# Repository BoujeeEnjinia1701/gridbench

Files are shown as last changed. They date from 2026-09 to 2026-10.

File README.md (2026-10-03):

# GridBench

     

**Area:** Advanced Manufacturing · **TRL:** 3 of 9 (proof of concept on paper) · **Value-engineering target:** USD 250 (estimated cost of the constructable design USD 272.20; see Concept) · **Difficulty:** 2 of 5

A modular fixture and workbench standard: a 25 mm hole grid plate with printable and machined clamps, stops and jigs, so community workshops can hold, assemble and test parts repeatably.

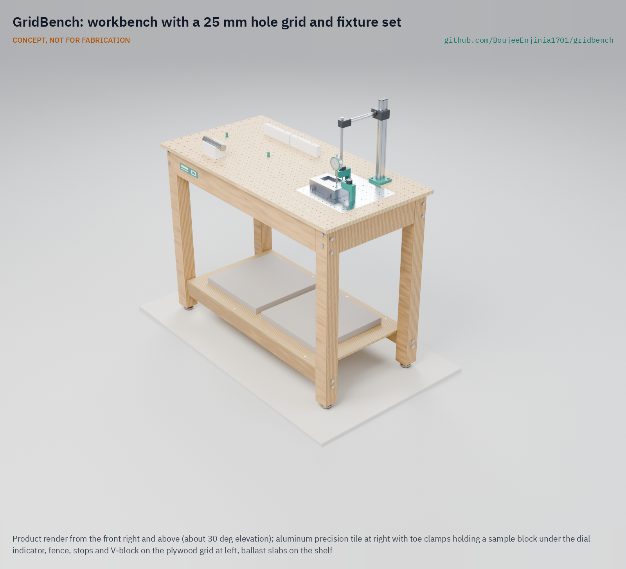
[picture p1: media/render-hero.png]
GridBench: workbench with a 25 mm hole grid and fixture set, product render


[Exploded render](media/render-exploded.png) · [Detail render](media/render-detail.png) · [Interactive 3D model](media/viewer.html) · [Concept blueprint (PDF)](media/concept-blueprint.pdf) · [General arrangement GBN-DWG-001 (PDF)](cad/drawings/GBN-DWG-001.pdf) · [Calculations](docs/04-calcs/01-sizing.md) · [Prototype build plan](docs/05-build-plan.md) · [Design decisions](docs/06-design-decisions.md) · [Review note](docs/REVIEW.md)

## Concept rationale

A shared grid lets jigs designed for one project be reused in any workshop, which is the manufacturing counterpart of the lab's documentation kit, ReadyKit. GridBench adopts the 25 mm, M6 pattern of metric optical breadboards ([RP Photonics](https://www.rp-photonics.com/optical_breadboards.html)) rather than inventing a new one, so commercial accessories fit from day one, and splits the top into a cheap plywood field for area and a small aluminum tile for precision, so precision is paid for only where it is used.

Keeping it open and garage-buildable is the point: a fixture standard only helps if many benches share it. A timber frame, one sheet of plywood, one aluminum plate and printed clamps can be built with a drill press and taps, and each jig can be published as a build123d file that fits any GridBench.

## Burning platform

Most making happens in small firms. Small and medium enterprises are about 90 % of businesses and more than half of employment worldwide ([World Bank](https://www.worldbank.org/ext/en/topic/competitiveness/small-and-medium-enterprises-smes-finance)), and in the United States more than 98 % of the roughly 239,000 manufacturing firms counted in 2022 had fewer than 500 employees ([National Association of Manufacturers, Facts About Manufacturing](https://nam.org/mfgdata/facts-about-manufacturing-expanded/)). These firms rarely own modular fixture systems: a 1,200 x 800 mm fixture table from one leading system starts at about $2,561 before clamps ([Siegmund System 16 listing](https://weldingtablesandfixtures.com/products/4-161025-p-siegmund-1200x800mm-basic-system-16-welding-table)).

Demand for local, repeatable making is rising with repair. The world generated a record 62 million tonnes of e-waste in 2022 and only 22 % was formally recycled ([ITU and UNITAR, Global E-waste Monitor 2024](https://www.itu.int/hub/2024/04/the-world-generated-62-million-tonnes-of-electronic-waste-in-just-one-year-and-recycled-way-too-little-un-agencies-warn/)), and repair and remanufacture depend on holding parts accurately without factory tooling.

## Where it could be used

### By industry

| Industry | Use |
| --- | --- |
| Makerspaces and fab labs | Shared bench where members set up a published jig in minutes; the Fab Lab network alone has over 1,750 labs in 100 countries ([Fab Foundation](https://fabfoundation.org/about/)) |
| Electronics and appliance repair | Holding boards, housings and motors for disassembly, rework and testing with the indicator post |
| Small-batch manufacturing | Drilling, gluing and assembly jigs for runs of 10 to 500 parts |
| Technical education | Teaching datums, location and clamping on a bench students can build |
| Open hardware and research labs | Build and check fixtures shipped with designs; optics and sensor setups on the M6 grid |
| Furniture and joinery | Stops and fences for repeat cuts and drilling on the plywood field |

### By country or region

| Country or region | Why it matters there |
| --- | --- |
| European Union | The repair directive must apply in member states by 31 July 2026, requiring producers to offer repair and spare parts ([European Commission](https://commission.europa.eu/law/law-topic/consumer-protection-law/directive-repair-goods_en)); independent repairers need low-cost, repeatable workholding. |
| United States | More than 98 % of manufacturing firms had fewer than 500 employees in 2022, and about three quarters had fewer than 20 ([National Association of Manufacturers](https://nam.org/mfgdata/facts-about-manufacturing-expanded/)); makerspaces and job shops can share jigs as files. |
| India | MSMEs account for 30.1 % of GDP and 35.4 % of manufacturing ([Press Information Bureau, 2025](https://www.pib.gov.in/PressReleasePage.aspx?PRID=2142170&reg=48&lang=2)); consistent quality helps small units supply larger buyers. |
| Ghana | Suame Magazine in Kumasi, an artisan engineering cluster, had over 80,000 people working in it by 2018 ([Adu-Gyamfi and Adjei, AfricaLics working paper](https://openair.africa/wp-content/uploads/2018/09/WP-16.pdf)); shared jigs could make artisan-made parts interchangeable. |
| Kenya | Informal sector employment grew 4.5 % in 2023, faster than formal wage employment at 4.1 % ([Kenya National Bureau of Statistics, Economic Survey 2024, popular version](https://www.knbs.or.ke/wp-content/uploads/2024/05/2024-Economic-Survey-Popular-Version.pdf)); jua kali workshops make parts with hand tools and could build the bench locally. |

## What sparked the idea

The idea traces back to Paris in 1785, when Thomas Jefferson, then the US minister to France, was shown the work of the gunsmith Honoré Blanc. Jefferson wrote to John Jay that he was handed the parts of 50 musket locks sorted into compartments, put several locks together himself from parts picked at random, and found that they fitted perfectly ([Jefferson to Jay, 30 August 1785, Founders Online](https://founders.archives.gov/documents/Jefferson/01-08-02-0354)). Jefferson added that Blanc achieved this "by tools of his own contrivance," which also shortened the work, and that the advantages when arms need repair were evident (same letter). Repeatability came from purpose-made tooling rather than from a large factory, which is still the situation of a small workshop today. What such workshops lack is a common base on which those fixtures can be shared, and GridBench is an attempt to supply one.

## Problem

Repeatable building needs repeatable fixturing, and commercial modular fixture systems are costly while improvised jigs are one-off. Problem statement: [docs/01-problem.md](docs/01-problem.md).

## Concept

A 1,200 x 600 mm workbench with a 25 mm, M6 hole grid: a plywood field with tee nuts and threaded inserts for general holding, a flush 300 x 300 mm aluminum precision tile with dowel bores for repeatable location, printed clamps, stops and V-blocks, and an instrument post with a user-supplied dial indicator to check parts in place. Two concrete slabs on the shelf keep it from tipping and rubber-padded feet keep it from sliding. The TRL 3 calculations ([GBN-CAL-001](docs/04-calcs/01-sizing.md)) find 7 of 12 requirements met on paper or by design. Value-engineering target: USD 250; estimated cost of the constructable design: USD 272.20 (USD 22.20 over the target). Clamp hold-down is met at the tee-nut positions and on the tile but not at the 122 screw-in insert positions over the frame; Amish decided on 2026-10-02 to rate those light duty at 0.92 N·m and mark them on the worktop with a contrasting paint ring, and the shelf is now screwed down to the low rails against racking. The recommendations Amish accepted on 2026-09-25 are recorded in [GBN-DDR-002](docs/decisions/0002-recommendations-accepted.md), and the changes that make the design buildable in [GBN-DDR-003](docs/decisions/0003-design-for-construction.md).

Full design precis: [docs/02-concept.md](docs/02-concept.md) · Requirements: [docs/03-requirements.md](docs/03-requirements.md) · Decisions: [DDR-001](docs/decisions/0001-trl2-review-decisions.md), [DDR-002](docs/decisions/0002-recommendations-accepted.md), [DDR-003](docs/decisions/0003-design-for-construction.md), [register](docs/06-design-decisions.md) · Model: [cad/src/model.py](cad/src/model.py)

## Key components

- Bolted timber bench frame (M8 bolts and cross dowels) with 45 x 120 mm aprons, rubber-padded levelling feet and a lower shelf
- 18 mm plywood grid worktop, 25 mm pitch, M6 flanged tee nuts (screw-in inserts over the frame) on a 50 mm sub-grid
- Aluminum precision tile, 300 x 300 mm, 144 M6 holes and 9 dowel bores 8 mm H7
- Hardened 8 mm locating pins, one round and one diamond per precision fixture
- Printable clamp, stop, fence and V-block library (every part fits a 200 x 200 mm print bed)
- Instrument post for a 0.01 mm dial indicator (user-supplied)
- Two concrete ballast slabs on the shelf; optional wall anchor brackets

The priced bill of materials (17 lines) is in [bom/bom.csv](bom/bom.csv).

## Building the prototype

The [prototype build plan](docs/05-build-plan.md) (GBN-BLD-001) shows how to make each of the 20 components and put the bench together in 15 steps, with a making sketch for every made part and a picture for every joint and step, all drawn from the model. The frame is sawn and drilled softwood joined with M8 bolts and cross dowels, the worktop is drilled plywood, the tile is drilled, reamed and tapped aluminium plate, and the fixtures are printed in PETG on a 200 x 200 mm bed. Making the design buildable changed some details of the concept, recorded in [GBN-DDR-003](docs/decisions/0003-design-for-construction.md); decisions still open are in the [design decisions register](docs/06-design-decisions.md). It is a plan: nothing has been built yet.

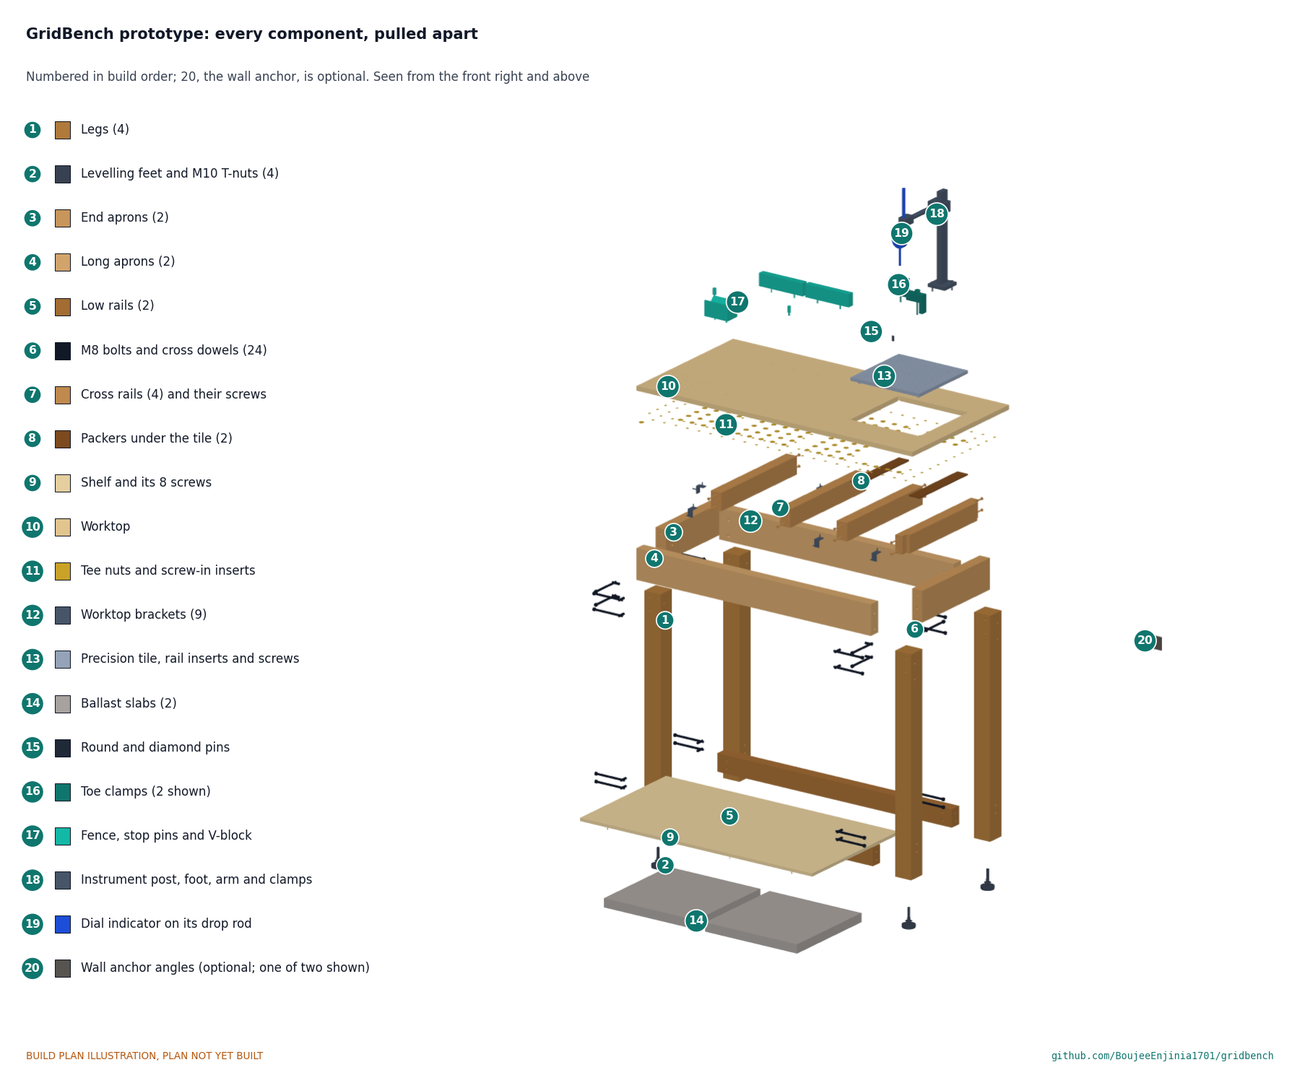
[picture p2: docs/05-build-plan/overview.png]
GridBench prototype: every component, pulled apart and numbered in build order


## Safety

> Drilling, tapping and clamping create chip, projectile and pinch hazards: wear eye protection and secure work before cutting. The empty bench tips at about 117 N at the top edge (estimate); place both ballast slabs on the shelf or anchor it to a wall before use. Printed clamps can crack under overload; respect the rated screw torque of 1.6 N·m. Not for welding or hot work.

## Repository layout

| Folder | Contents |
| --- | --- |
| `docs/` | Problem, concept, requirements, calculations and design decisions |
| `cad/src/` | build123d Python source, the source of truth for all geometry |
| `cad/step/`, `cad/stl/` | Exported models for FreeCAD, other CAD tools and printing |
| `cad/drawings/` | 2D sketches and dimensioned drawings |
| `bom/` | Bill of materials |
| `electronics/` | KiCad schematics and PCB layouts |
| `firmware/` | Microcontroller code |
| `media/` | Renders, perspectives and photos |
| `build-log/` | Dated prototyping notes |

## Documentation

Controlled documents follow the portfolio [documentation standard](.kit/STANDARDS.md). Each carries a document ID (GBN-PRC-001 for the precis), a version and a revision history. Branded PDFs are built with `python .kit/render.py` and attached to GitHub Releases when a document is tagged, for example `GBN-PRC-001/v1.0`.

## Credits

Designed by Amish Chadha. See [CONTRIBUTORS.md](CONTRIBUTORS.md) for roles. To cite this design, use [CITATION.cff](CITATION.cff) (GitHub shows it as "Cite this repository").

AI assistance (Claude) was used to accelerate concept renders, prototype documentation and first-pass sizing calculations. Design direction and all decisions are Amish Chadha's, recorded in this repository's decision records (`docs/decisions/`).

## Licenses

- **Hardware** (CAD, drawings, BOM, electronics): [CERN-OHL-S v2](LICENSE)
- **Software** (firmware, scripts, notebooks): [MIT](LICENSE-SOFTWARE)

A project of the [Design Molecule](https://designmolecule.com) lab.

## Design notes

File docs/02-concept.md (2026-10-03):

---
doc_id: GBN-PRC-001
title: GridBench design precis
project: GridBench
doc_type: Design precis
version: "0.7"
status: Draft
date: '2026-10-02'
author: Amish Chadha
license: CERN-OHL-S-2.0
revisions:
- version: "0.1"
  date: '2026-09-25'
  author: Amish Chadha
  change: Initial scaffold
- version: "0.2"
  date: '2026-09-25'
  author: Amish Chadha
  change: Populate to TRL 2 (architecture, components, first-order numbers, safety, open questions)
- version: "0.3"
  date: '2026-09-25'
  author: Amish Chadha
  change: TRL 3 update; design choices adopted as recommended (GBN-DDR-001); numbers from GBN-CAL-001; deeper clamp, diamond pin, split fence, ballast slabs; priced BOM
- version: "0.4"
  date: '2026-09-25'
  author: Amish Chadha
  change: Recommendations accepted by Amish (DDR-002)
- version: "0.5"
  date: '2026-10-01'
  author: Amish Chadha
  change: Design made constructable (GBN-DDR-003); mass, stability and cost updated; cost reported against the value-engineering target
- version: "0.7"
  date: '2026-10-02'
  author: Amish Chadha
  change: 'Decisions of 2026-10-02 carried in: light-duty rating at the screw-in positions, screwed-down shelf, first workshops for co-design'
- version: "0.7"
  date: '2026-10-02'
  author: Amish Chadha
  change: 'Fixture library notes with the light-duty rating; shelf screws and marking costed; safety note brought up to date'
---

# GridBench design precis

## Summary

GridBench is a 1,200 x 600 mm workbench whose top is a 25 mm hole grid with M6 threads, the same pattern as metric optical breadboards. A cheap plywood field covers most of the top for general holding, and a 300 x 300 mm aluminum precision tile, set flush on the same grid, carries work that must repeat to a few hundredths of a millimeter. Printed clamps, stops, fences and V-blocks bolt to either zone, and a post with a user-supplied dial indicator checks parts in place. Two concrete slabs on the shelf keep the bench from tipping, and rubber-padded feet keep it from sliding. Value-engineering target: USD 250. Estimated cost of the constructable design: USD 272.20 for the core parts (USD 22.20 over the target). The design was made buildable on 2026-10-01 (GBN-DDR-003): the frame members are bolted to the legs with cross dowels, the worktop is held by brackets and the tile by four screws, and every fixture sits on threaded grid positions; the prototype build plan is GBN-BLD-001. The parametric model is `cad/src/model.py`, the general arrangement is drawing GBN-DWG-001 and the calculations are GBN-CAL-001.

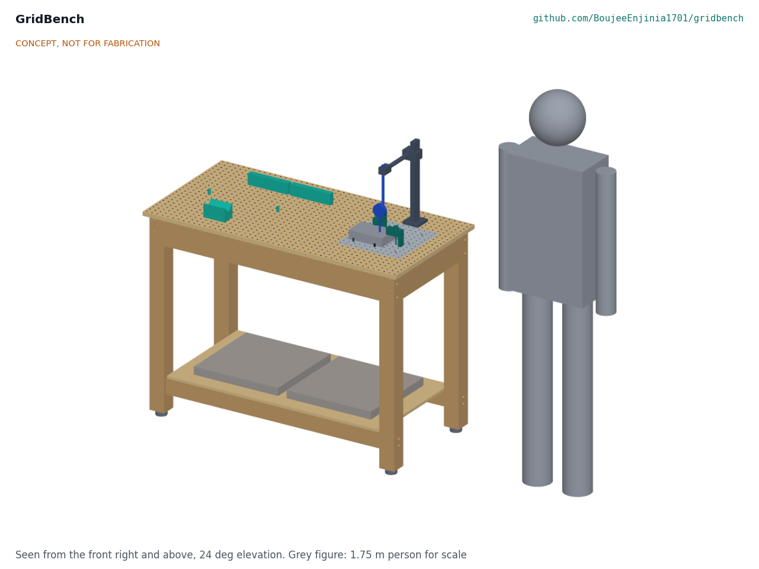
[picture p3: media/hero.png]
GridBench concept


Figure 1. GridBench with a 1.75 m person for scale. Concept, not for fabrication.

## How it works

1. **One grid everywhere.** Hole centers sit at 12.5 + 25k mm from the front-left corner of the worktop, in both directions. The tile's edges fall midway between grid lines, so its holes continue the plywood grid, a fixture can straddle both zones and any fixture file places itself by grid coordinates (column, row).
2. **Locate on dowels, clamp on threads.** As on machinist fixture plates, location and clamping are separate. On the tile, nine reamed 8 mm H7 bores at 100 mm pitch sit in the centers of grid squares, between the M6 holes. A precision fixture or part nest carries one round and one diamond (relieved) 8 mm h6 pin that drop into two bores, then M6 screws clamp it down. Two round pins would bind on any pitch error (GBN-CAL-001, section F). On the plywood field, 6.6 mm plain holes take stop pins, and M6 threads on a 50 mm sub-grid take clamps: flanged tee nuts pressed in from the underside wherever the underside is clear, and screw-in inserts where an apron, rail or leg lies below.
3. **Work and check in the same setup.** The instrument post bolts to any grid hole and carries a dial indicator on an arm, so a part can be checked before it is unclamped (Figure 3).
4. **Fixtures travel as files.** Each fixture is a parametric build123d part with a short metadata block that states its grid footprint and datum. A workshop that builds a GridBench can print or machine a published jig and expect it to fit. Jigs documented with the lab's ReadyKit toolchain can carry their own drawings and revision history.

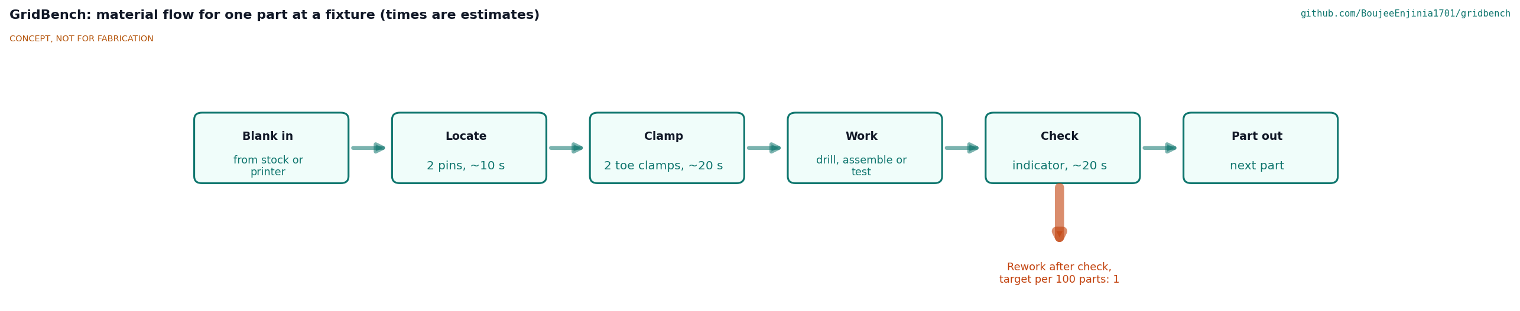
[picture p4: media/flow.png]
Material flow at a fixture


Figure 3. Material flow for one part at a fixture. Times and the rework rate are estimates or targets; the fixture change time is from GBN-CAL-001.

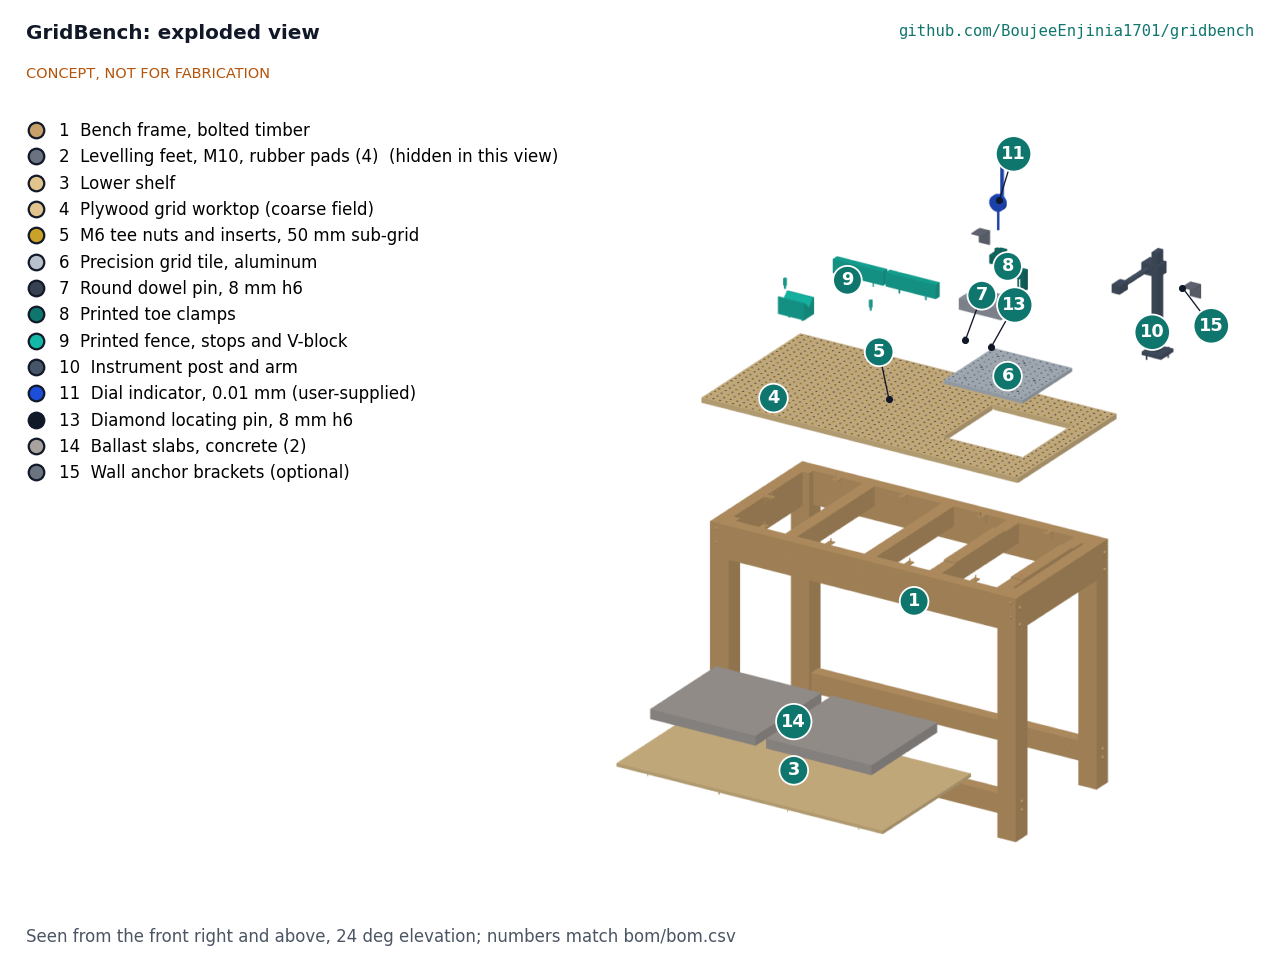
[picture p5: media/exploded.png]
Exploded view


Figure 2. Exploded view. Callout numbers match the lines in `bom/bom.csv`.

## Main components

Table 1. Main components (numbers match the BOM and Figure 2).

| No. | Component | Design |
| --- | --- | --- |
| 1 | Bench frame | Bolted softwood: four 70 x 70 mm legs at 1,090 x 490 mm centers, 45 x 120 mm aprons and two low rails butted between the legs on M8 bolts and cross dowels, four 45 x 70 mm cross rails (clear bays 255 mm or less), two 5.3 mm hardwood packers under the tile |
| 2 | Levelling feet | Four M10 feet in T-nuts with 3 mm rubber pads, ±15 mm adjustment |
| 3 | Lower shelf | 12 mm plywood, 1,010 x 535 mm, resting on the low rails; carries the ballast |
| 4 | Plywood grid worktop | 18 mm birch plywood, 1,200 x 600 mm, 1,008 holes on the 25 mm grid, 300 x 300 mm through pocket for the tile |
| 5 | M6 threaded inserts | 252 on the 50 mm sub-grid: 130 flanged tee nuts (19 mm flange, 9.5 mm barrel) pressed in from the underside, and 122 screw-in inserts (10 mm OD by 13 mm) where a frame member lies below |
| 6 | Precision grid tile | Cast aluminum tooling plate (offcut), 300 x 300 x 12.7 mm, 144 M6 tapped holes, 9 reamed 8 mm H7 bores, 4 counterbored fixing holes to the two cross rails |
| 7 | Round dowel pins | 8 mm h6 hardened pins, 20 mm long; one per precision fixture |
| 8 | Printed toe clamps | PETG, 70 x 24 x 30 mm body with a 6.6 mm slot and a heel, printed on its side; rated screw torque 1.6 N·m |
| 9 | Printed fence, stops and V-block | Fence in two 190 mm segments, each on two grid holes; stop pins for 6.6 mm holes; 90° V-block |
| 10 | Instrument post and arm | 20 x 40 mm aluminum extrusion on a printed grid foot, 18 mm arm |
| 11 | Dial indicator | 0.01 mm resolution, 10 mm travel, 8 mm stem; user-supplied |
| 12 | M6 fastener kit | Cap screws, washers and printed knobs (no callout) |
| 13 | Diamond locating pins | 8 mm h6 relieved pins; one per precision fixture, paired with a round pin |
| 14 | Ballast slabs | Two 400 x 400 x 35 mm concrete paving slabs, 12.9 kg each, on the shelf |
| 15 | Wall anchor brackets | Optional pair of steel angles from the rear apron to a wall |
| 16 | Tile machining tools | M6 taps, drills, 8 mm H7 reamer and a tapping guide (no callout) |

## Key numbers

All values are from GBN-CAL-001, where every assumption is stated. They are paper estimates, not test results.

Table 2. Key numbers.

| Quantity | Value | Note |
| --- | --- | --- |
| Grid positions | 1,152 (48 x 24): 144 on the tile, 252 inserts and 756 plain holes | 25 mm pitch, 12.5 mm edge offset |
| Bench mass | 43.8 kg empty; 69.6 kg with two ballast slabs | Densities in GBN-CAL-001, Table 1 |
| Tipping force at the top edge | 117 N empty; 186 N with the ballast (target 150 N) | Feet 245 mm from the center line, push at 900 mm |
| Deflection, 500 N at bay center | 0.19 mm in the plywood; 0.37 mm including rails and 45 x 120 mm aprons (target 0.5 mm) | Plate theory, E about 7 GPa, pinned joints |
| Plywood field moisture movement | ±0.115 mm over 1,000 mm at 40 to 60 % RH; ±0.40 mm over 20 to 80 % RH | Sourced moisture contents; plywood coefficient 0.007 % per % still unsourced |
| Tile thermal growth | 0.069 mm over 300 mm per 10 K | Aluminum, 23 x 10⁻⁶ /K |
| Dowel relocation | 0.036 mm worst case, 0.015 mm statistical (target 0.03 mm) | Round plus diamond pin, 200 mm apart |
| Clamp force at the part | 515 to 858 N at 1.6 N·m; body stress 9.9 MPa or less | M6, nut factor 0.15 to 0.25 |
| Tee nut pull-through | 2.69 to 4.30 kN against up to 1.78 kN of screw tension (130 positions) | Assumed shear strength; R7 met on paper |
| Screw-in insert pull-out | 1.02 to 1.63 kN against up to 1.78 kN (122 positions over the frame) | R7 not met there; rated light duty at 0.92 N·m and marked on the worktop (decided by Amish, 2026-10-02) |
| Sliding force, rubber pads | About 215 N empty, 341 N ballasted | μ = 0.5 assumed |
| Fixture change | 56 s (target 60 s) | Two screws out, two in |
| Tile machining | About 4.2 h by drill press with a tapping guide | 144 holes, 9 reamed bores, 4 counterbores |

## Key design choices

Each choice below is decided by Amish, 2026-09-25: go with recommendation (GBN-DDR-001, GBN-DDR-002).

1. **Grid: 25 mm, M6.** Matches metric optical breadboards, so commercial posts, clamps and bases fit ([RP Photonics, "Optical breadboards"](https://www.rp-photonics.com/optical_breadboards.html)). A heavy 50 mm variant is left for later.
2. **Two zones instead of one precise top.** A full aluminum top of 1,200 x 600 mm would cost several times the budget. Plywood gives area; the tile gives precision where it is needed.
3. **Inserts on a 50 mm sub-grid,** with the 25 mm holes kept for pins. Inserts at every plywood hole would add about $75 and a day of fitting.
4. **Bolted timber frame** for the prototype, with welded steel as a documented variant.
5. **PETG printed fixtures with steel where it matters.** Dowels, screws and the tile are metal; bodies are printed, with a machined option for heavily used jigs.
6. **Tile at the right of the worktop,** leaving the left 800 mm free for large parts.
7. **Ballast on the shelf plus an optional wall anchor,** for stability, and rubber pads on the feet against sliding.
8. **Fixture files carry a metadata block** stating grid footprint and datum; the fixture library stays under CERN-OHL-S-2.0.
9. **Tee nuts from below where the underside is clear,** so clamp load bears on the plywood instead of shearing it; screw-in inserts only over frame members.
10. **45 x 120 mm aprons,** giving the worktop a margin on R6 (0.37 mm against 0.5 mm).

Four details changed at TRL 3 because of GBN-CAL-001 v0.1, within these choices: the toe clamp body is 30 mm deep instead of 16 mm and its rated torque is 1.6 N·m instead of 2 N·m (the TRL 2 clamp would have carried about 33 MPa and crept); each precision fixture uses one round and one diamond pin; the fence is two 190 mm segments so that it fits a 200 mm print bed; and the ballast is two concrete slabs, 25.8 kg in all.

## Fixture library notes

These notes apply to every fixture published for GridBench.

- **Light-duty positions.** The 122 threaded positions that sit over a frame member use screw-in inserts, not tee nuts, and are rated light duty: tighten a toe clamp there to 0.92 N·m at most, which gives 296 to 493 N at the part (GBN-CAL-001 [G5e]). They are ringed on the worktop in a contrasting colour. Full clamping force (1.6 N·m, 515 to 858 N at the part) is for the tee-nut positions and the tile only.
- **Metadata.** Each fixture file states its grid footprint, its datum and the positions it screws into, so a user can see whether it lands on a light-duty position.

## Cost

Value-engineering target: USD 250 (`budget_usd`, a hypothetical control target, not a limit; Amish, 2026-10-01). Estimated cost of the constructable design: USD 272.20 for the core parts (USD 22.20 over the target), from the priced BOM (`bom/bom.csv`, 17 lines), with the dial indicator ($15.00) user-supplied and the wall anchor brackets ($5.00) optional; everything together is $292.20. The largest items are the frame ($57.00, of which $23.40 is bolts, cross dowels and screws), the plywood worktop ($45.00), the threaded inserts ($28.20) and the tile offcut ($28.00, unverified). The joints, fixings and clamps that make the design buildable (GBN-DDR-003) added $22.50 to the $245.90 of GBN-CAL-001 v0.2, and the shelf screws and light-duty marking decided on 2026-10-02 added $3.80. The main cost drivers and the savings worth trying are in the design decisions register (GBN-DEC-001).

## Safety

> **Safety:** Drilling, tapping and routing the worktop and tile create chips and projectiles: wear eye protection and clamp work before cutting. Clamps and toe clamps create pinch points; keep fingers clear when tightening. The empty bench tips at about 117 N at the top edge (GBN-CAL-001), below the 150 N design push, so place both ballast slabs on the shelf or anchor the bench to a wall before use, and lift each 13 kg slab with a straight back. Chamfer or round all plywood, tile and printed edges. Printed clamps can crack and release a part under load; do not exceed the rated screw torque of 1.6 N·m, and do not use printed clamps for machining with a milling machine. Screw-in inserts over the frame members may pull out before a clamp reaches its rated force; they are rated light duty at 0.92 N·m and ringed in a contrasting colour, so use the tee-nut positions or the tile for full clamping force. The bench is not for welding, grinding sparks or hot work: plywood and PETG are combustible.

## Open questions

- [x] R7 at the 122 screw-in positions over the frame: rated light duty at 0.92 N·m (296 to 493 N at the part), marked on the worktop in a contrasting colour and stated in the fixture library notes (GBN-DDR-002 O4; decided by Amish, 2026-10-02).
- [x] Racking stiffness: the shelf is screwed down to the low rails; a push test at TRL 4 decides whether end low rails are added (GBN-DDR-002 O3; decided by Amish, 2026-10-02).
- [x] First workshops for co-design: makerspaces or technical colleges that have a CNC router and teach fixturing; the first candidate to approach is a member lab of the Fab Lab network, and nothing is agreed (GBN-DDR-001 O1; decided by Amish, 2026-10-02).
- [ ] Can the tile be drilled to ±0.05 mm without CNC, using a printed or steel drill jig on a drill press? Not verifiable on paper.
- [ ] A sourced figure for plywood in-plane moisture movement; the moisture contents are now sourced, the coefficient is not.
- [ ] Flatness of cast tooling plate bought as offcut, and of the plywood sheet once screwed down (R5).

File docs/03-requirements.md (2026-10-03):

---
doc_id: GBN-REQ-001
title: GridBench requirements
project: GridBench
doc_type: Requirements
version: "0.7"
status: Draft
date: '2026-10-02'
author: Amish Chadha
license: CERN-OHL-S-2.0
revisions:
- version: "0.1"
  date: '2026-09-25'
  author: Amish Chadha
  change: Initial scaffold
- version: "0.2"
  date: '2026-09-25'
  author: Amish Chadha
  change: Populate to TRL 2 (12 measurable requirements, status against the concept)
- version: "0.3"
  date: '2026-09-25'
  author: Amish Chadha
  change: TRL 3 status from GBN-CAL-001; R10 redefined to exclude the user-supplied indicator and R12 assessed with ballast (GBN-DDR-001)
- version: "0.4"
  date: '2026-09-25'
  author: Amish Chadha
  change: Recommendations accepted by Amish (DDR-002)
- version: "0.5"
  date: '2026-10-01'
  author: Amish Chadha
  change: Design made constructable (GBN-DDR-003); R10 reported against the value-engineering target; R12 figures updated
- version: "0.7"
  date: '2026-10-02'
  author: Amish Chadha
  change: 'R7 note: light-duty rating and marking at the 122 screw-in positions decided by Amish on 2026-10-02; R7 unchanged'
- version: "0.7"
  date: '2026-10-02'
  author: Amish Chadha
  change: 'R10 figures after the shelf screws and light-duty marking (GBN-CAL-001 v0.4); no status change'
---

# GridBench requirements

Twelve requirements define a garage-built grid bench and fixture set. The TRL 3 calculations (GBN-CAL-001 v0.4) find one not met in part: clamp hold-down (R7) at the 122 insert positions that sit over a frame member, where a screw-in insert may pull out. Two are at risk (R3, R4), one cannot be verified on paper (R5), four are met on paper and three are met by design. R10 is reported against the value-engineering target (Amish, 2026-10-01): value-engineering target USD 250; estimated cost of the constructable design USD 272.20 (USD 22.20 over the target), after the joints, fixings and clamps that make the design buildable (GBN-DDR-003) and the shelf screws and light-duty marking decided on 2026-10-02. At v0.4, under GBN-DDR-002, the R10 target became $250, the `budget_usd` Amish set on 2026-09-25. At v0.3, under GBN-DDR-001, R10 was redefined to exclude the user-supplied dial indicator and R12 is assessed with the shelf ballast in place.

## Requirements

Table 1. GridBench requirements and TRL 3 status (GBN-CAL-001, Table 2).

| ID | Requirement | Target | Verification | TRL 3 status |
| --- | --- | --- | --- | --- |
| R1 | Grid standard | 25.00 mm pitch in X and Y, M6 threads, hole centers 12.5 mm from the worktop edges; fits metric optical breadboard accessories | Inspection of drawing; fit test with a commercial M6 accessory | Met by design: 1,152 positions, tile on the same grid |
| R2 | Worktop size and height | At least 1,200 x 600 mm; top at 900 mm, adjustable ±15 mm with levelling feet | Measurement | Met by design |
| R3 | Coarse field hole position | ±0.3 mm hole to hole over 1,000 mm at 40 to 60 % RH (template-drilled build: ±0.5 mm) | Measurement with steel rule and pin gauges | **At risk:** CNC ±0.22 mm; template ±0.34 mm statistical, ±0.62 mm worst case; moisture coefficient unsourced |
| R4 | Precision tile location | Hole position ±0.05 mm; a part relocated on two 8 mm dowels (one round, one diamond) returns within 0.03 mm | Dial indicator test, 10 relocations | **At risk:** 0.036 mm worst case, 0.015 mm statistical; hole position not verifiable at TRL 3 |
| R5 | Flatness | Tile 0.05 mm over 300 mm; worktop 0.5 mm over 1,000 mm | Straightedge and feeler gauges | Not verifiable at TRL 3 (depends on the plate and sheet as supplied) |
| R6 | Stiffness and load | 150 kg distributed load; deflection 0.5 mm or less under 500 N at the middle of a bay | Load test | Met on paper: 0.37 mm with 45 x 120 mm aprons; 150 kg at a sixteenth of the timber strength |
| R7 | Clamp hold-down | Each printed toe clamp holds 500 N at the part with no visible creep after 8 h at 25 °C | Spring scale pull test | **Not met at the 122 screw-in positions over the frame** (pull-out factor 0.57 to 0.92); met on paper at the 130 tee-nut positions (factor 1.51 to 2.42) and on the tile (515 to 858 N at 1.6 N·m, 9.9 MPa) |
| R8 | Fixture change | Swap one fixture for another in 60 s or less with one 5 mm hex key | Timed trial | Met on paper: 56 s (thin margin) |
| R9 | Buildability | Built with hand and garage tools plus an FDM printer (200 x 200 mm bed); CNC optional | Build review | Met on paper: largest print 190 mm; tile about 4.2 h by drill press |
| R10 | Parts cost | Value-engineering target USD 250 (`budget_usd`, a hypothetical control target) for bench, grid, tile and fixture set; the dial indicator is user-supplied and excluded (GBN-DDR-001 A1) | Priced BOM | Over the value-engineering target by $22.20: $272.20 for the constructable design (GBN-DDR-003, decisions of 2026-10-02) |
| R11 | Openness | All geometry as build123d source; fixture library parametric; CERN-OHL-S-2.0 | Repository review | Met by design |
| R12 | Stability and edges | No tipping under 150 N horizontal at the top edge, with the shelf ballast in place; all exposed edges chamfered or rounded 0.5 mm or more | Push test; inspection | Met on paper with 25.8 kg of ballast (186 N); the empty bench tips at 117 N |

## Design load case

- Distributed load: 150 kg over the worktop (a fixture set, tools and parts).
- Point load: 500 N from a person leaning on a clamped part, at the middle of a bay between cross rails.
- Horizontal push: 150 N at the front edge of the worktop, as when pushing a tight part onto dowels or filing.

## Assumptions

- Birch plywood with a modulus of about 7 GPa, mean of the two in-plane directions (still an assumption; GBN-CAL-001, Table 1).
- C16 softwood frame at about 500 kg/m³, mean modulus 8 GPa.
- Workshop humidity between 40 and 60 % RH for R3, a moisture content swing of ±1.65 % (USDA *Wood Handbook*, Table 4-2).

## Requirements not met

- **R7 clamp hold-down at the 122 screw-in positions over the frame:** the screw tension that guarantees 500 N at the part can exceed the estimated pull-out strength of a screw-in insert. Tee nuts, decided under GBN-DDR-002, cannot be fitted there because a frame member blocks the underside. Decided by Amish on 2026-10-02 (GBN-DDR-002, O4): these positions are rated light duty at 0.92 N·m (296 to 493 N at the part), marked on the worktop in a contrasting colour and stated in the fixture library notes. R7 itself is unchanged and stays not met at these positions.
- **R3 and R4 at risk:** see GBN-CAL-001, sections E and F. The precision tile carries all tight-tolerance work.

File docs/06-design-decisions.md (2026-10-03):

---
doc_id: GBN-DEC-001
title: GridBench design decisions register
project: GridBench
doc_type: Design decisions register
version: "0.3"
status: Draft
date: '2026-10-02'
author: Amish Chadha
license: CERN-OHL-S-2.0
revisions:
- version: "0.1"
  date: '2026-10-01'
  author: Amish Chadha
  change: Register opened with the open decisions, items to confirm, value engineering and decisions made to date
- version: "0.2"
  date: '2026-10-02'
  author: Amish Chadha
  change: 'Amish approved the recommendations for all seven open decisions (2026-10-02); GBN-DDR-003 accepted; moved to decisions made; plain-hole saving withdrawn from value engineering'
- version: "0.3"
  date: '2026-10-02'
  author: Amish Chadha
  change: 'Value engineering updated for the shelf screws and light-duty marking added to carry out decisions 2 and 3'
---

# GridBench design decisions register

Every design decision still to be made, and every decision made, in one place. Each decision is argued in full in its decision record under `docs/decisions/`; this register is the index Amish works from. The build plan (`docs/05-build-plan.md`, GBN-BLD-001) describes the design as it stands and does not list open decisions.

## Open decisions

None. All open decisions were decided on 2026-10-02.

The fourth appearance item of 2026-09-26, the toe clamp screws on tile holes, is settled by GBN-DDR-003: the model now puts them there too.

## To confirm when parts are bought

*Table 2. Items to confirm.*

| # | What to confirm | Why it matters | Source |
| --- | --- | --- | --- |
| 1 | The tile offcut's real thickness, flatness and price | The packers are planed to suit its thickness; R5 depends on its flatness; the USD 28 price is unverified | GBN-CAL-001; BOM line 6 |
| 2 | The plywood's real thickness | Packer thickness and the 15 to 18 mm screw reach below the surface both assume 18 | GBN-DDR-003, P6 and P9 |
| 3 | The tee nut's flange (19), barrel (9.5) and hole size (8.0), and the screw-in insert's hole size (8.5) | The worktop is drilled to these sizes before the parts can be tried | BOM line 5 |
| 4 | The M8 cross dowel's diameter (10) and the bolt length (120) | They set the cross dowel holes and how far the bolt reaches into the member | GBN-DDR-003, P1 |
| 5 | The levelling foot thread and the T-nut's barrel size | They set the 12 mm bore in the leg end | GBN-DDR-003, P8 |
| 6 | The 20 x 40 extrusion's core hole size | The post is held by M5 screws tapped into its core holes | GBN-DDR-003, P10 |
| 7 | A sourced figure for plywood in-plane moisture movement | R3 uses an unsourced 0.007 % per % moisture content | GBN-CAL-001 [E2] |
| 8 | Whether the tile can be drilled to ±0.05 without CNC, with a drilling jig on a drill press | R4 hole position cannot be verified on paper | GBN-PRC-001, Open questions |

## Value engineering

Value-engineering target: USD 250 (a hypothetical control target, not a limit). Estimated cost of the constructable design: USD 272.20 (USD 22.20 over the target) for the core parts, from `bom/bom.csv` [K3], [K4]; with the user-supplied dial indicator and the optional wall anchor, USD 292.20. The shelf screws and the paint marker for the light-duty rings, added on 2026-10-02 to carry out decisions 2 and 3, cost USD 3.80 [K2c]. Main cost drivers and savings worth trying:

- **Frame, USD 57.00.** About USD 33.60 of timber and USD 23.40 of bolts, cross dowels and screws [K2]. Worth trying: one bolt instead of two at each low rail end (about USD 3.20); bolts and cross dowels bought as a bulk furniture-fitting pack; or a glued and screwed frame (about USD 15 less, but it no longer comes apart).
- **Worktop, USD 45.00.** A half sheet of birch plywood plus router wear. Worth trying: a full sheet shared with the shelf, or a cheaper sheet faced only on the top.
- **Threaded inserts, USD 28.20.** Worth trying: a bulk price for tee nuts and inserts. (The earlier idea of leaving the 122 screw-in positions as plain holes is withdrawn: their light-duty rating, decided on 2026-10-02, depends on the inserts being there.)
- **Precision tile, USD 28.00.** An unverified offcut price. Worth trying: offcut dealers' minimum-cut prices; a 250 x 250 tile if the fixture library allows.
- **Instrument post and arm, USD 15.00, and fastener kit, USD 14.00.** Worth trying: steel bar and screws from bulk stock.

## Decisions made

*Table 3. Decisions made.*

| Date | Decision | Decided by | Record |
| --- | --- | --- | --- |
| 2026-09-25 | TRL 2 review items A1 to A10: cost options (dial indicator user-supplied, tile as an offcut), 25 mm M6 grid, two zones, 50 mm insert sub-grid, bolted timber frame, printed PETG fixtures, ballast plus optional wall anchor, fixture metadata block, CERN-OHL-S-2.0 fixture library, tile at the right | Amish: "i accept all your recommendations, go with them across all repos." | GBN-DDR-001, GBN-DDR-002 |
| 2026-09-25 | `budget_usd` raised from USD 220 to USD 250 (O2) | Amish, same instruction | GBN-DDR-002 |
| 2026-09-25 | Flanged tee nuts from the underside, screw-in inserts only over the frame (D1); 45 x 120 mm aprons (D2); rubber-padded feet (D3) | Amish, same instruction | GBN-DDR-002 |
| 2026-09-30 | Build plan format approved; outstanding decisions kept in this register, not the build plan; the design to be made physically buildable as the pictures are drawn | Amish: "this is the correct build plan ... this is a good quality document format. Extend this across all the other repos"; "If you are realising that the design cannot be built as per concept - fix the design assumptions to match and be physically feasible as you draw the illustrations." | GBN-BLD-001, GBN-DDR-003 |
| 2026-10-01 | `budget_usd` is a hypothetical value-engineering target, not a limit; cost is reported as over or under it | Amish: "the budgets are a hypothethical control target to ensure we are thinking along a value engineering lens. its ok to ensure wording reflects that the hypothesis budget was x - the real cost being accrued is y" | This register, Value engineering |
| 2026-10-02 | Design for construction accepted as recorded: the bolt and cross dowel frame joints, notched rail, shorter shelf, worktop brackets, tile pocket and fixing, T-nuts, fixtures on threaded positions, arm clamps and wall anchor | Amish: "i approve your recommendations for all 555 open decisions." | GBN-DDR-003 |
| 2026-10-02 | Clamp rating: the 122 screw-in positions over the frame are rated light duty at 0.92 N·m (296 to 493 N at the part), marked on the worktop in a contrasting colour, and the rating is stated in the fixture library notes | Amish: "i approve your recommendations for all 555 open decisions." | GBN-DDR-002, O4; GBN-CAL-001 [G5e] |
| 2026-10-02 | Racking: the shelf is screwed down to the low rails now; the frame is push-tested at TRL 4, and end low rails are added only if it still sways | Amish: "i approve your recommendations for all 555 open decisions." | GBN-DDR-002, O3 |
| 2026-10-02 | First workshops for co-design: makerspaces or technical colleges that have a CNC router and teach fixturing; first candidate to approach, a member lab of the Fab Lab network | Amish: "i approve your recommendations for all 555 open decisions." | GBN-DDR-001, O1 |
| 2026-10-02 | Wall anchor angles: left out of the renders and kept in the model, drawing and BOM | Amish: "i approve your recommendations for all 555 open decisions." | `docs/REVIEW.md`, 2026-09-26, item 2 |
| 2026-10-02 | Hole pattern: the split is kept, with the full pattern in the renders and a representative patch in the exported CAD | Amish: "i approve your recommendations for all 555 open decisions." | `docs/REVIEW.md`, 2026-09-26, item 3 |
| 2026-10-02 | Appearance-only details (index ticks, name plate, bolt heads, knobs, sample block and bar): render detail only | Amish: "i approve your recommendations for all 555 open decisions." | `docs/REVIEW.md`, 2026-09-26, item 4 |

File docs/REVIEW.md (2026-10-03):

# Review note: GridBench

## Session 2026-09-25: /populate to a strong TRL 2

### What was done

- `docs/01-problem.md` (GBN-PRB-001 v0.2): problem, users, operating environment, constraints, cited prior work (optical breadboards, fixture tables, machinist fixture plates, MFT tables, Gridfinity and Multiboard), out of scope, a new co-design checklist and open questions.
- `docs/03-requirements.md` (GBN-REQ-001 v0.2): 12 measurable requirements (R1 to R12) with targets, verification method and concept status, a design load case and assumptions.
- `docs/02-concept.md` (GBN-PRC-001 v0.2): how it works, 12 numbered components, first-order numbers with assumptions, six key design choices, cost and options, safety, open questions; hero, exploded and flow figures.
- `cad/src/concept_media.py`: massing model of the bench (timber frame, feet, shelf, plywood worktop with the full 25 mm hole pattern, inserts, aluminum tile with M6 holes and dowel bores, dowel pins, toe clamps, fence, stops, V-block, instrument post and dial indicator, and an example workpiece); 1.75 m scale figure.
- `media/`: `hero.png`, `concept-blueprint.png`, `.pdf` and `.svg`, `exploded.png` with BOM callouts 1 to 11, `flow.png` (material flow for one part at a fixture), `model.glb` and `viewer.html`. No cutaway: the worktop is solid plywood with the tile flush in a pocket, so a section adds little.
- `bom/bom.csv`: 12 lines with indicative prices, numbered to match the exploded view (line 12, fasteners, has no callout); `bom/bom-notes.md` updated.
- `README.md`: hero image and links line, and the Concept rationale, Burning platform, Where it could be used (6 industries, 5 regions), What sparked the idea, Problem, Concept, Key components and Safety sections expanded with cited sources.
- `docs/pdf/`: branded PDFs of the three controlled documents.

Notes on the model: the roughly 1,300 holes are drawn as thin dark disks on the surface rather than cut, and are left out of the blueprint's hidden-line views, because cutting and projecting them ran out of memory. The hero, exploded view and 3D model show them.

### Key results (estimates, to be checked at TRL 3)

| Quantity | Estimate | Requirement |
| --- | --- | --- |
| Grid | 25 mm, M6, 1,152 positions (144 on tile, 252 inserts, 756 plain holes) | R1 met by design |
| Worktop | 1,200 x 600 mm at 900 mm, ±15 mm feet | R2 met |
| Bench mass | About 40 kg | |
| Deflection, 500 N mid-bay | About 0.3 to 0.4 mm | R6 met by estimate |
| Dowel relocation | About 0.03 mm (8 mm h6 in H7) | R4 unverified |
| Plywood moisture movement | Up to about 0.4 mm over 1,200 mm (unsourced estimate) | **R3 at risk** |
| Clamp force at 2 N·m | About 0.8 kN | R7 unverified (PETG creep) |
| Tipping force at top edge | About 105 N empty, about 160 N with 20 kg on the shelf | **R12 not met without ballast** |
| Parts cost | About $239 | **R10 not met, about 9 % over $220** |

Requirements not met or at risk:

- **R10 cost not met:** about $239 against $220.
- **R12 stability not met** for the empty bench (about 105 N against 150 N); met with about 20 kg of ballast or a wall anchor.
- **R3 at risk:** plywood moves with humidity; the moisture coefficient used is an estimate without a source and must be confirmed.
- **R4, R5 (worktop), R7 unverified:** they depend on machining access, plywood flatness and PETG creep.

### Proposed, awaiting Amish

Update: items 1 to 8 are Decided by Amish, 2026-09-25: go with recommendation (GBN-DDR-001 v0.2, GBN-DDR-002); item 9 has no recommendation and stays Proposed, awaiting Amish.

1. **Budget.** Options: (a) dial indicator user-supplied, about $224; (b) also buy the tile as offcut stock, about $214 (price unverified); (c) raise `budget_usd` to $250. Recommendation: (a) plus (b), (c) as fallback. `project.yaml` is unchanged.
2. **Grid standard:** 25 mm, M6 (optical breadboard compatible) versus 50 mm, M8 or 16 mm bores. Recommendation: 25 mm, M6, with a heavy variant considered later.
3. **Two zones** (plywood field plus aluminum tile) versus an all-plywood or all-aluminum top. Recommendation: two zones.
4. **Inserts on a 50 mm sub-grid** versus every hole. Recommendation: 50 mm.
5. **Frame:** bolted timber versus welded steel. Recommendation: timber for the prototype.
6. **Fixture bodies:** printed PETG with metal dowels and screws versus machined. Recommendation: printed, with a machined option.
7. **Stability fix:** ballast on the shelf, wall anchor or wider splayed feet. Recommendation: ballast shelf plus an optional anchor bracket.
8. **Fixture file convention** (a metadata block giving footprint and datum) and the **fixture library license** (CERN-OHL-S-2.0 or permissive). Recommendation: metadata block; keep CERN-OHL-S-2.0 unless adoption by commercial jig makers is a goal.
9. **First workshops and regions** for co-design.

### Safety concerns

- Chips and projectiles when drilling, tapping and routing the worktop and tile; eye protection and clamped work.
- Pinch points at clamps.
- Tipping of the empty bench under a firm push (estimate about 105 N).
- Printed clamps cracking under overload and releasing a part; torque limit of 2 N·m proposed.
- Combustible top and fixtures: not for welding, grinding sparks or hot work.

### Problems and notes

- WebSearch budget ran out before a source for plywood in-plane moisture movement was found; the figure in the precis is flagged as unsourced.
- Sibling projects: none of the shared components (FieldNode, CellGuard, MotionCore, ThermaCart, TwinKit) applies. ReadyKit is referenced as the documentation counterpart only; there is no technical dependency.
- The legacy `cad/src/model.py` placeholder is untouched (TRL 3 work).

### Recommended next step

Review the media and this note, then decide items 1 and 2. If approved, run `/advance-trl3` to check deflection, tipping, clamp and insert loads and moisture movement by calculation, and to produce the parametric model, a tile drawing sheet and a fully priced BOM.

## Session 2026-09-25: TRL 3

On 2026-09-25 Amish asked for this batch of repos to be taken through the usual process with the instruction "you know the drill, nothing gets past TRL 3". He has not reviewed this repo's TRL 2 items one by one, so every item with a recommendation is adopted as recommended for TRL 3 under that instruction, open for his review. This session ran `/advance-trl3` on that basis and stopped at TRL 3.

### What was done

- `docs/decisions/0001-trl2-review-decisions.md` (GBN-DDR-001 v0.1, status proposed): items A1 to A10 adopted as recommended for TRL 3 under Amish's 2026-09-25 instruction, open for his review; items O1 and O2 left "Proposed, awaiting Amish".
- `docs/04-calcs/01-sizing.md` (GBN-CAL-001 v0.1) and `docs/04-calcs/sizing.py`: grid geometry, mass, tipping and sliding, worktop and frame stiffness, moisture and thermal movement, dowel location, clamp stress and insert pull-out, fixture change time, buildability, timber and cost, with a status for every requirement. The script imports the model's parameters and reads the BOM and `project.yaml`; every number in the note is printed by it (also written to `docs/04-calcs/sizing-output.txt`).
- `cad/src/model.py`: parametric build123d model (frame, feet, shelf, worktop with tile pocket, inserts, tile with all 144 M6 holes, 9 dowel bores and 4 counterbored fixing holes, round and diamond pins, toe clamps, fence, stops, V-block, post, indicator, ballast slabs, anchor brackets). Exports `cad/step/` and `cad/stl/` for `gridbench-assembly`, `precision-tile` and `worktop`. To keep the repo small, the worktop carries a representative 8 x 8 patch of its 1,008 holes; the full pattern is defined by `grid_points()` and drawn as surface marks in the media. `cad/` is about 5 MB.
- `cad/src/sheets.py` and `cad/drawings/GBN-DWG-001.svg`, `.pdf`, `.png`: general arrangement at Rev P1, 1:20, with a 1:5 tile detail, marked "CONCEPT, NOT FOR FABRICATION" and "PRELIMINARY, NOT FOR FABRICATION". GBN-DWG-001 was free because the concept blueprint is GBN-DWG-010.
- `bom/bom.csv` (16 lines, all priced with a supplier type) and `bom/bom-notes.md`.
- `cad/src/concept_media.py` now builds from the model; all of `media/` was re-rendered and every image checked. Project-side wrappers (the kit is unchanged) keep the hole marks out of the blueprint projection, as at TRL 2, and out of the web model, and export the glTF at a coarser tessellation after clearing the render meshes: `model.glb` fell from 10.8 MB to 1.3 MB. No cutaway is made (`cut=False`, as at TRL 2), so the kit's cutaway limitation does not arise.
- GBN-PRB-001, GBN-PRC-001 and GBN-REQ-001 revised to v0.3; `README.md` and `project.yaml` (`trl: 3`, `trl_target: 3`, evidence list) updated; PDFs rebuilt in `docs/pdf/`.

Detail changes found necessary by the calculations, within the adopted choices: the toe clamp body is 30 mm deep instead of 16 mm and the rated torque 1.6 N·m instead of 2 N·m (the TRL 2 clamp would have carried about 33 MPa in PETG); each precision fixture uses one round and one diamond pin (two round pins can bind on pitch error); the fence is two 190 mm segments (the 400 mm fence did not fit a 200 mm bed); the ballast is two 12.9 kg concrete slabs; the shelf is 535 mm deep so it actually rests on the low rails (the TRL 2 model's shelf ended at their inner faces); and two 5.3 mm packers seat the tile flush on its cross rails.

### Requirement status (GBN-CAL-001, Table 2)

2 not met, 2 at risk, 1 not verifiable at TRL 3, 4 met on paper, 3 met by design.

| ID | Status | Key number |
| --- | --- | --- |
| R10 Parts cost | **Not met** at $220 | Core parts $239.20 (+8.7 %); met under the $250 fallback (-4.3 %); $259.20 with indicator and anchor |
| R7 Clamp hold-down | **Not met** on the plywood field | Insert pull-out 1.02 to 1.63 kN against up to 1.78 kN of screw tension (factor 0.57 to 0.92); on the tile, 515 to 858 N at the part, 9.9 MPa in the clamp |
| R3 Coarse field accuracy | At risk | CNC ±0.22 mm (target 0.3); template ±0.34 mm statistical, ±0.62 mm worst case (target 0.5); moisture coefficient unsourced |
| R4 Tile location | At risk | Relocation 0.036 mm worst case, 0.015 mm statistical (target 0.03); hole position not verifiable |
| R5 Flatness | Not verifiable at TRL 3 | Depends on the plate and sheet as supplied |
| R6, R8, R9, R12 | Met on paper | 0.49 mm under 500 N (target 0.5); 56 s fixture change (target 60); largest print 190 mm; 176 N with ballast (107 N empty) |
| R1, R2, R11 | Met by design | 1,152 grid positions, tile on grid; 1,200 x 600 mm at 900 ±15 mm; open source |

Key numbers: bench 40.2 kg (65.9 kg ballasted); tile 3.0 kg, 0.061 mm under 500 N; plywood field ±0.115 mm over 1,000 mm at 40 to 60 % RH; tile machining about 4.2 h by drill press.

### Decisions recorded (GBN-DDR-001)

Decided by Amish, 2026-09-25: go with recommendation (first adopted for TRL 3, open for his review): A1 cost options (a) and (b), indicator user-supplied and tile as offcut, with R10 redefined to exclude the indicator; A2 25 mm, M6 grid; A3 two zones; A4 inserts on the 50 mm sub-grid; A5 bolted timber frame; A6 printed PETG fixtures with a machined option; A7 ballast shelf plus optional wall anchor; A8 fixture metadata block; A9 fixture library stays CERN-OHL-S-2.0; A10 tile at the right of the worktop. `budget_usd` is unchanged at $220. No pitch or problem rewording was recommended, so none was applied.

### Still awaiting Amish

Update: items 2 and 3 (option a) and the apron and rubber-pad suggestions in item 4 are Decided by Amish, 2026-09-25: go with recommendation (GBN-DDR-002). Item 1 and the racking suggestion in item 4 stay Proposed, awaiting Amish.

1. **O1, first workshops and regions for co-design.** No recommendation was made; none is chosen.
2. **O2, `budget_usd` of $250** (TRL 2 cost option c). Recommended at TRL 2 as the fallback; GBN-CAL-001 shows it is now needed for R10. Not applied.
3. **New, R7 on the plywood field.** Options: (a) flanged tee nuts pressed in from the underside, so clamp load bears on the plywood instead of shearing it (not yet priced; positions over rails would keep a screw-in insert); (b) a lower rated torque on the plywood field (1.2 N·m), accepting about 390 N at the part at the high nut factor; (c) keep screw-in inserts and relax R7 to 500 N on the tile only. Recommendation: (a). Not applied.
4. **Suggestions only, not in the repo:** 45 x 120 mm aprons would take R6 from 0.49 mm to 0.37 mm for a few dollars more timber (not priced); rubber pads on the feet would raise the sliding force of the empty bench from about 79 N; end low rails or a screwed-down shelf would add racking stiffness, which no requirement covers yet.

### Safety concerns

- Tipping: the empty bench tips at about 107 N at the front edge, below the 150 N design push. The slabs or the wall anchor must be in place before use; each slab is about 13 kg to lift.
- Clamp and insert failure: an overtightened clamp can pull an insert out of the plywood or crack a printed clamp and release a part. The 1.6 N·m limit needs to be marked on the clamps.
- Chips, projectiles and pinch points when drilling, tapping and routing, and at clamps; eye protection and clamped work.
- Combustible top and fixtures: not for welding, grinding sparks or hot work.

### Gaps and notes

- Citations: WebFetch on 2026-09-25 verified the equilibrium moisture contents (USDA *Wood Handbook*, FPL-GTR-190, Table 4-2: 4.5, 7.7, 11.0 and 16.0 % at 20, 40, 60 and 80 % RH, 21 °C) and they are now cited. No source for plywood in-plane moisture movement was found in *Wood Handbook* chapters 11, 12 and 13 or in Wikipedia; the 0.007 % per % figure stays flagged as unsourced. WebSearch was unavailable. The tile offcut price and the cast plate flatness (R5) are also unverified.
- Assumptions that only tests can settle: insert pull-out strength, PETG creep at 10 MPa, plywood modulus, and the moisture coefficient.
- Drawing: the 1:20 views are small on an ANSI B sheet; the tile detail at 1:5 carries the grid dimensions.
- Existing material beyond TRL 3: `build-log/README.md` (scaffold) is present, untouched and not extended. No test, build or firmware material exists.

### Recommended next step

TRL 4 is on hold by Amish's instruction; this repo stops at TRL 3. Amish's review is needed on O2 (the $250 budget) and on the R7 insert options above; O1 stays open. For the record only, TRL 4 would need: a built bench and tile; a lab test report (TST, `environment: lab`) of tipping force with and without ballast, deflection under 500 N, insert and clamp pull tests with 8 h creep, tile hole position and flatness, dowel relocation over 10 cycles, and hole position over 1,000 mm at two humidities; and build log entries. None of this has been started.

## Session 2026-09-25: recommendations accepted

On 2026-09-25 Amish wrote, in chat: "i accept all your recommendations, go with them across all repos." Every item with a recommendation is now **Decided by Amish, 2026-09-25: go with recommendation**, and is recorded in `docs/decisions/0002-recommendations-accepted.md` (GBN-DDR-002 v0.1). Items without a recommendation stay open.

### Decisions applied and what changed

| Item | Decision | Before | After |
| --- | --- | --- | --- |
| A1 to A10 (DDR-001) | Cost options, grid, zones, insert spacing, frame, fixture bodies, stability, file convention, license, tile position | Adopted for TRL 3, open for review | Decided; status wording in DDR-001 v0.2, PRB-001 and PRC-001 updated |
| O2 budget | Raise `budget_usd` | $220 | $250; R10 target $250 |
| R7 option (a) | Flanged M6 tee nuts pressed in from the underside; screw-in inserts where a frame member lies below | 252 screw-in inserts, pull-out factor 0.57 to 0.92 | 130 tee nuts (factor 1.51 to 2.42) and 122 screw-in inserts; BOM line 5 $25.20 to $27.80 |
| Deeper aprons (TRL 3 suggestion) | 45 x 120 mm aprons | 45 x 95 mm, 0.49 mm under 500 N | 0.37 mm; frame $41.40 to $43.50; bench 40.2 kg to 41.9 kg |
| Rubber pads (TRL 3 suggestion) | Rubber pads on the levelling feet | Empty bench slides at about 79 N (hard feet) | About 206 N empty, 332 N ballasted; feet $2.00 to $2.50 each |

Knock-on figures: tipping 107 N to 112 N empty and 176 N to 181 N with ballast; core parts $239.20 to $245.90 ($4.10 under $250).

Files changed: `project.yaml` (budget, evidence), `README.md`, `docs/01-problem.md` (GBN-PRB-001 v0.4), `docs/02-concept.md` (GBN-PRC-001 v0.4), `docs/03-requirements.md` (GBN-REQ-001 v0.4), `docs/04-calcs/01-sizing.md` (GBN-CAL-001 v0.2) and `sizing.py`, `docs/decisions/0001-trl2-review-decisions.md` (GBN-DDR-001 v0.2), `bom/bom.csv` and `bom-notes.md`, `cad/src/model.py` (STEP and STL re-exported), `cad/src/sheets.py` (GBN-DWG-001 Rev P1 to P2), `cad/src/concept_media.py` (all of `media/` re-rendered and checked), and all PDFs in `docs/pdf/`. The README "What sparked the idea" section was rewritten around Honoré Blanc's hand-filed interchangeable musket locks as reported by Jefferson in 1785, and the footer line about gap-filling areas was removed.

### Requirement status (GBN-CAL-001 v0.2)

1 not met in part, 2 at risk, 1 not verifiable at TRL 3, 5 met on paper, 3 met by design.

| ID | Status | Key number |
| --- | --- | --- |
| R7 Clamp hold-down | **Not met** at the 122 screw-in positions over the frame | Pull-out factor 0.57 to 0.92 there; tee nuts 1.51 to 2.42 at 130 positions; tile met on paper |
| R3 Coarse field accuracy | At risk | Template ±0.34 mm statistical, ±0.62 mm worst case; moisture coefficient unsourced |
| R4 Tile location | At risk | 0.036 mm worst case against 0.03 mm |
| R5 Flatness | Not verifiable at TRL 3 | Depends on stock as supplied |
| R6, R8, R9, R10, R12 | Met on paper | 0.37 mm; 56 s; 190 mm print; $245.90 against $250; 181 N ballasted |
| R1, R2, R11 | Met by design | |

### Still awaiting Amish

1. **O1, first workshops and regions for co-design.** No recommendation; none chosen.
2. **O3, racking stiffness:** end low rails or a screwed-down shelf. The TRL 3 note named both without recommending one.
3. **O4 (new), the 122 screw-in positions over the frame:** (a) rate them light duty at 0.92 N·m, giving 296 to 493 N at the part (GBN-CAL-001, G5e); (b) move the insert sub-grid off the frame lines; (c) relax R7 there. Recommendation: (a).

### Cross-repo actions

None. No decision in this repo needs a change in another repo.

### TRL 4

TRL 4 remains on hold by Amish's instruction. `trl` and `trl_target` stay at 3. Pull tests of the tee nuts and inserts, push tests for tipping and sliding with the rubber pads, and all purchasing are recorded as decided-in-principle work for TRL 4 and not started.

### Notes

- The decision wording relies on Amish's chat message as relayed to this session on 2026-09-25.
- New assumptions flagged in GBN-CAL-001 v0.2: plywood bearing strength under a tee-nut flange (10 MPa), tee-nut pull-through on the same shear strength as inserts, and indicative prices for tee nuts ($0.12), 45 x 120 mm timber ($2.80/m) and rubber-padded feet ($2.50).

## Session 2026-09-26: sources strengthened

Amish asked on 2026-09-26 to fix the weaker sources. Changes, all in `README.md`:

| Claim | Old source | New source |
| --- | --- | --- |
| US manufacturers with fewer than 500 employees (Burning platform and United States row) | ITIF, citing NAM | National Association of Manufacturers, [Facts About Manufacturing](https://nam.org/mfgdata/facts-about-manufacturing-expanded/). Figures updated to the NAM page: about 239,000 firms in 2022, more than 98 % with fewer than 500 employees. |
| Kenya row | Kenyan Wallstreet, reporting KNBS (85 % of new jobs informal) | Kenya National Bureau of Statistics, [Economic Survey 2024, popular version](https://www.knbs.or.ke/wp-content/uploads/2024/05/2024-Economic-Survey-Popular-Version.pdf). The 85 % figure could not be verified in a KNBS document that could be fetched, so the row now states only the growth rates in that document (informal employment 4.5 %, formal wage employment 4.1 %, 2023). |
| What sparked the idea: how Blanc made the parts | Wikipedia, "Honoré Blanc" | Jefferson to Jay, 30 August 1785 (Founders Online), already the section's primary source. The hand-filing, jig and gauge detail was removed because it rested only on Wikipedia; the section now quotes Jefferson's own words ("by tools of his own contrivance"). The inspiration event is unchanged. |

No country rows were replaced. `docs/01-problem.md` did not cite these sources, so no controlled document changed. The RP Photonics link (grid convention) and the Siegmund dealer listing (a price, for which the listing is the primary source) were not flagged and were kept.

## Session 2026-09-26: product appearance model and photoreal renders

Amish chose this repo on 2026-09-26 for the first batch of product renders. This session added `cad/src/product_model.py` (appearance model, 42 parts), set the README hero image to `media/render-hero.png` with a link to `media/render-exploded.png`, and wrote this note. The render files are produced later by the portfolio render pipeline. No other file changed: `model.py`, the BOM, the drawings and the controlled documents are untouched.

### What product_model.py adds

- `product_parts()`, `TITLE` and `RENDER_VIEWS` (hero from the front right at about 30 deg, exploded from the front right at about 28 deg, and a detail view of the worktop and fixture set without the frame at about 42 deg).
- Worktop: all 1,008 grid holes cut (cut per 150 mm cell so the mesh stays light), eased 1 mm edges, lamination lines on the plywood edges, laser-etched index ticks every 100 mm along the front and left margins, brass screw-in inserts flush in the top and zinc tee nuts underneath.
- Precision tile: chamfered top edge, every M6 hole, the 9 dowel bores, and cap screws seated in the 4 counterbores.
- Frame: members with eased arrises, domed M8 carriage bolt heads at every leg joint, a teal name plate on the front apron; levelling feet with rubber pads, filleted steel pads and lock nuts; shelf and ballast slabs with softened edges.
- Fixture set: toe clamps with a toe relief, grip ribs, M6 screws, washers and lobed knobs; round and diamond pins; a machined sample block; fence segments with cap screws and a sight line; stop pins with collars; a V-block holding a sample round bar; a slotted instrument post with end cap, arm clamps, and a dial indicator with bezel, graduated face, needle, crystal and contact point on the sample block.
- Context: a compact section of workshop floor.

### Differences from model.py

1. **Toe-clamp screw positions.** Proposed, awaiting Amish. model.py places the two clamp screws at (320, 40) and (430, -40) mm, which fall between tile holes (holes sit at 12.5 + 25k mm). The appearance model puts each screw on the nearest tile hole, (312.5, 37.5) and (437.5, -37.5), and slides the clamp bodies in their slots to stay near the model.py positions. Recommendation: update model.py to the same hole-centered positions at the next model revision.
2. **Wall anchor brackets (BOM 15, optional) left out.** Proposed, awaiting Amish. With no wall in the scene the brackets read as loose tabs behind the bench. Recommendation: keep them out of product renders and keep them in model.py, the drawing and the BOM as they are.
3. **Full hole pattern in the worktop.** Proposed, awaiting Amish. model.py cuts a representative 8 x 8 patch to keep STEP and STL files small; the appearance model cuts all 1,008 holes so the grid reads in renders. Grid positions come from model.py (`classify()`, `insert_kinds()`), so nothing moves. Recommendation: keep this split (patch in the exported CAD, full pattern in renders).
4. **Appearance-only additions** (lamination lines, index ticks, name plate, bolt heads, knobs, the sample block and bar) change no dimension or interface. The index ticks and name plate are not in the BOM. Recommendation: treat them as render detail only unless Amish wants them adopted.

### Status

This is an appearance model only: no tolerances, fabrication detail or build instructions. `trl` and `trl_target` stay at 3, and TRL 4 remains on hold.

## Session 2026-09-27: kit 1.5.0 and image quality

- Kit 1.5.0 synced: STANDARDS v1.5 (sections 12 to 15: product renders, storefront images and image quality, public release, authorship and signing), `.kit/cards.py`, `.kit/image_qc.py`, `.kit/release_gate.py`, issue templates, and the `/render-product` and `/release` commands. `CLAUDE.md` now matches `.kit/CLAUDE.md`.
- Every `media/render-*.png` recaptioned from its original render with the new layout: the title, concept label and repository sit in a band above the render and the view note in a band below it, each line wrapped to the image width, so no text overlaps other text or the render or runs off the image. `media/card.png` and `media/social-preview.png` regenerated with the same rules.
- `python .kit/image_qc.py` and `python .kit/release_gate.py` pass. trl stays 3.

## Session 2026-10-01: design for construction and prototype build plan (kit 1.7.0)

Amish approved the build plan format on 2026-09-30 ("this is the correct build plan ... this is a good quality document format. Extend this across all the other repos"), asked for outstanding decisions to go in a separate design decisions register, and asked for any design that cannot be built as drawn to be made physically feasible. On 2026-10-01 he set `budget_usd` as a value-engineering target, not a limit. This session installed kit 1.7.0, ran `/build-plan` and stopped at TRL 3.

### What was done

- Kit 1.7.0 installed (`.kit/`, `.claude/commands/`); `CLAUDE.md` now matches `.kit/CLAUDE.md`.
- `cad/src/model.py`: every component is now its own solid (`build_components()`), with a constructability check (`python cad/src/model.py --check`, 92 checks, all pass). STEP and STL re-exported to `cad/step/` and `cad/stl/`.
- `docs/decisions/0003-design-for-construction.md` (GBN-DDR-003 v0.1, Draft): every change below, made under Amish's 2026-09-30 instruction to make the design physically buildable; open for his review.
- `cad/src/build_plan_media.py`: overview, worktop hole layout, 16 making sketches (`cad/drawings/GBN-DWG-101` to `116`), 11 joint close-ups and 15 assembly step pictures in `docs/05-build-plan/`.
- `docs/05-build-plan.md` (GBN-BLD-001 v0.1) and `docs/06-design-decisions.md` (GBN-DEC-001 v0.1, with a Value engineering section).
- GBN-DWG-001 to Rev P4; concept media re-rendered from the updated model.
- GBN-CAL-001 v0.3 and `sizing.py`, GBN-PRC-001 v0.5, GBN-REQ-001 v0.5, `bom/bom.csv` (17 lines) and `bom/bom-notes.md`, `project.yaml` (`design_state: constructable`, new evidence), `README.md` (links line and "Building the prototype"); PDFs rebuilt.

### Design changes made for construction (GBN-DDR-003)

1. Long aprons shortened to 1,020 mm and butted between the legs (they ran through them); every apron and low rail end held by two M8 x 120 bolts into M8 cross dowels, the end-apron bolts staggered against the long-apron bolts inside the leg.
2. Cross rail under the tile's right edge notched 15 x 25 mm at both ends (it ran 15 mm into the right-hand legs); every cross rail held by two 6 x 100 mm screws through the apron at each end.
3. Shelf 1,010 mm long instead of 1,020 mm, so it fits between the legs.
4. Tile pocket 301 x 301 mm with 8 mm corner relief holes (it was the tile's exact size with square corners).
5. Tile held by four M6 x 20 cap screws into screw-in inserts in the two tile rails (the counterbored holes had nothing to screw into).
6. Worktop held by nine steel angle brackets on the apron inside faces (it had no fixing), each clear of every tee nut and cross rail.
7. Leg ends bored 12 mm with an M10 T-nut for each levelling foot (the stems ended in solid wood).
8. Fence, V-block, post foot and toe clamp screws moved onto threaded positions; stop pins given a spigot; one screw length rule (15 to 18 mm below the plywood surface, 12 mm at most on the tile).
9. Instrument arm passes beside the post through a printed arm clamp, and the drop rod beside the arm's end through a printed end clamp (the arm passed through the post); post foot 74 x 74 mm on two M6 screws, post held by two M5 screws; post moved to the plywood directly behind the tile.
10. V-block's V narrowed to 50 mm with 5 mm flats, so the block is 60 mm tall as specified (the V cut its top edges off).
11. Optional wall anchor angles fixed under the rear apron and down the wall (the flat leg pointed at no wall).

### Key results

- Mass 43.8 kg empty (was 41.9 kg), 69.5 kg with ballast; tipping 117 N empty, 186 N with ballast (target 150 N); stiffness unchanged at 0.37 mm.
- Value-engineering target: USD 250. Estimated cost of the constructable design: USD 268.40 (USD 18.40 over the target). The cost drivers and savings worth trying are in GBN-DEC-001.
- Requirements: R7 not met at the 122 screw-in positions (unchanged); R10 over the value-engineering target by USD 18.40; R3 and R4 at risk; R5 not verifiable at TRL 3; R6, R8, R9 and R12 met on paper; R1, R2 and R11 met by design.

### Decisions proposed and awaiting Amish

All are in the design decisions register (`docs/06-design-decisions.md`): review of GBN-DDR-003; O4, the light-duty rating of the 122 screw-in positions (recommended); O3, racking stiffness; O1, first workshops; and three appearance items from 2026-09-26 (wall anchor out of renders, full holes only in renders, render-only details). No budget decision is proposed: the budget is a value-engineering target.

### Stale outputs

The photoreal renders `media/render-hero.png`, `media/render-exploded.png` and `media/render-detail.png` (made on Amish's Mac, not in this cloud copy), `media/card.png` and `media/social-preview.png`, and the appearance model `cad/src/product_model.py` still show the concept: fixture positions, post and arm without clamps, and no brackets, T-nuts or frame bolts. The appearance model reads the apron length from `model.py`, so it already butts the aprons between the legs. They are not regenerated here and need updating on the Mac.

### Safety concerns

Unchanged in kind: tipping of the empty bench (117 N), chips and projectiles when drilling, tapping and routing, pinch points at clamps, printed clamps cracking above 1.6 N·m, screw-in positions over the frame pulling out before full clamp force, and no hot work. The build plan adds six safety stops (S1 to S6), including a two-person lift for the worktop.

### Recommended next step

Amish to review GBN-DDR-003 and the register. TRL 4 remains on hold; a TRL 4 build would follow GBN-BLD-001 and record the first checks of its section 5.

### Picture check

Every picture made in this session was looked at: the overview, the worktop hole layout, the 16 making sketches, the 11 joint close-ups, the 15 step pictures, the general arrangement and the concept media (hero, exploded view, flow, blueprint). Pictures that were unclear were redrawn: joints 1, 2 and 3 as sections cut level with a bolt or screw and seen from above, joints 5, 6, 7 and 9 with the cut facing the camera, the long members' sketches drawn standing on end so their views fit the sheet, the packer and fixture sketches with insets that zoom in on where the part sits, the step pictures with bolts pulled out on the correct side, and the overview with the shelf, slabs and wall anchor moved clear of the frame. `python .kit/drawing.py --check-text cad/drawings/*.svg media/concept-blueprint.svg` finds no overlapping text. One known weakness: in joint 3 the leader for the front right leg ends at the leg's corner beside the apron, because the kit picks the leader point.

## Session 2026-10-02: open decisions decided by Amish

Authority: Amish, 2026-10-02: "i approve your recommendations for all 555 open decisions." The recommendations approved are those written for the open decisions in the design decisions register. No model, BOM quantity or price, or picture was changed; where a decision needs one, it is listed below as a follow-up. `trl` and `trl_target` stay at 3. No commit or push.

### Decisions recorded

7, all moved to "Decisions made" in `docs/06-design-decisions.md`, dated 2026-10-02:

1. Design for construction (GBN-DDR-003) accepted as recorded.
2. Clamp rating: the 122 screw-in positions over the frame rated light duty at 0.92 N·m (296 to 493 N at the part), marked on the worktop in a contrasting colour and stated in the fixture library notes.
3. Racking: shelf screwed down to the low rails now; push test at TRL 4; end low rails only if the frame still sways.
4. First workshops for co-design: makerspaces or technical colleges with a CNC router that teach fixturing; first candidate a member lab of the Fab Lab network.
5. Wall anchor angles: left out of the renders, kept in the model, drawing and BOM.
6. Hole pattern: full pattern in the renders, representative patch in the exported CAD.
7. Appearance-only render details: render detail only.

### Documents changed

- `docs/06-design-decisions.md` (GBN-DEC-001 v0.2): also withdraws the plain-hole saving under Value engineering
- `docs/decisions/0003-design-for-construction.md` (GBN-DDR-003 v0.2): accepted; status stays Draft
- `docs/decisions/0002-recommendations-accepted.md` (GBN-DDR-002 v0.2): O1, O3 and O4 decided
- `docs/decisions/0001-trl2-review-decisions.md` (GBN-DDR-001 v0.3): O1 decided
- `docs/02-concept.md` (GBN-PRC-001 v0.6): open items closed with the decisions
- `docs/03-requirements.md` (GBN-REQ-001 v0.6): R7 note on the light-duty rating
- `docs/05-build-plan.md` (GBN-BLD-001 v0.2): safety stop S5 states the light-duty rating and marking

### Follow-up actions to carry approved decisions into the design

1. Decision 2 (drawings): Show the contrasting-colour marking of the 122 light-duty positions on the worktop making sketch and GA drawing GBN-DWG-001.
2. Decision 2 (pictures): Show the marking in the build plan worktop pictures.
3. Decision 2 (bom): Add the marking paint or marker to the fastener kit line of the BOM.
4. Decision 2 (docs): State the light-duty rating (0.92 N·m, 296 to 493 N at the part) in the fixture library notes.
5. Decision 3 (model): Add the screws that fix the shelf down to the low rails in `cad/src/model.py`, with the constructability checks re-run.
6. Decision 3 (pictures): Show the shelf screws in build plan steps 4 and 7 and the shelf making sketch.
7. Decision 3 (bom): Add the shelf screws to the fastener kit line of the BOM.

### Points found in the review

- A saving in Value engineering (leave the 122 screw-in positions as plain holes 'if decision 2 rates them light duty anyway') contradicts item 2: the light-duty rating depends on the screw-in inserts being there.

## Session 2026-10-02: approved follow-ups carried out

Authority: Amish, 2026-10-02: "497 follow-up actions that need CAD, drawing, picture, BOM or calculation work ... APPROVED CHANGES, COMPLETE THESE", and for the renders, "Photoreal renders are out of date in most repos ... COMPLETE THESE". `trl` and `trl_target` stay at 3; `budget_usd` is unchanged. No commit or push.

### Follow-ups

1. Decision 2 (drawings): done. GBN-DWG-001 Rev P5 rings the 122 light-duty positions in red on the top view, with a leader and a note; the worktop making sketch GBN-DWG-108 Rev P2 rings them on its top view and says how to paint them.
2. Decision 2 (pictures): done. The hole layout (`docs/05-build-plan/worktop-holes.png`) rings every screw-in position and adds a legend line; steps 8 and 9 show the red rings, and later steps carry them.
3. Decision 2 (bom): done. Line 12 adds one paint marker in a contrasting colour ($3.00, indicative retail); line 4 states the rings.
4. Decision 2 (docs): done. There was no separate fixture library notes file, so a "Fixture library notes" section is added to the precis (`docs/02-concept.md` v0.7), stating the light-duty rating (0.92 N·m, 296 to 493 N at the part) and the marking. The build plan worktop steps state it too.
5. Decision 3 (model): done. `cad/src/model.py` adds eight 4 x 30 mm countersunk wood screws (four into each low rail at 105, 375, 635 and 905 mm from the shelf's left end), with clearance and countersink holes in the shelf and pilot holes in the rails. Four new checks (screws in their shelf holes, reaching into the rails, clear of the ballast, clear of the frame bolts and legs); 96 of 96 checks pass. STEP and STL regenerated.
6. Decision 3 (pictures): done for step 7 (shelf and its screws), the shelf making sketch GBN-DWG-107 Rev P2 (eight holes and the screws in the inset), the low rail sketch GBN-DWG-104 Rev P2 and the overview. Step 4 comes before the shelf, so its picture shows no screws; its text now says the shelf is screwed into the rail tops in step 7.
7. Decision 3 (bom): done. Line 12 adds the eight shelf screws (8 at an indicative $0.10); line 3 states them.

Cross-repo actions: none.

### Results

- Requirement status changes: none. R7 stays not met at the 122 screw-in positions (rated light duty, as decided); R10 stays over the value-engineering target, now by $22.20.
- Value-engineering target: USD 250. Estimated cost of the constructable design: USD 272.20 (USD 22.20 over the target) [K4]; line 12 rises from $14.00 to $17.80 [K2c]; everything $292.20.
- Mass: bench 43.8 kg empty (fasteners 2.7 kg, up about 0.03 kg); 69.6 kg with the ballast [B1], [B2]; anchor tie force 34 N [C6].
- Appearance model (`cad/src/product_model.py`) brought into line with the constructable design: hex bolt heads and washers on the legs at the model's 24 bolt positions (were carriage bolts on the aprons), tile pocket with 0.5 mm clearance and corner relief holes, the nine worktop brackets, the eight shelf screw heads, the red light-duty rings, and the fence, V-block, stops, toe clamps, post foot screws, arm clamp, end clamp, drop rod and indicator at the model's positions. Remaining appearance differences are those Amish decided on 2026-10-02 (wall anchor left out, full hole pattern, render-only details); hidden details (rail notch, cross dowels) are not drawn. Render scenes exported to `/home/claude/renders/gridbench`; photoreal renders, `card.png` and `social-preview.png` are to be made on Amish's Mac.

### Documents changed

- `cad/src/model.py`, `cad/src/sheets.py`, `cad/src/build_plan_media.py`, `cad/src/product_model.py`, `cad/src/concept_media.py`; `cad/step/`, `cad/stl/`
- `cad/drawings/GBN-DWG-001` Rev P5; `GBN-DWG-104`, `GBN-DWG-107`, `GBN-DWG-108` Rev P2
- `docs/05-build-plan/`: worktop-holes, overview, steps 7 to 15
- `bom/bom.csv` (lines 3, 4, 12), `bom/bom-notes.md`
- `docs/04-calcs/sizing.py`, `sizing-output.txt`, `01-sizing.md` (GBN-CAL-001 v0.4)
- `docs/05-build-plan.md` (GBN-BLD-001 v0.3), `docs/02-concept.md` (GBN-PRC-001 v0.7), `docs/03-requirements.md` (GBN-REQ-001 v0.7), `docs/06-design-decisions.md` (GBN-DEC-001 v0.3), `README.md`
- Concept media regenerated (`media/`)

## 2026-10-02: photoreal renders redone on the constructable design

Rendered with Blender Cycles on Amish's Mac from the updated appearance model; captioned with `.kit/photo_caption.py`; `media/card.png` and `media/social-preview.png` regenerated with `.kit/cards.py`. Views: hero, exploded, detail. image_qc passes. Appearance deviations are those logged above as proposed, awaiting Amish.

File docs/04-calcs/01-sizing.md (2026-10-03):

---
doc_id: GBN-CAL-001
title: GridBench sizing calculations
project: GridBench
doc_type: Calculation
version: "0.4"
status: Draft
date: '2026-10-02'
author: Amish Chadha
license: CERN-OHL-S-2.0
revisions:
- version: "0.1"
  date: '2026-09-25'
  author: Amish Chadha
  change: First issue for TRL 3 (grid, mass, tipping, stiffness, moisture and temperature, dowel location, clamps and inserts, fixture change, buildability, cost)
- version: "0.2"
  date: '2026-09-25'
  author: Amish Chadha
  change: Recommendations accepted by Amish (DDR-002); $250 budget, 45 x 120 mm aprons, flanged tee nuts, rubber-padded feet; results re-run
- version: "0.4"
  date: '2026-10-01'
  author: Amish Chadha
  change: Design made constructable (GBN-DDR-003); mass, stability and cost re-run; cost reported against the value-engineering target
- version: "0.4"
  date: '2026-10-02'
  author: Amish Chadha
  change: 'Shelf screws (decision 3) and light-duty marking (decision 2) added: mass and cost re-run; light-duty rating recorded as decided'
---

# GridBench sizing calculations

On paper, GridBench meets seven of its twelve requirements (four by calculation, three by design), has two at risk, has one that cannot be verified at TRL 3, misses one in part, and is over its cost target. Version 0.4 adds the eight screws that fix the shelf down to the low rails and the paint marker for the light-duty rings, carrying out decisions Amish made on 2026-10-02: core parts now cost USD 272.20, USD 22.20 over the USD 250 value-engineering target [K4], and the ballasted bench is 69.6 kg [B2]; no requirement status changes. Version 0.3 follows the design-for-construction changes of GBN-DDR-003: the aprons and low rails butt between the legs on M8 bolts and cross dowels, the worktop is held by nine brackets, the tile by four screws into rail inserts, and the fixtures sit on threaded positions. The bench is 1.9 kg heavier (43.8 kg), tips at 117 N empty and 186 N ballasted, and its core parts cost USD 268.40: value-engineering target USD 250, USD 18.40 over the target [K4]. Stiffness and every other result are unchanged. Version 0.2 applied the recommendations Amish accepted on 2026-09-25 (GBN-DDR-002): `budget_usd` is now $250, the long and end aprons are 45 x 120 mm instead of 45 x 95 mm, flanged M6 tee nuts pressed in from the underside replace the screw-in inserts wherever the underside is clear, and the levelling feet carry rubber pads. R10 (cost) was then met at $245.90. R6 (stiffness) now has margin: 0.37 mm against 0.5 mm, down from 0.49 mm. R7 (clamp hold-down) is met on paper at the 130 tee-nut positions (pull-through factor 1.51 to 2.42) and on the tile, but not at the 122 insert positions that sit over a frame member, where a screw-in insert must stay and its pull-out factor is still 0.57 to 0.92. R3 (coarse field accuracy, template-drilled build) and R4 (relocation within 0.03 mm) are at risk. R5 (flatness) cannot be verified at TRL 3. The first issue of this note changed four details of the TRL 2 concept, which stand: the printed toe clamp is deeper (30 mm instead of 16 mm) with a rated torque of 1.6 N·m instead of 2 N·m, every precision fixture carries one round and one diamond locating pin, the fence is printed in two 190 mm segments that fit a 200 mm bed, and two concrete slabs on the shelf form the ballast. Every number in this note is printed by `docs/04-calcs/sizing.py`; the tag in brackets, for example [C4], is the line of that script's output that carries it.

> **Safety:** These are first-principles estimates for a paper proof of concept. They do not replace a push test for tipping, a pull test of clamps and inserts, or inspection of the tile. The empty bench tips at about 117 N at its front edge [C2]; it must be ballasted or anchored before use. See GBN-PRC-001, Safety.

## Scope and method

The note checks every requirement in GBN-REQ-001 v0.5 against the design in GBN-PRC-001 v0.5 and the parametric model `cad/src/model.py`. The script imports the model's `PARAMS`, its derived dimensions and its grid functions, so the hole counts, bays, rail spans and foot positions used here are the ones in the STEP files and in drawing GBN-DWG-001. It also reads `bom/bom.csv` and `budget_usd` in `project.yaml`. Run it from the repo root with `python docs/04-calcs/sizing.py`; it also writes its output to `docs/04-calcs/sizing-output.txt`.

The design case is a bench in an indoor workshop at 10 to 35 °C and 20 to 80 % relative humidity, with the loads in GBN-REQ-001: 150 kg spread over the top, 500 N at the middle of a bay and a 150 N horizontal push at the top edge.

## Assumptions

*Table 1. Main assumptions.*

| Area | Assumption | Basis |
| --- | --- | --- |
| Densities | Softwood 500 kg/m³, plywood 680 kg/m³, aluminum 2,700 kg/m³, concrete 2,300 kg/m³ | Typical values |
| Plywood stiffness | E = 7 GPa, mean of the two in-plane directions, treated as an isotropic plate (ν = 0.3); holes reduce stiffness by the ligament efficiency 0.736 [A5] | Assumption; to confirm from the supplier's data for 18 mm birch |
| Frame timber | C16 softwood, mean E = 8 GPa, characteristic bending strength 16 MPa; joints pinned (no frame action) | EN 338 strength class values; conservative joint model |
| Plate theory | Simply supported rectangular plate, central point load or uniform load, coefficients from Timoshenko's tables by aspect ratio | Standard handbook method; edges screwed to rails are stiffer than simply supported |
| Moisture | Equilibrium moisture content at 21 °C: 4.5, 7.7, 11.0 and 16.0 % at 20, 40, 60 and 80 % RH | USDA Forest Products Laboratory, *Wood Handbook* (FPL-GTR-190, 2010), Table 4-2 |
| Moisture movement | Plywood in-plane strain 0.007 % per 1 % moisture content | **Unsourced estimate**; the *Wood Handbook* gives no plywood figure (checked 2026-09-25) |
| Hole position | Shared CNC router ±0.10 mm; printed drilling template ±0.10 mm per 200 mm placement | Assumptions |
| Fits | 8 mm H7 bore (0 to +0.015 mm), h6 pin (0 to -0.009 mm) | ISO 286 limits for 6 to 10 mm |
| Screws | M6, torque to tension T = K F d with nut factor K = 0.15 to 0.25 (nominal 0.2) | Common engineering range |
| PETG | Sustained bending stress limit 12 MPa (about a quarter of the short-term strength of printed PETG); CTE 60 × 10⁻⁶ /K | Assumptions; creep data for printed PETG to be confirmed |
| Inserts | Pull-out by shear of the plywood on the insert's outer cylinder (10 mm by 13 mm) at 2.5 to 4 MPa; for a tee nut, the same shear strength on a cylinder of the 19 mm flange diameter through the 18 mm sheet | Assumption; no test data found |
| Tee-nut flange bearing | Plywood bearing strength perpendicular to the face 10 MPa under the flange | Assumption; to be confirmed by a pull test at TRL 4 |
| Friction | Levelling feet on a workshop floor, μ = 0.2 (hard plastic) to 0.5 (rubber); the adopted rubber pads use 0.5 | Typical range |
| Timber prices | 70 x 70 mm $4.50/m, 45 x 120 mm $2.80/m, 45 x 70 mm $1.80/m, 10 % waste | Indicative 2026 retail |
| Frame hardware (GBN-DDR-003) | M8 x 120 bolt with washer $0.45 and 0.065 kg; M8 cross dowel $0.35 and 0.020 kg; 6 x 100 structural screw $0.20 and 0.020 kg; worktop bracket 0.030 kg; $1.00 of glue and small screws | Indicative 2026 retail; catalogue masses |

## A. Grid (R1)

- **Positions.** The 1,200 x 600 mm top holds a 48 x 24 grid of 1,152 positions: 144 tapped holes in the tile, 252 insert positions on the 50 mm sub-grid and 756 plain 6.6 mm holes. The first and last holes sit 12.5 mm from each edge [A1].
- **Tile continuity.** The tile's edges fall midway between grid lines, so its first hole is 12.5 mm from its edge and all 144 holes continue the field grid [A2]. A fixture can straddle both zones.
- **Ligaments.** Each 8 mm dowel bore sits at the center of a grid square, 17.7 mm from the nearest M6 hole, leaving a 10.7 mm ligament [A3]. The four counterbored fixing holes leave 7.5 mm [A4]. Both are ample for a 12.7 mm plate.

## B. Mass (context for R12)

- **Bench.** Frame timber 22.4 kg, worktop 7.2 kg, tile 3.0 kg, shelf 4.4 kg, inserts, feet and fasteners 2.4 kg, frame bolts, cross dowels, brackets and shelf screws 2.7 kg, and fixtures 1.7 kg give 43.8 kg [B1], against 41.9 kg in v0.2. The frame timber is lighter than in v0.2 because the long aprons no longer run through the legs (GBN-DDR-003); the bolts and brackets more than make up for it.
- **Ballast.** Two 400 x 400 x 35 mm concrete slabs weigh 12.9 kg each, 25.8 kg together; the ballasted bench is 69.6 kg [B2]. Each slab is light enough for one person to lift.

## C. Tipping and sliding (R12)

- **Base.** The feet are at 1,090 x 490 mm centers, so a push at the front edge acts at 900 mm against a 245 mm lever [C1].
- **Empty bench.** It tips at 117 N, below the 150 N target; along the bench it would take 260 N [C2]. R12 is not met by the empty bench.
- **Ballast.** At least 12.4 kg of ballast is needed [C3]. With the two slabs the bench tips at 186 N, a factor of 1.24 on 150 N [C4]. R12 is met on paper with the ballast in place.
- **Sliding.** On hard feet the empty bench would slide at about 86 N, before it tips. With the adopted rubber pads it slides at about 215 N empty and 341 N ballasted [C5], so a firm push no longer moves it. Sliding is not a requirement.
- **Anchor.** For the optional wall anchor, the tie force for a 150 N pull on the empty bench is only 34 N [C6], so light angle brackets suffice.

## D. Stiffness and strength (R6)

- **Worktop.** The largest plywood bay is 255 x 470 mm clear between rails and aprons [D1]. Under 500 N at its center the plywood deflects 0.19 mm relative to its supports [D2]. The TRL 2 strip estimate (0.41 mm) ignored the plate action.
- **Frame.** The two cross rails of that bay add 0.07 mm [D3] and the 45 x 120 mm long aprons, spanning 1,090 mm between legs, add 0.11 mm [D4]. The total is 0.37 mm against the 0.5 mm target [D5], with the joints treated as pinned (conservative) and the worktop not counted as stiffening the aprons.
- **Apron depth.** The v0.1 aprons, 45 x 95 mm, gave 0.49 mm, with almost no margin [D6]; the deeper aprons were accepted under GBN-DDR-002. 45 x 145 mm aprons would give 0.32 mm [D7], not enough gain to justify the extra depth.
- **Distributed load.** 150 kg over the top is 2.04 kPa. The plywood deflects 0.030 mm; each long apron 0.26 mm at a bending stress of 1.0 MPa, a sixteenth of the C16 strength [D8]. The legs see 0.10 MPa [D9].
- **Tile.** Spanning 255 mm between its packers, the tile deflects 0.061 mm under 500 N at its center, at 4.9 MPa [D10]. Heavy point loads on the tile therefore affect R5 while they act; the tile recovers elastically.
- **Shelf.** The slabs bend the shelf 0.38 mm over its 490 mm span [D11].

## E. Moisture and temperature (R3, R4)

- **Humidity band.** Between 40 and 60 % RH wood settles at 7.7 to 11.0 % moisture content; a top built at the middle, 9.35 %, swings ±1.65 % [E1].
- **Plywood field.** With the unsourced coefficient of 0.007 % per % moisture content, the field moves ±0.115 mm over 1,000 mm within the R3 humidity band [E2], and ±0.40 mm over the full 20 to 80 % operating range [E3]. The TRL 2 figure of up to 0.4 mm over 1,200 mm for a 5 % swing is consistent with this.
- **Hole to hole over 1,000 mm.** A CNC-drilled top reaches ±0.22 mm against the ±0.3 mm target [E4]. A template-drilled top reaches ±0.34 mm statistically against ±0.5 mm, but ±0.62 mm if every template step errs the same way [E4]. R3 is at risk for the template build and rests on an unsourced coefficient.
- **Tile.** The tile grows 0.069 mm over 300 mm, and 0.046 mm across the 200 mm dowel span, per 10 K [E5]. A PETG fixture with pins 200 mm apart mismatches the tile by 0.074 mm per 10 K [E6]; the diamond pin (section F) absorbs this along the pin line.

## F. Dowel location (R4)

- **Fit.** An 8 mm h6 pin in an H7 bore has 0 to 0.024 mm diametral clearance [F1].
- **Two round pins bind.** Pin and bore pitch errors of ±0.05 mm each add up to 0.10 mm, far more than the minimum clearance of zero, so a fixture on two round pins may not go down at all [F2]. The design now uses one round pin and one diamond (relieved) pin per precision fixture, the standard machinist's arrangement (BOM line 13).
- **Relocation.** With pins 200 mm apart, a point 100 mm from the round pin returns within 0.036 mm in the worst case and about 0.015 mm statistically, against 0.03 mm [F3]. R4 is at risk; pushing each fixture against the same side of its pins in use would bring the worst case close to zero. Hole position to ±0.05 mm by drill press and jig is not verifiable at TRL 3.

## G. Clamps and inserts (R7)

- **Lever.** The toe clamp's screw is 30 mm from the toe contact and 28 mm from the heel, so the part receives 0.483 of the screw tension. The 30 mm deep body, less its 6.6 mm slot, has a section modulus of 2,610 mm³ [G1].
- **TRL 2 clamp.** At 16 mm deep and 2 N·m, the clamp body would carry about 33 MPa, nearly three times the sustained limit for printed PETG [G3], so it would creep. The body is now 30 mm deep and the rated torque 1.6 N·m.
- **Revised clamp.** At 1.6 N·m the part receives 515 to 858 N over the nut factor range (target 500 N), at a peak body stress of 9.9 MPa against 12 MPa [G2, G4]. Printed on its side, the bending stress runs along the layers.
- **Inserts.** A screw-in insert resists 1.02 to 1.63 kN before the plywood shears around it, while the screw tension reaches 1.78 kN at the low nut factor; the factor is 0.57 to 0.92 [G5]. A screw-in insert therefore cannot guarantee 500 N at the part. On the tile, 12.7 mm of thread engagement is ample [G6] and R7 is met on paper, subject to PETG creep data.
- **Tee nuts (GBN-DDR-002).** Flanged M6 tee nuts pressed in from the underside now take the load at every insert position whose 19 mm flange has a clear underside: 130 of the 252 positions. The other 122 lie within the flange radius of an apron, cross rail or leg and keep a screw-in insert [G5b]. To pull out, a tee nut must punch its flange through the full sheet: 2.69 to 4.30 kN, a factor of 1.51 to 2.42 on the highest screw tension [G5c]. The flange bears on the plywood at 7.6 MPa against an assumed 10 MPa (factor 1.31), and the 9.5 mm barrel gives ample thread engagement [G5d]. R7 is met on paper at the tee-nut positions and not met at the 122 screw-in positions over the frame; Amish decided on 2026-10-02 to rate those positions light duty and ring them on the worktop in a contrasting colour: at 0.92 N·m the screw tension stays within the lowest insert strength, and the part receives 296 to 493 N [G5e].

## H. Fixture change (R8)

- Two screws out, two in, at 9 s each (12 turns at 2 turns per second plus 3 s to engage), 10 s to lift and place and 10 s to seat on the pins give 56 s against 60 s [H1]. R8 is met on paper with a thin margin; printed knobs or quarter-turn fasteners would widen it.

## I. Buildability (R9)

- **Printing.** The largest printed footprint is now the 190 mm fence segment, within a 200 x 200 mm bed; the TRL 2 fence was 400 mm long and would not have fitted [I1].
- **Tile.** Drilling and tapping 144 holes, reaming 9 bores and counterboring 4 takes about 4.2 h on a drill press with a tapping guide [I2], longer than the TRL 2 estimate of 2.5 h for tapping alone.

## K. Timber and cost (R10)

- **Timber.** The frame uses 3.43 m of 70 x 70 mm, 2.88 m of 45 x 120 mm and 3.92 m of 45 x 70 mm, 10.2 m in all [K1]. With 10 % waste and $23.40 of hardware (24 M8 x 120 bolts with washers, 24 M8 cross dowels, 16 structural screws and $1.00 of glue and small screws) the frame costs $57.00 [K2] (BOM line 1; $43.50 in v0.2, when the frame had no joints).
- **Inserts.** 130 tee nuts at $0.12 and 126 screw-in inserts at $0.10 (122 in the worktop, 4 in the tile rails) cost $28.20 [K2b] (BOM line 5).
- **Totals.** The 17-line BOM gives core parts of $272.20, the user-supplied dial indicator $15.00 and the optional anchor brackets $5.00, $292.20 in all [K3]. Besides the frame and inserts, the design-for-construction changes added the nine worktop brackets ($3.60, line 17), the arm clamps and drop rod (line 10, $12.00 to $15.00) and the longer screw set (line 12, $12.00 to $14.00). The eight shelf screws and the paint marker for the light-duty rings, added on 2026-10-02, take line 12 to $17.80 [K2c].
- **Against the value-engineering target.** Value-engineering target: USD 250 (`budget_usd`, a hypothetical control target, not a limit). Estimated cost of the constructable design: USD 272.20 (USD 22.20 over the target, 8.9 %); everything including the indicator and anchor is 16.9 % over [K4]. Core plus indicator is $287.20, against $239.20 at TRL 2 [K5]. The main cost drivers and the savings worth trying are in the design decisions register (GBN-DEC-001, Value engineering).

## L. Results against every requirement

*Table 2. Requirement status from this note.*

| ID | Requirement | Value | Target | Status |
| --- | --- | --- | --- | --- |
| R7 | Clamp hold-down | Part 515 to 858 N at 1.6 N·m; clamp 9.9 MPa; tee nut factor 1.51 to 2.42 at 130 positions; screw-in insert factor 0.57 to 0.92 at 122 positions [G4, G5, G5b, G5c] | 500 N, no creep after 8 h at 25 °C | **Not met** at the 122 screw-in positions over the frame; met on paper at the tee nuts and on the tile |
| R3 | Coarse field hole position | CNC ±0.22 mm; template ±0.34 mm statistical, ±0.62 mm worst case over 1,000 mm [E4] | ±0.3 mm (CNC); ±0.5 mm (template) at 40 to 60 % RH | **At risk** (template build; unsourced coefficient) |
| R4 | Precision tile location | Relocation 0.036 mm worst case, 0.015 mm statistical [F3]; hole position not verifiable | ±0.05 mm; 0.03 mm | **At risk** |
| R5 | Flatness | Depends on the plate as supplied and on the plywood sheet | Tile 0.05 mm over 300 mm; worktop 0.5 mm over 1,000 mm | Not verifiable at TRL 3 |
| R10 | Parts cost | $272.20 core (indicator user-supplied) [K3, K4] | $250 value-engineering target (`budget_usd`) | Over the value-engineering target by $22.20 |
| R6 | Stiffness and load | 0.37 mm total, 0.19 mm local, under 500 N; 150 kg at 1.0 MPa in the aprons [D5, D8] | 0.5 mm; 150 kg | Met on paper |
| R8 | Fixture change | 56 s [H1] | 60 s | Met on paper (thin margin) |
| R9 | Buildability | Largest print 190 mm; tile about 4.2 h by drill press [I1, I2] | 200 x 200 mm bed; CNC optional | Met on paper |
| R12 | Stability and edges | 186 N with 25.8 kg of ballast; 117 N empty [C2, C4] | 150 N; edges 0.5 mm or more | Met on paper with ballast (not met empty) |
| R1 | Grid standard | 1,152 positions at 25 mm, 12.5 mm edge offset, tile on grid [A1, A2] | 25.00 mm, M6, 12.5 mm | Met by design |
| R2 | Worktop size and height | 1,200 x 600 mm at 900 mm, feet ±15 mm (model) | At least 1,200 x 600 mm; 900 mm ±15 mm | Met by design |
| R11 | Openness | build123d source, CERN-OHL-S-2.0 | As stated | Met by design |

Counts: 1 not met (R7, in part), 1 over the value-engineering target (R10), 2 at risk, 1 not verifiable at TRL 3, 4 met on paper, 3 met by design. R12 counts as met on paper because the ballast is part of the adopted design. In v0.2, R10 was met at $245.90; the joints, fixings and clamps that make the design buildable (GBN-DDR-003) added $22.50. In v0.1, R10 was not met ($239.20 against $220) and R7 was not met anywhere on the plywood field.

## Checks against the TRL 2 figures

*Table 3. TRL 2 claims (GBN-PRC-001 v0.2) against this note.*

| TRL 2 claim | This note | Action |
| --- | --- | --- |
| 1,152 positions: 144 tile, 252 inserts, 756 plain | Same [A1] | Stands |
| Bench about 40 kg | 43.8 kg with the deeper aprons and the frame bolts and brackets [B1] | Precis updated |
| Deflection about 0.3 to 0.4 mm under 500 N | 0.19 mm local; 0.49 mm with 45 x 95 aprons, 0.37 mm with 45 x 120 [D2, D5, D6] | Aprons deepened (DDR-002) |
| Tipping about 105 N empty, about 160 N with 20 kg | 117 N empty; 186 N with 25.8 kg [C2, C4] | Precis updated |
| Tile growth about 0.07 mm over 300 mm per 10 K | 0.069 mm [E5] | Stands |
| Moisture movement up to about 0.4 mm over 1,200 mm | ±0.115 mm over 1,000 mm at 40 to 60 % RH; ±0.40 mm over 20 to 80 % RH [E2, E3] | Precis updated; coefficient still unsourced |
| Dowel relocation about 0.03 mm on two dowels | Two round pins can bind; round plus diamond pin gives 0.036 mm worst case [F2, F3] | Diamond pin added |
| Clamp force about 0.8 kN at 2 N·m | 805 N, but 33 MPa in a 16 mm body [G3] | Deeper body, 1.6 N·m |
| Insert pull-out 2 to 4 kN (unverified) | 1.02 to 1.63 kN (assumed shear) [G5]; tee nuts 2.69 to 4.30 kN [G5c] | Tee nuts where the underside is clear (DDR-002) |
| 400 mm printed fence | Does not fit a 200 mm bed [I1] | Two 190 mm segments |
| Tapping about 2.5 h | 4.2 h including drilling, reaming and counterbores [I2] | Precis updated |
| Parts about $239 (with indicator) | $287.20 with indicator; $272.20 core [K3, K5] | Reported against the USD 250 value-engineering target |

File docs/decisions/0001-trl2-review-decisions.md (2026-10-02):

---
doc_id: GBN-DDR-001
title: GridBench TRL 2 review decisions
project: GridBench
doc_type: Design decision record
version: "0.3"
status: Draft
date: '2026-10-02'
author: Amish Chadha
license: CERN-OHL-S-2.0
revisions:
- version: "0.1"
  date: '2026-09-25'
  author: Amish Chadha
  change: Record the TRL 2 review items adopted as recommended for TRL 3 work, and the items that remain open
- version: "0.2"
  date: '2026-09-25'
  author: Amish Chadha
  change: Recommendations accepted by Amish (DDR-002)
- version: "0.3"
  date: '2026-10-02'
  author: Amish Chadha
  change: 'O1 decided by Amish on 2026-10-02'
---

# 0001: TRL 2 review decisions

- **Date:** 2026-09-25
- **Status:** accepted in part. On 2026-09-25 Amish wrote "i accept all your recommendations, go with them across all repos." Items A1 to A10 and O2 are decided by Amish, 2026-09-25: go with recommendation (see GBN-DDR-002). Item O1 had no recommendation and was decided by Amish on 2026-10-02 ("i approve your recommendations for all 555 open decisions.").

## Context

The TRL 2 review note (`docs/REVIEW.md`, session 2026-09-25, /populate) listed nine items as "Proposed, awaiting Amish", and the design precis GBN-PRC-001 v0.2 listed six key design choices, each with options and a recommendation. On 2026-09-25 Amish asked for this batch of repos to be taken through the usual process with the instruction "you know the drill, nothing gets past TRL 3". He has not reviewed this repo's items one by one. Every item that carries a recommendation is therefore adopted as recommended for TRL 3 under that instruction and stays open for his review. Items without a recommendation stay open, and no new budget figure is applied.

## Options considered

The options for each item are those listed in `docs/REVIEW.md` (session 2026-09-25, /populate) and in GBN-PRC-001 v0.2, Key design choices and Cost.

## Decision

*Table 1. Items adopted as recommended.*

| # | Item | Adopted recommendation | Status |
| --- | --- | --- | --- |
| A1 | Budget and cost options | Options (a) and (b): the dial indicator is user-supplied and outside the parts budget, and the tile is bought as offcut stock. R10 is redefined to cover the bench, grid, tile and fixture set without the indicator. Option (c), raising `budget_usd` to $250, was the fallback; it is decided under O2. | Decided by Amish, 2026-09-25: go with recommendation |
| A2 | Grid standard | 25 mm pitch, M6, compatible with metric optical breadboards; a heavy 50 mm variant to be considered later | Decided by Amish, 2026-09-25: go with recommendation |
| A3 | Worktop zones | Two zones: a plywood field plus a 300 x 300 mm aluminum precision tile on the same grid | Decided by Amish, 2026-09-25: go with recommendation |
| A4 | Insert spacing | M6 inserts on the 50 mm sub-grid; plain 6.6 mm holes between them for pins | Decided by Amish, 2026-09-25: go with recommendation |
| A5 | Frame | Bolted timber for the prototype; welded steel as a documented variant | Decided by Amish, 2026-09-25: go with recommendation |
| A6 | Fixture bodies | Printed PETG with metal dowels, screws and tile; a machined option for heavily used jigs | Decided by Amish, 2026-09-25: go with recommendation |
| A7 | Stability fix | Ballast on the shelf plus an optional wall anchor bracket | Decided by Amish, 2026-09-25: go with recommendation |
| A8 | Fixture file convention | A short fixture metadata block in each build123d file giving the grid footprint and datum | Decided by Amish, 2026-09-25: go with recommendation |
| A9 | Fixture library license | Keep CERN-OHL-S-2.0, as for all hardware in the portfolio | Decided by Amish, 2026-09-25: go with recommendation |
| A10 | Tile position | At the right of the worktop, leaving the left 800 mm free for large parts | Decided by Amish, 2026-09-25: go with recommendation |

*Table 2. Items listed as open in v0.1.*

| # | Item | Status |
| --- | --- | --- |
| O1 | First workshops and regions for co-design. No recommendation was made and no preference is stated, so none is chosen here. | Decided by Amish, 2026-10-02: makerspaces or technical colleges that have a CNC router and teach fixturing; first candidate to approach, a member lab of the Fab Lab network |
| O2 | Raise `budget_usd` from $220 to $250 (cost option c). Recommended at TRL 2 only as the fallback if offcut prices do not hold. GBN-CAL-001 v0.1 showed core parts at $239.20, so the fallback was needed for R10 to be met. `budget_usd` is now $250 in `project.yaml`. | Decided by Amish, 2026-09-25: go with recommendation |

## Consequences

- Update, v0.2: the consequences of Amish's 2026-09-25 acceptance, including the $250 budget and the design changes, are recorded in GBN-DDR-002. The bullets below describe v0.1.

- `project.yaml`: unchanged apart from the TRL fields. `budget_usd` stays at $220. No pitch or problem rewording was recommended, so none was applied.
- GBN-PRB-001, GBN-PRC-001 and GBN-REQ-001 are revised to v0.3. The key design choices in the precis are no longer "proposed". R10 now excludes the user-supplied dial indicator (A1). R12 is assessed with the ballast in place (A7).
- The TRL 3 calculations (GBN-CAL-001) led to four detail changes within these choices: a deeper printed toe clamp with a rated torque of 1.6 N·m, one round and one diamond locating pin per precision fixture, the fence printed in two 190 mm segments, and two concrete slabs as the ballast. With them the core parts cost $239.20.
- GBN-CAL-001 shows R10 not met at $220 (met at the $250 fallback, O2) and R7 not met on the plywood field because of insert pull-out. Options for R7 are proposed in `docs/REVIEW.md` and await Amish; this record does not decide them.
- TRL 4 is on hold by Amish's instruction. Nothing in this record authorizes building or testing.

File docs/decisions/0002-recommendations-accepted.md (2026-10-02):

---
doc_id: GBN-DDR-002
title: GridBench recommendations accepted
project: GridBench
doc_type: Design decision record
version: "0.2"
status: Draft
date: '2026-10-02'
author: Amish Chadha
license: CERN-OHL-S-2.0
revisions:
- version: "0.1"
  date: '2026-09-25'
  author: Amish Chadha
  change: Recommendations accepted by Amish (DDR-002)
- version: "0.2"
  date: '2026-10-02'
  author: Amish Chadha
  change: 'O1, O3 and O4 decided by Amish on 2026-10-02'
---

# 0002: Recommendations accepted

- **Date:** 2026-09-25
- **Status:** accepted. Every item below that carried a recommendation is decided by Amish, 2026-09-25: go with recommendation. Items without a recommendation remained "Proposed, awaiting Amish" until Amish decided them on 2026-10-02 ("i approve your recommendations for all 555 open decisions.").

## Context

On 2026-09-25 Amish wrote, in chat: "i accept all your recommendations, go with them across all repos." Before that, GBN-DDR-001 v0.1 had adopted items A1 to A10 for TRL 3 work, open for his review, and left O1 and O2 open; the TRL 3 review note (`docs/REVIEW.md`, session 2026-09-25, TRL 3) added a recommendation on R7 and three suggestions. This record lists what is now decided, what changed in the repo and what stays open. TRL 4 remains on hold by Amish's instruction, and nothing here authorizes building, testing or purchasing.

## Options considered

The options for each item are those in `docs/REVIEW.md` (sessions 2026-09-25, /populate and TRL 3), GBN-DDR-001 and GBN-CAL-001 v0.1. Where an item offered several options, the recommended option is the decision.

## Decision

*Table 1. Items decided by Amish, 2026-09-25: go with recommendation.*

| # | Item | Decision | What changed in the repo |
| --- | --- | --- | --- |
| A1 | Cost options (DDR-001) | Dial indicator user-supplied; tile bought as offcut; R10 excludes the indicator | Already applied at TRL 3; status wording updated |
| A2 | Grid standard | 25 mm pitch, M6 | Status wording only |
| A3 | Worktop zones | Plywood field plus aluminum precision tile | Status wording only |
| A4 | Insert spacing | 50 mm sub-grid | Status wording only |
| A5 | Frame | Bolted timber; welded steel as a documented variant | Status wording only |
| A6 | Fixture bodies | Printed PETG with metal pins, screws and tile; machined option | Status wording only |
| A7 | Stability fix | Ballast on the shelf plus optional wall anchor | Status wording only |
| A8 | Fixture file convention | Metadata block giving grid footprint and datum | Status wording only |
| A9 | Fixture library license | CERN-OHL-S-2.0 | Status wording only |
| A10 | Tile position | Right of the worktop | Status wording only |
| O2 | Budget | Raise `budget_usd` from $220 to $250 | `project.yaml` $220 to $250; R10 target $250; core parts $245.90, R10 now met on paper ($4.10 margin) |
| D1 | R7 on the plywood field (TRL 3 review, option a) | Flanged M6 tee nuts pressed in from the underside; screw-in inserts kept where a frame member lies below | Model: 130 tee nuts (19 mm flange, 8.0 mm hole) and 122 screw-in inserts; BOM line 5 $25.20 to $27.80; GBN-CAL-001 G5b to G5d; R7 met on paper at 130 positions |
| D2 | Frame stiffness (TRL 3 review suggestion) | 45 x 120 mm aprons instead of 45 x 95 mm | Model and GA; deflection under 500 N 0.49 mm to 0.37 mm; bench 40.2 kg to 41.9 kg; frame $41.40 to $43.50 |
| D3 | Sliding (TRL 3 review suggestion) | Rubber pads on the levelling feet | Model and GA; BOM line 2 $2.00 to $2.50 each; empty sliding force 82 N on hard feet, 206 N on rubber pads |

Knock-on figures from GBN-CAL-001 v0.2: tipping force 107 N to 112 N empty and 176 N to 181 N ballasted; core parts $239.20 to $245.90.

*Table 2. Items left open on 2026-09-25, decided by Amish on 2026-10-02.*

| # | Item | Status |
| --- | --- | --- |
| O1 | First workshops and regions for co-design. No recommendation was made. | Decided by Amish, 2026-10-02: makerspaces or technical colleges that have a CNC router and teach fixturing; first candidate to approach, a member lab of the Fab Lab network |
| O3 | Racking stiffness: end low rails or a screwed-down shelf. The TRL 3 review named both without recommending one, and no requirement covers racking yet. | Decided by Amish, 2026-10-02: screw the shelf down to the low rails now; push-test at TRL 4 and add end low rails only if the frame still sways |
| O4 | New: the 122 screw-in insert positions that sit over a frame member, where R7 is still not met (pull-out factor 0.57 to 0.92). Options: (a) rate them light duty at 0.92 N·m, giving 296 to 493 N at the part (GBN-CAL-001, G5e), and mark them on the worktop; (b) move the insert sub-grid off the frame lines; (c) relax R7 at those positions. Recommendation: (a). | Decided by Amish, 2026-10-02: (a), with the positions marked in a contrasting colour and the rating stated in the fixture library notes |
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

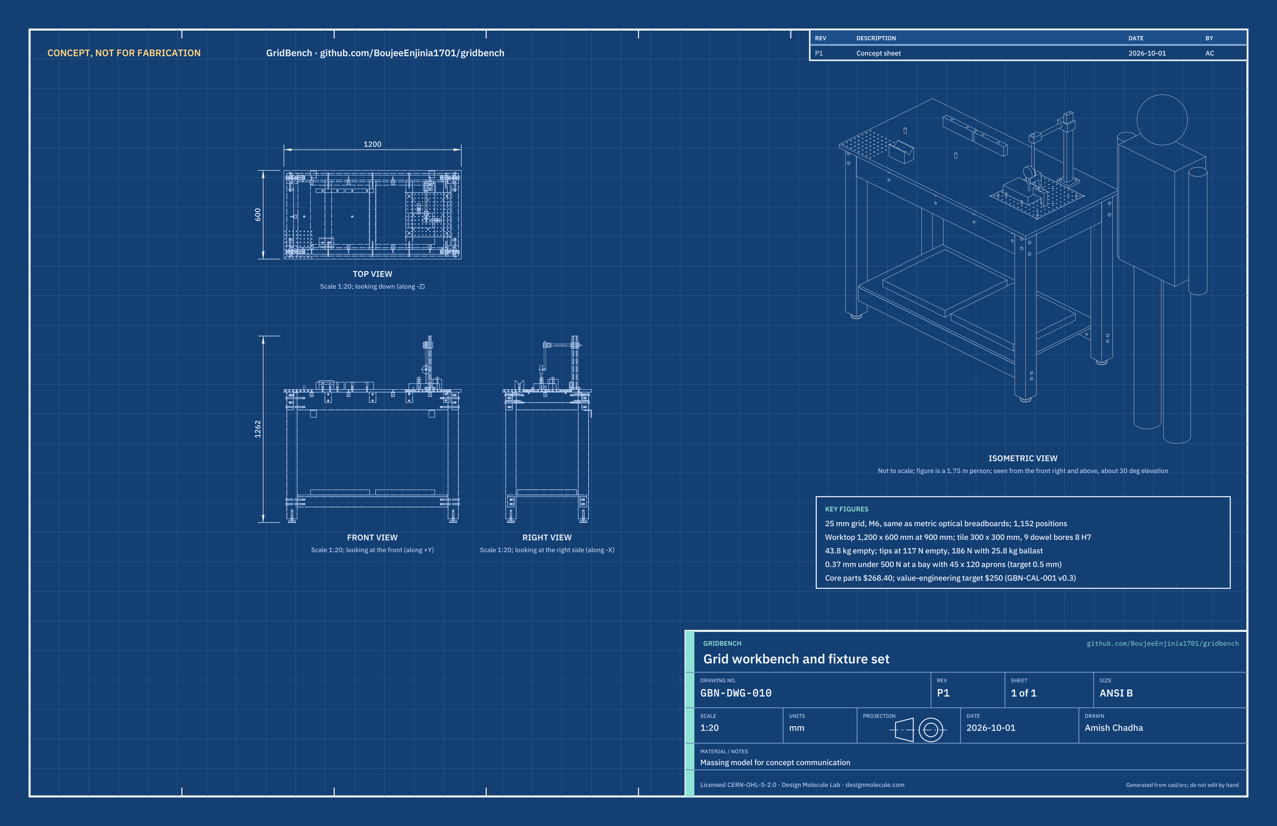
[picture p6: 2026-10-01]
media/concept-blueprint.png

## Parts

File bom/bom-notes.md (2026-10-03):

# BOM notes

- Line numbers match the callouts in `media/exploded.png`. Lines 12 (fastener kit), 16 (tile machining tools) and 17 (worktop brackets) have no callout.
- Every line is priced. All costs are indicative 2026 USD retail or bulk prices for budgeting, not quotes; suppliers are named by type and none is selected. The tile offcut price ($28.00) is unverified.
- The frame price (line 1) is built up in GBN-CAL-001, section K, from about 10.5 m of sawn softwood by section; the 45 x 120 mm rate ($2.80/m) is indicative.
- The `make_buy` column also marks two lines that sit outside the core parts total: line 11, the dial indicator, is `user-supplied` (GBN-DDR-001 A1), and line 15, the wall anchor brackets, is `optional` (GBN-DDR-001 A7).
- Totals (from `docs/04-calcs/sizing.py`, K3 and K4): value-engineering target USD 250 (`budget_usd`, a hypothetical control target, not a limit). Estimated cost of the constructable design: USD 272.20 for the core parts (USD 22.20 over the target); with the indicator and the anchor, $292.20.
- Changes on 2026-10-02 (decisions made by Amish that day, GBN-DEC-001): line 12 adds eight 4 x 30 mm countersunk wood screws that fix the shelf down to the low rails (decision 3, racking; 8 at an indicative $0.10) and one paint marker in a contrasting colour for the rings that mark the 122 light-duty screw-in positions (decision 2, clamp rating; indicative $3.00), $14.00 to $17.80 (GBN-CAL-001 K2c); lines 3 and 4 state the screws and the marking. Mass rises by about 0.03 kg [B1].
- Changes under GBN-DDR-003 (design for construction, 2026-10-01): line 1 now includes 24 M8 x 120 bolts, 24 cross dowels and 16 structural screws ($43.50 to $57.00, GBN-CAL-001 K2); line 3 shelf 1,010 mm long; line 5 adds 4 screw-in inserts for the tile rails ($27.80 to $28.20); line 6 specifies the M6 x 20 tile screws; line 10 adds the printed arm and end clamps and the drop rod ($12.00 to $15.00); line 12 sets the screw lengths ($12.00 to $14.00); line 15 fixes under the rear apron; line 17, nine worktop brackets, is new ($3.60).
- Changes under GBN-DDR-002: line 1 aprons 45 x 95 mm to 45 x 120 mm ($41.40 to $43.50); line 2 feet with rubber pads ($2.00 to $2.50 each); line 5 is now a set of 130 flanged tee nuts at $0.12 and 122 screw-in inserts at $0.10 ($25.20 to $27.80, GBN-CAL-001 K2b); line 4 drills 8.0 mm holes for the tee nuts.
- Lines 13 (diamond pins) and 14 (ballast slabs) were added at TRL 3, and line 16 prices the tile tools that the TRL 2 BOM folded into the tile line.
- The example workpiece shown in the renders is not part of the BOM.

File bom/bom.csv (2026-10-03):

item | qty | spec | supplier | unit_cost_usd | make_buy | notes
1 Bench frame | 1 | Bolted softwood: 4 legs 70 x 70 mm bored 12 mm at the foot; 2 long aprons and 2 end aprons 45 x 120 mm and 2 low rails 45 x 70 mm, all butted between the legs; 4 cross rails 45 x 70 mm (the right one notched round the legs); 2 hardwood packers 5.3 mm under the tile; 24 M8 x 120 hex bolts with washers into 24 M8 cross dowels; 16 structural screws 6 x 100 mm at the cross rail ends | Local timber yard and hardware shop | 57.00 | make | Indicative: about 10.2 m of sawn softwood priced by section in GBN-CAL-001 (K1, K2), plus 10 % waste and $23.40 of bolts, cross dowels and screws; joints made constructable under GBN-DDR-003 (was $43.50 with $9 of carriage bolts and screws)
2 Levelling feet | 4 | M10 levelling foot, 50 mm steel pad with 3 mm rubber base, with M10 T-nut in the leg; ±15 mm adjustment | Hardware or industrial supplier | 2.50 | buy | Indicative bulk price; rubber pads adopted under GBN-DDR-002
3 Lower shelf | 1 | 12 mm plywood, 1,010 x 535 mm, resting on the two low rails and screwed down to them with 8 countersunk screws (in line 12), 5 mm clear of the legs at each end | Local timber yard | 12.00 | make | Indicative price; carries the ballast (line 14); 10 mm shorter under GBN-DDR-003 so it drops in between the legs; screwed down to the low rails against racking (decision 3 | 2026-10-02)
4 Plywood grid worktop | 1 | 18 mm birch plywood, 1,200 x 600 mm; 1,008 holes on the 25 mm grid (756 at 6.6 mm, 122 at 8.5 mm for screw-in inserts, 130 at 8.0 mm for tee nuts); 300 x 300 mm through pocket for the tile; the 122 screw-in positions ringed in a contrasting colour as light duty; edges rounded 1 mm | Timber yard; holes by shared CNC router or printed drilling template | 45.00 | make | Indicative price (half sheet plus router bit wear)
5 M6 threaded inserts | 1 | Set of 256: 130 flanged M6 tee nuts (19 mm flange, 9.5 mm barrel, 8.0 mm hole) pressed in from the underside of the worktop; 122 screw-in M6 inserts for wood (10 mm OD, 13 mm long) where a frame member lies below; 4 more screw-in inserts in the two tile rails for the tile screws | Fastener supplier | 28.20 | buy | Indicative bulk prices: tee nuts $0.12, screw-in inserts $0.10 (GBN-CAL-001 K2b); tee nuts adopted under GBN-DDR-002; 4 rail inserts added under GBN-DDR-003
6 Precision grid tile plate | 1 | Cast aluminum tooling plate 300 x 300 x 12.7 mm, bought as offcut; machined to 144 M6 tapped holes, 9 dowel bores 8 mm H7 at 100 mm pitch, 4 counterbored 7 mm fixing holes (11 mm by 6.5 mm deep) for M6 x 20 cap screws into the rail inserts | Metal stockist or offcut dealer | 28.00 | make | Indicative offcut price, unverified (adopted cost option b); cut-to-size plate is about $38
7 Round dowel pins | 6 | 8 mm h6 hardened steel dowel pin, 20 mm long | Industrial supplier | 0.60 | buy | Indicative price; one per precision fixture plus spares
8 Printed toe clamps | 4 | PETG toe clamp 70 x 24 x 30 mm body with 6.6 mm slot and 40 mm heel, printed on its side; about 50 g each | Printed in house | 1.50 | make | Indicative filament cost; rated screw torque 1.6 N m (GBN-CAL-001)
9 Printed fence stops and V-block | 1 | Set: fence in two 190 mm segments, each on two grid holes; 6 stop pins for 6.6 mm holes; 90 degree V-block 100 x 60 x 60 mm; PETG about 500 g | Printed in house | 10.00 | make | Indicative filament cost; every part fits a 200 x 200 mm bed
10 Instrument post and arm | 1 | 20 x 40 mm aluminum extrusion 350 mm on a printed grid foot 74 x 74 x 12 mm (two M5 screws up into the extrusion, two M6 screws down into the grid); 18 mm steel arm 225 mm long; 12 mm steel drop rod 200 mm long; two printed clamps (arm clamp on the post, end clamp on the arm) with M6 thumb screws | Extrusion and hardware supplier | 15.00 | buy | Indicative price; clamps and arm layout made constructable under GBN-DDR-003 (was $12.00)
11 Dial indicator | 1 | 0.01 mm resolution, 0 to 10 mm travel, 8 mm stem, lug back | Tool supplier | 15.00 | user-supplied | Indicative price; user-supplied under adopted cost option a, so excluded from the core parts total
12 M6 fastener kit | 1 | M6 cap screws: 10 x 30 mm (fixtures on the worktop), 4 x 80 mm (toe clamps, with printed knobs), 4 x 20 mm (tile), 10 x 16 mm (fixtures on the tile); 2 M5 x 20 mm (post foot); washers; 8 countersunk wood screws 4 x 30 mm (shelf down to the low rails); one paint marker in a contrasting colour for the light-duty rings; 5 mm hex key | Fastener supplier | 17.80 | buy | Indicative price; no exploded-view callout; screw lengths set under GBN-DDR-003 so every screw reaches its thread (was $12.00); shelf screws (8 at $0.10) and paint marker ($3.00) added 2026-10-02 for decisions 2 and 3 (was $14.00), indicative retail prices
13 Diamond locating pins | 4 | 8 mm h6 relieved (diamond) locating pin, 20 mm long; pairs with a round pin so a fixture cannot bind on pitch error | Industrial supplier | 2.50 | buy | Indicative price; added at TRL 3 (GBN-CAL-001 section F)
14 Ballast slabs | 2 | Concrete paving slab 400 x 400 x 35 mm, about 13 kg each, laid on the shelf | Builders' merchant | 4.00 | buy | Indicative price; adopted stability fix (GBN-CAL-001 section C)
15 Wall anchor brackets | 1 | Pair of steel angles 50 x 50 x 4 mm, 40 mm wide: one leg screwed up under the rear apron, the other down the wall with screws and wall plugs | Hardware shop | 5.00 | optional | Indicative price; optional under the adopted stability fix; excluded from the core parts total; fixing made constructable under GBN-DDR-003
16 Tile machining tools | 1 | Two M6 spiral-point taps, 5.0 mm and 7.8 mm drills, 8 mm H7 reamer, tapping guide | Tool supplier | 18.00 | buy | Indicative price; consumed or reusable tooling for line 6
17 Worktop fixing brackets | 9 | Steel angle bracket 30 x 30 x 3 mm, 20 mm wide, with one 4 x 25 mm screw into the apron and one 4 x 16 mm screw up into the worktop each | Hardware shop | 0.40 | buy | Indicative price; added under GBN-DDR-003 (the concept had no worktop fixing); no exploded-view callout

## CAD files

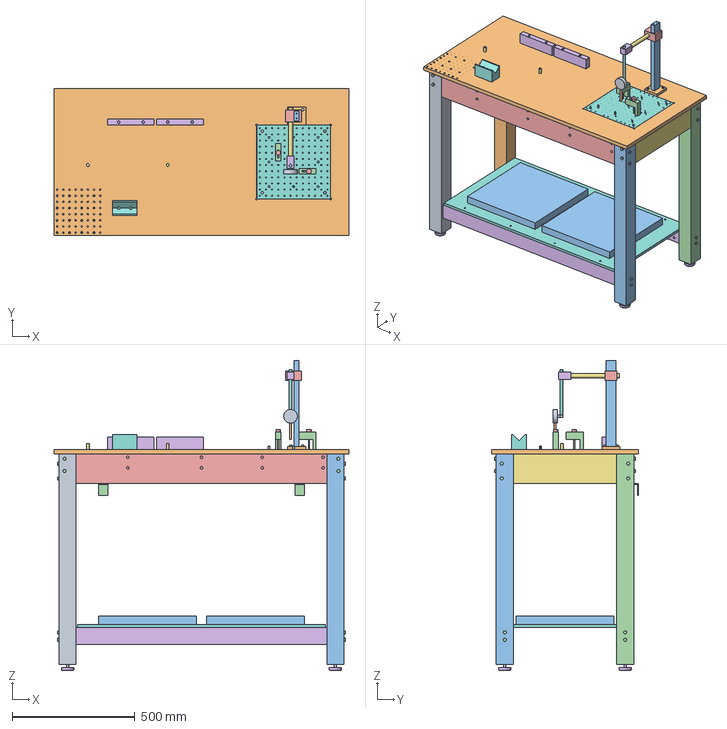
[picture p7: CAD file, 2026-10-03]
cad/step/gridbench-assembly.step
1200.0 x 600.0 x 1262.0 mm

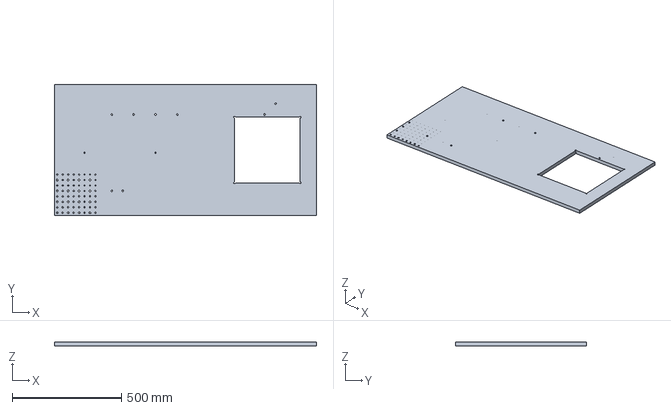
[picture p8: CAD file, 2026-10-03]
cad/step/worktop.step
1200.0 x 600.0 x 18.0 mm

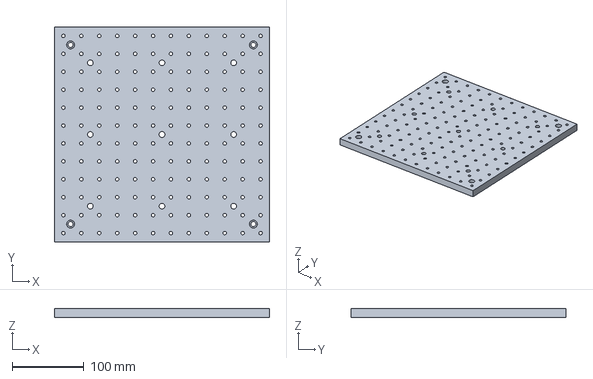
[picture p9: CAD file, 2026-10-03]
cad/step/precision-tile.step
300.0 x 300.0 x 12.7 mm

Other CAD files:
cad/stl/gridbench-assembly.stl
cad/stl/precision-tile.stl
cad/stl/worktop.stl

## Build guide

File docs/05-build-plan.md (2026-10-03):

---
doc_id: GBN-BLD-001
title: GridBench prototype build plan
project: GridBench
doc_type: Build plan
version: "0.3"
status: Draft
date: '2026-10-02'
author: Amish Chadha
license: CERN-OHL-S-2.0
revisions:
  - version: "0.1"
    date: '2026-10-01'
    author: Amish Chadha
    change: First build plan, with pictures by component and step; design made constructable (GBN-DDR-003)
  - version: "0.2"
    date: '2026-10-02'
    author: Amish Chadha
    change: 'Safety stop S5: screw-in positions rated light duty and marked (decided by Amish, 2026-10-02)'
  - version: "0.3"
    date: '2026-10-02'
    author: Amish Chadha
    change: 'Shelf screwed down to the low rails and light-duty positions ringed on the worktop, with the pictures redrawn'
---

# GridBench prototype build plan

**Plan, not yet built.** How to build the first proof-of-concept prototype, component by component. Building and testing to it is TRL 4 work. Decisions still to be made are kept in the design decisions register ([docs/06-design-decisions.md](06-design-decisions.md)), not here.

## 1. What you are building

Figure 1. Every component, pulled apart and numbered in build order

*Figure 1. Every component pulled apart and numbered in build order; 20, the wall anchor, is optional.*

The prototype is one GridBench: a bolted softwood frame on four levelling feet, carrying an 18 mm plywood worktop drilled on a 25 mm grid, with a 300 x 300 mm aluminium precision tile set flush in it at the right, two concrete slabs on a lower shelf, and a set of printed fixtures and an instrument post that screw onto the grid. Figure 1 shows the 20 components in the order you make or fit them. Sixteen kinds of part are made in a garage workshop, each with its own making sketch: the legs, end and long aprons, low and cross rails, packers and shelf (sawing and drilling timber), the worktop (drilling and routing plywood), the tile (drilling, reaming and tapping aluminium plate), and the toe clamps, fence, V-block, stop pins, post foot and two arm clamps (3D printing in PETG). Everything else is bought and fitted: feet, bolts and cross dowels, tee nuts and inserts, brackets, pins, the extrusion and rods for the post and arm, the dial indicator and the slabs. The parts cost about USD 272 from the bill of materials, with the dial indicator supplied by the user.

> **Safety:** Drilling, tapping, routing and sawing make chips and can throw work: wear safety glasses, clamp the work, and keep hands clear of turning tools. The finished bench tips at about 117 N at its front edge when empty, so the two ballast slabs (about 13 kg each) go on the shelf before the bench is used; lift each with a straight back. The worktop is about 7 kg and awkward: lift it with a second person. Printed clamps can crack and release a part if overtightened: never tighten a clamp screw past 1.6 N·m. The bench is plywood and PETG: no welding, grinding sparks or hot work on it.

## 2. What changed to make it buildable

The concept showed what the bench does; some of its parts could not be made, fixed or assembled as drawn. Each change below keeps what the bench does, and all of them are recorded in decision record GBN-DDR-003, open for Amish's review.

*Table 1. Changes from the concept.*

| Component | The concept had | The buildable design has | Why |
| --- | --- | --- | --- |
| Long aprons | Full-length aprons running through the legs, with no joint | Aprons 1,020 mm long, butted between the legs on two M8 bolts and cross dowels at each end (Figure 5) | Nothing overlaps, and the frame comes apart for moving |
| End aprons and low rails | No joint to the legs | The same bolt and cross dowel joint (Figures 5 and 8) | One joint for the whole frame |
| Cross rails | No fixing; the rail under the tile's right edge ran into the right-hand legs | Two screws through the apron into each end; that rail notched round the leg corners (Figure 10) | The rail keeps its place under the tile |
| Shelf | As long as the gap between the legs, so it could not go in | 10 mm shorter, 5 mm clear at each end (Figure 12) | It slides in and drops onto the rails |
| Worktop | No fixing to the frame; a square-cornered pocket the same size as the tile | Nine steel brackets underneath (Figure 16); pocket 0.5 mm larger all round with relief holes at the corners (Figure 13) | No screw blocks a grid hole; the tile drops in |
| Precision tile | Fixing holes with nothing to screw into | Four cap screws into threaded inserts in the two tile rails (Figure 18) | Uses the insert already in the bill of materials |
| Feet | Foot stems ending in solid wood | A T-nut in a 12 mm bore in each leg end (Figure 3) | The foot screws in and adjusts |
| Fixtures | Fence, V-block, post foot and clamp screws on unthreaded holes or between holes | Every fixture on threaded positions, with one screw length for the plywood (Figures 20 and 25) | Each one can be screwed down |
| Instrument arm | The arm passed through the post; no clamp at the drop rod | Two printed clamps; the arm passes beside the post and the drop rod beside the arm's end (Figure 28) | Nothing passes through anything else |
| Wall anchor (optional) | A flat leg pointing at no wall | One leg under the rear apron, the other down the wall (Figure 29) | It can be fixed to a wall |
| Shelf fixing | The shelf only rested on the low rails | Eight countersunk screws hold it down to the low rails (Figure 12, step 7) | The shelf braces the frame against racking |
| Light-duty positions | Not marked | The 122 screw-in positions ringed in a contrasting colour on the worktop (Figure 14) | A user can see where to clamp lightly |

## 3. Making the components

Make and check each component before the assembly step that needs it. Sizes are in millimetres. "Left" and "right" are as seen standing in front of the bench; "front" is where you stand. Workshop tolerance is 0.5 mm unless a step says otherwise; drawings do not carry tolerances before TRL 4.

### 3.1 Legs (make 4)

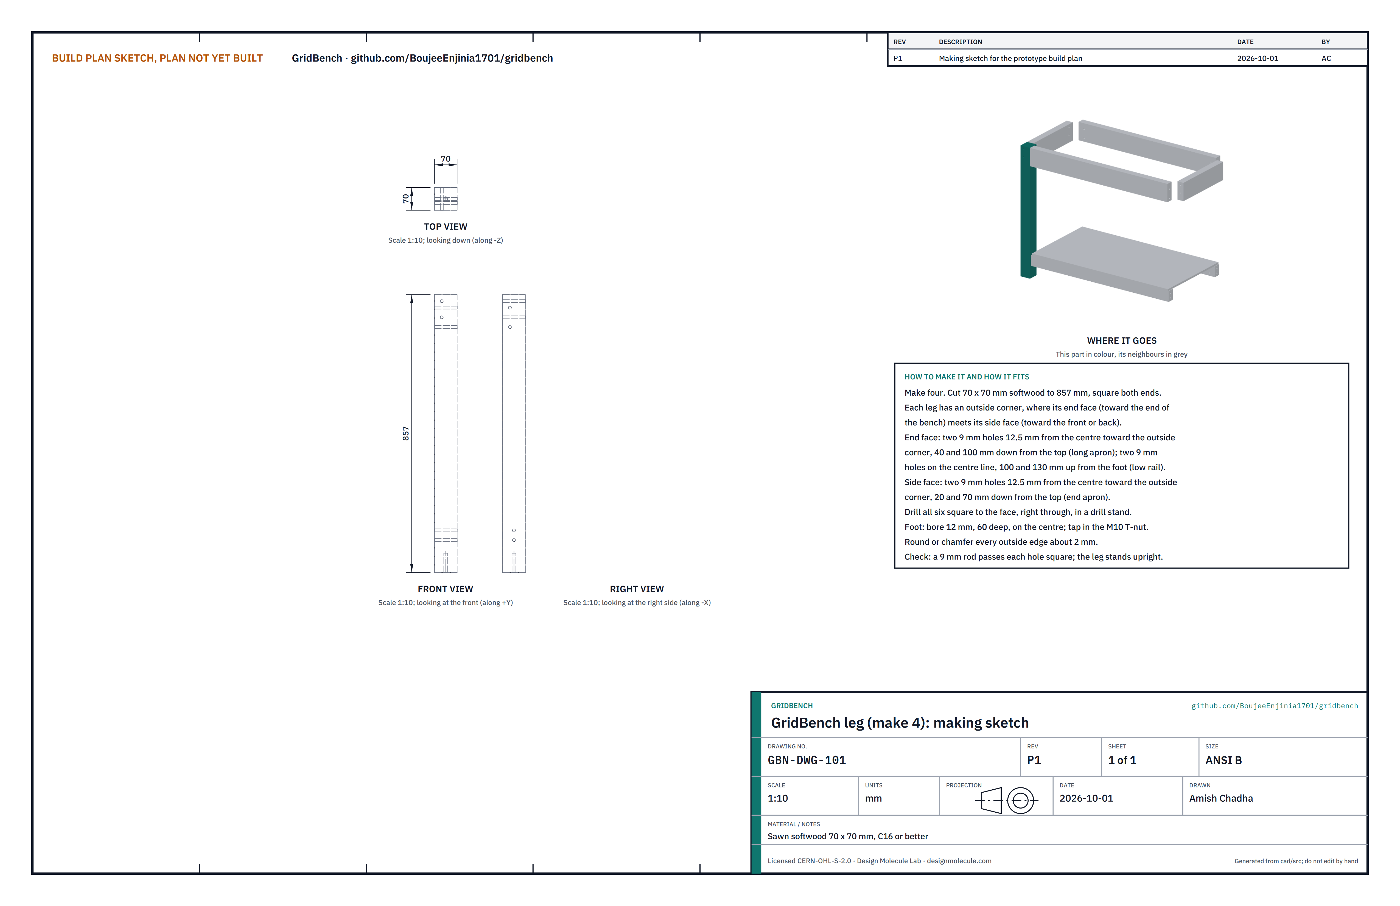
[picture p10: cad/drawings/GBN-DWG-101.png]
Figure 2. Making sketch of the leg


*Figure 2. Leg making sketch (GBN-DWG-101).*

**What it is and what it is made from.** The four corner posts that carry everything. Sawn softwood 70 x 70 mm, strength class C16 or better, straight and dry.

**How to make it.**

1. Cut four lengths of 857, square at both ends.
2. On each leg, pick the outside corner: the edge where its end face (the face toward the end of the bench) meets its side face (the face toward the front or back). Mark both faces.
3. End face: two 9 mm holes, 12.5 from the centre line toward the outside corner, 40 and 100 down from the top (for the long apron). Two 9 mm holes on the centre line, 100 and 130 up from the foot (for the low rail).
4. Side face: two 9 mm holes, 12.5 from the centre line toward the outside corner, 20 and 70 down from the top (for the end apron).
5. Drill all six right through, square to the face, in a drill stand or with a drilling guide.
6. Foot: bore 12 mm, 60 deep, on the centre of the bottom end. Tap an M10 T-nut into it until its flange is flat on the end.
7. Round or chamfer every outside edge about 2 mm.

**How it fits the parts next to it.**

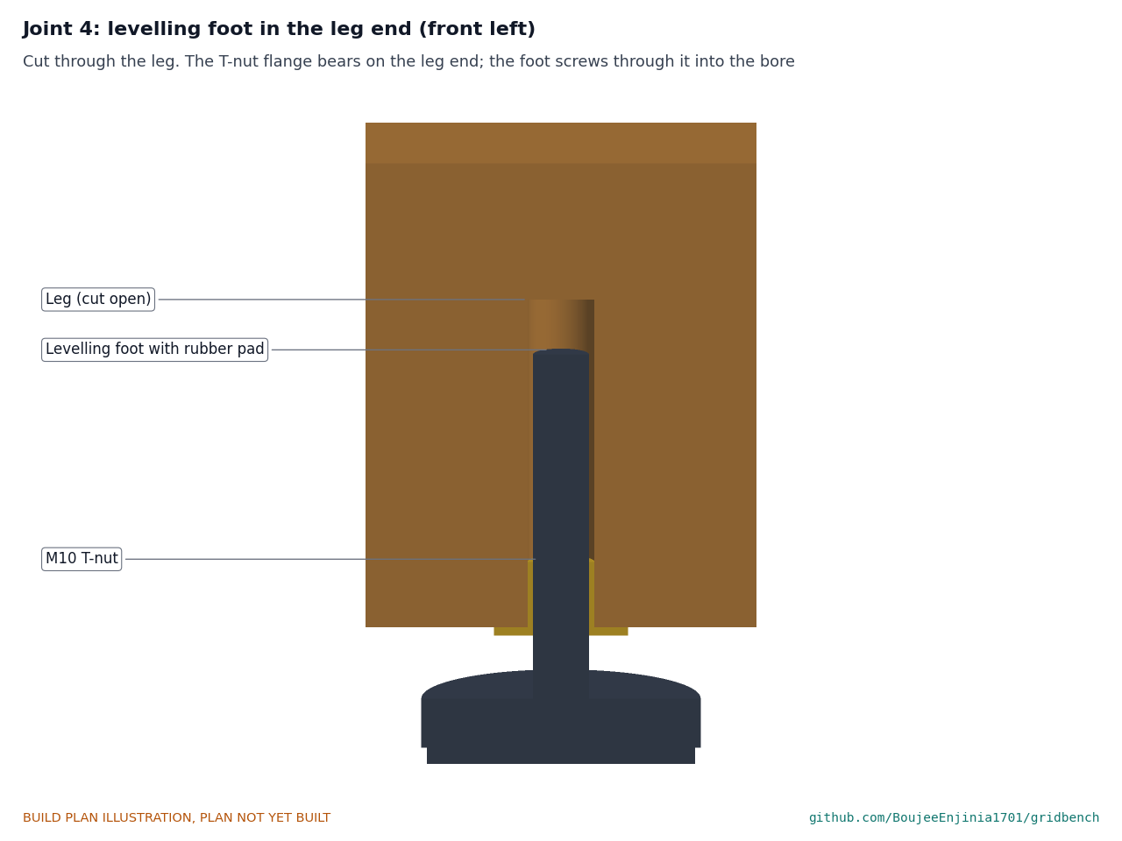
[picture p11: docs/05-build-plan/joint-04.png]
Figure 3. Joint 4: levelling foot in the leg end


*Figure 3. The T-nut flange bears on the leg end; the foot screws through the T-nut into the bore.*

The aprons and low rails butt against the leg's inside faces, flush with its top and outside faces, and are bolted through it (Figure 5). The levelling foot screws into the T-nut; set it with 13 mm of thread showing, which leaves 15 mm of adjustment up or down.

**Check before moving on.** A 9 mm rod passes through each hole square; the leg stands upright on its foot.

### 3.2 End aprons (make 2)

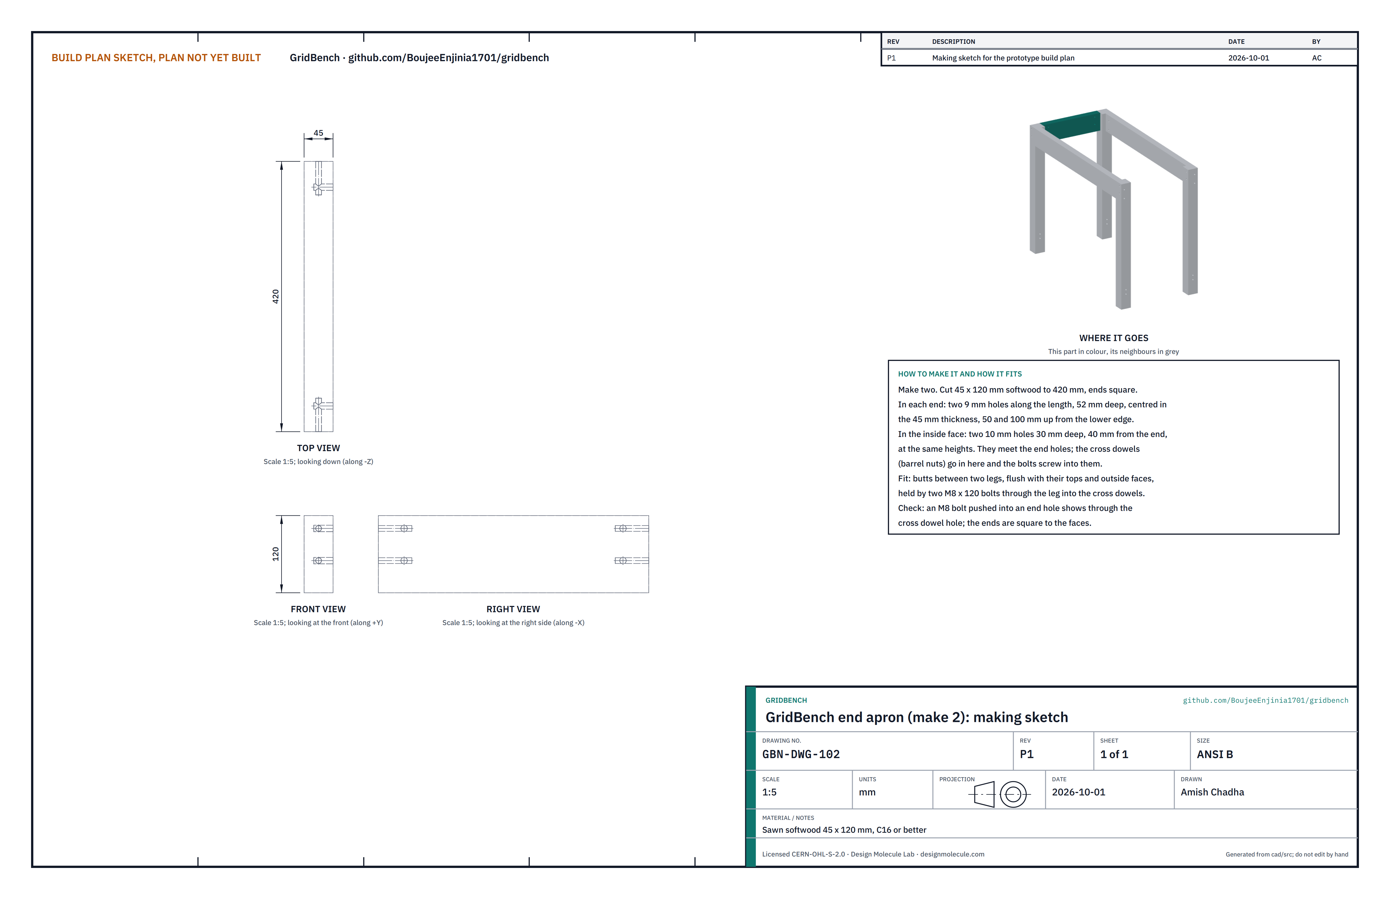
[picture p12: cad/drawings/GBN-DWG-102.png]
Figure 4. Making sketch of the end apron


*Figure 4. End apron making sketch (GBN-DWG-102).*

**What it is and what it is made from.** The deep rail across each end of the bench, under the worktop. Sawn softwood 45 x 120 mm, C16 or better.

**How to make it.**

1. Cut two lengths of 420, ends square.
2. In each end: two 9 mm holes along the length, 52 deep, centred in the 45 mm thickness, 50 and 100 up from the lower edge. A drilling guide or a drill stand on its side keeps them straight.
3. In the inside face: two 10 mm holes, 30 deep, 40 in from each end, at the same heights. Each meets an end hole; an M8 cross dowel goes in here, and the bolt from the leg screws into it.

**How it fits the parts next to it.**

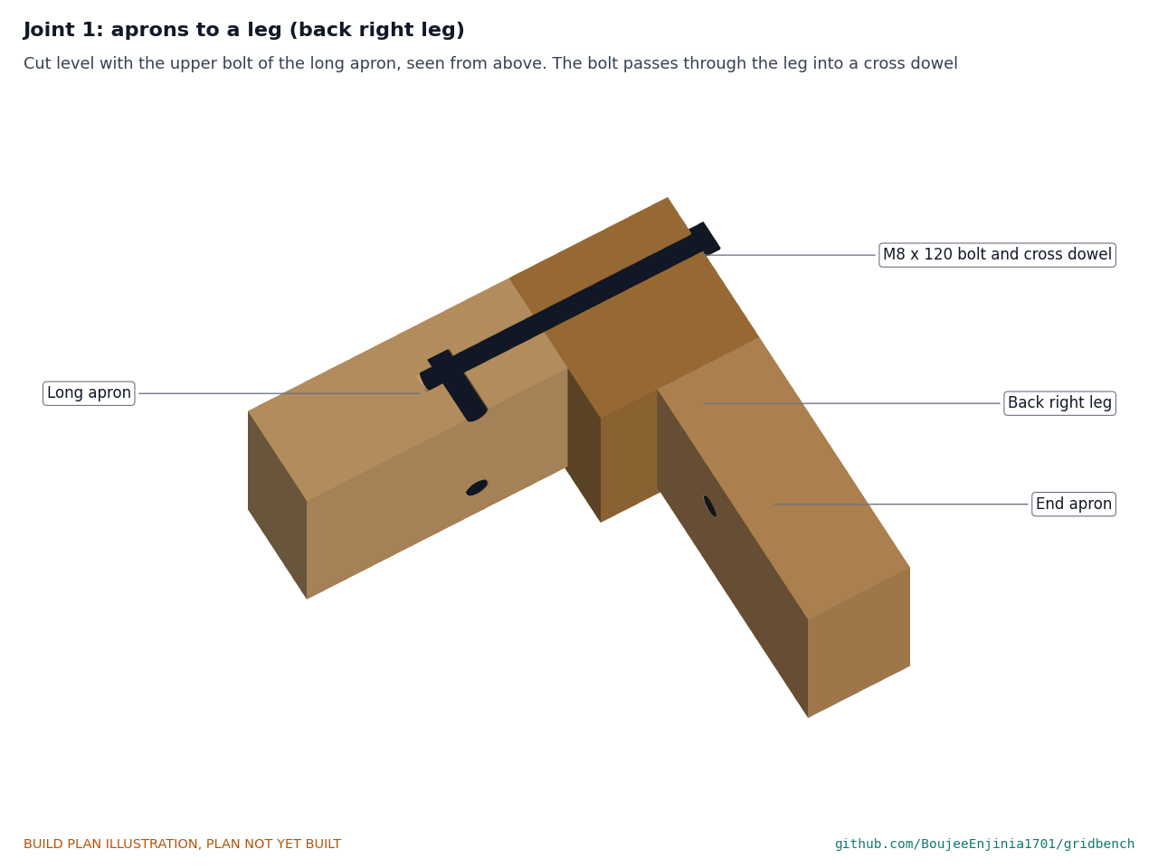
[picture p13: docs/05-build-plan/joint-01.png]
Figure 5. Joint 1: aprons to a leg


*Figure 5. Cut level with a long apron bolt, seen from above: each bolt passes through the leg into a cross dowel in the apron.*

Each end apron butts between two legs, flush with their tops and outside faces. Two M8 x 120 hex bolts with washers go through the leg's side face into the cross dowels. The end apron bolts sit at different heights from the long apron bolts, so the two pairs miss each other inside the leg.

**Check before moving on.** An M8 bolt pushed into an end hole shows through the cross dowel hole; the ends are square to the faces.

### 3.3 Long aprons (make 2)

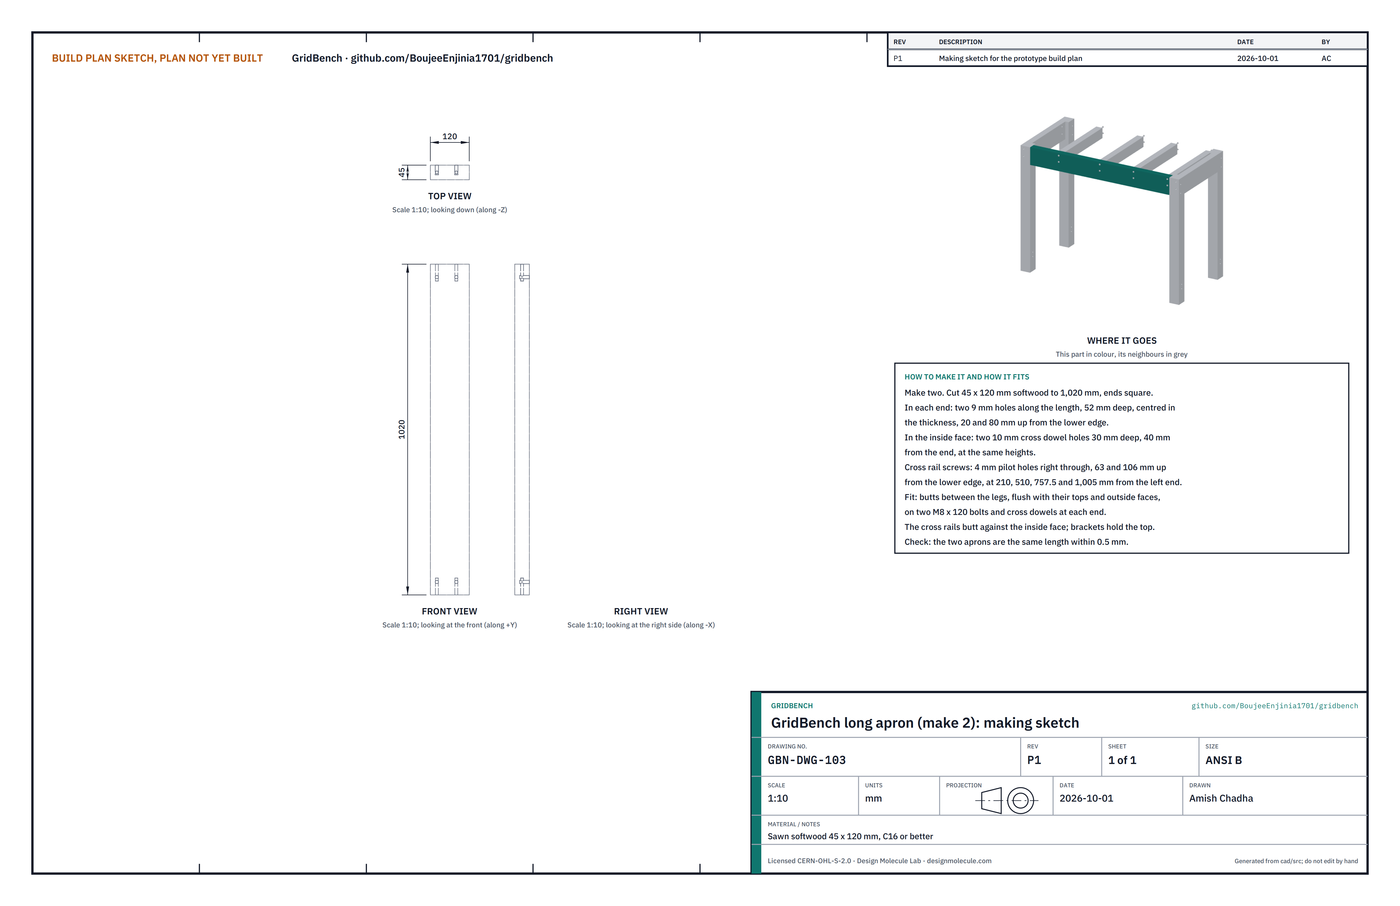
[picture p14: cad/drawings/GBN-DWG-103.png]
Figure 6. Making sketch of the long apron


*Figure 6. Long apron making sketch (GBN-DWG-103), drawn standing on end.*

**What it is and what it is made from.** The deep rails along the front and back, which carry most of the worktop. Sawn softwood 45 x 120 mm, C16 or better.

**How to make it.**

1. Cut two lengths of 1,020, ends square. The two must match within 0.5.
2. In each end: two 9 mm holes along the length, 52 deep, centred in the thickness, 20 and 80 up from the lower edge.
3. In the inside face: two 10 mm cross dowel holes, 30 deep, 40 in from each end, at the same heights.
4. Cross rail screw holes: 4 mm pilot holes right through, 63 and 106 up from the lower edge, at 210, 510, 757.5 and 1,005 from the left end.

**How it fits the parts next to it.** It butts between the legs like the end apron (Figure 5), on two bolts and cross dowels at each end. The cross rails butt against its inside face (Figure 10), and the worktop brackets screw to its inside face (Figure 16).

**Check before moving on.** Both aprons the same length within 0.5; the pilot holes line up when the two are laid side by side.

### 3.4 Low rails (make 2)

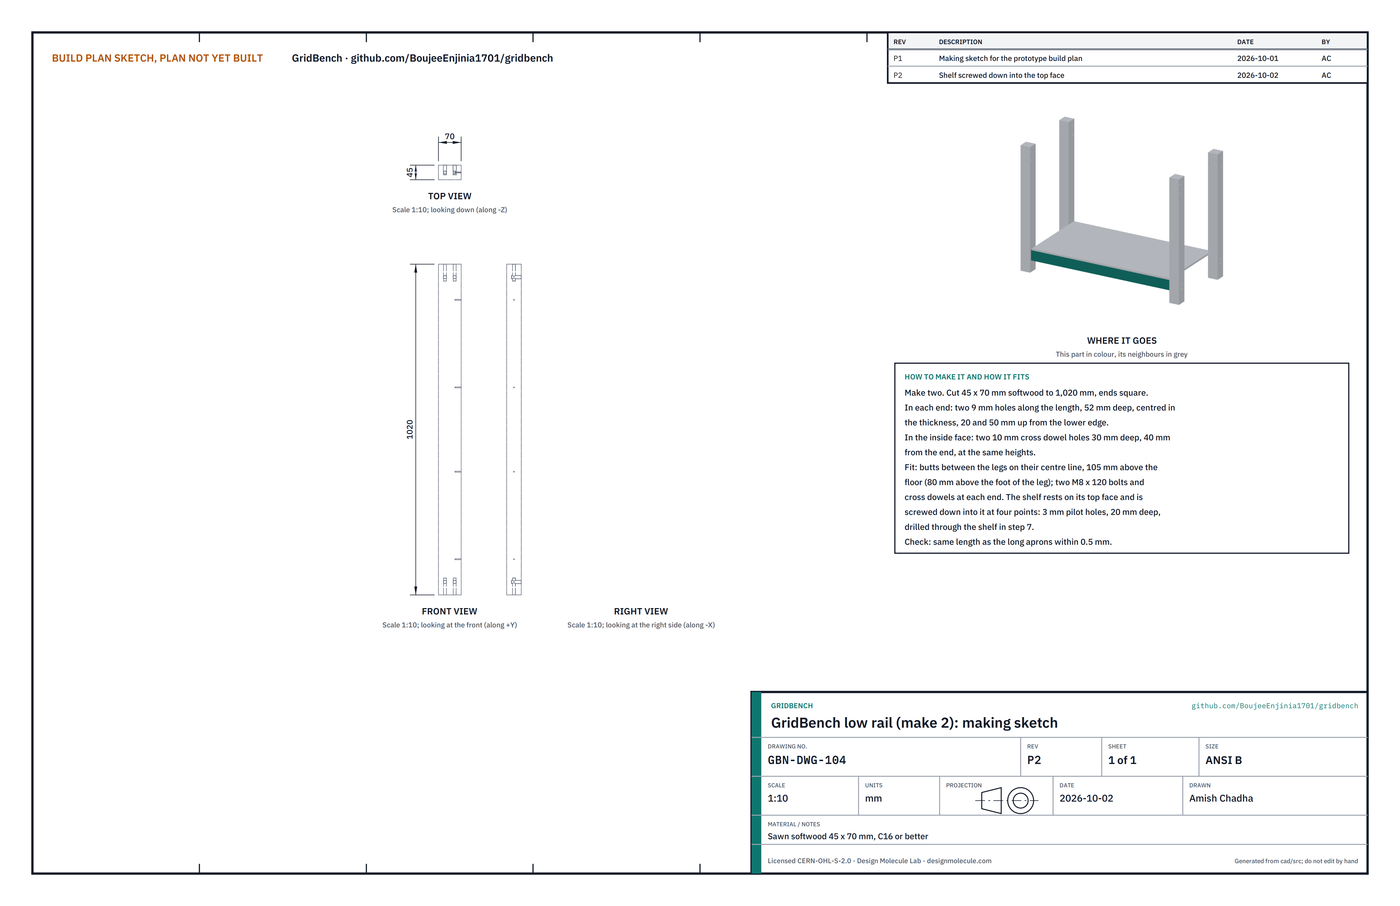
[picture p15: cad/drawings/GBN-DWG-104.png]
Figure 7. Making sketch of the low rail


*Figure 7. Low rail making sketch (GBN-DWG-104), drawn standing on end.*

**What it is and what it is made from.** The front and back rails near the floor that carry the shelf and the ballast. Sawn softwood 45 x 70 mm, C16 or better.

**How to make it.**

1. Cut two lengths of 1,020, ends square.
2. In each end: two 9 mm holes along the length, 52 deep, centred in the thickness, 20 and 50 up from the lower edge.
3. In the inside face: two 10 mm cross dowel holes, 30 deep, 40 in from each end, at the same heights.

**How it fits the parts next to it.**

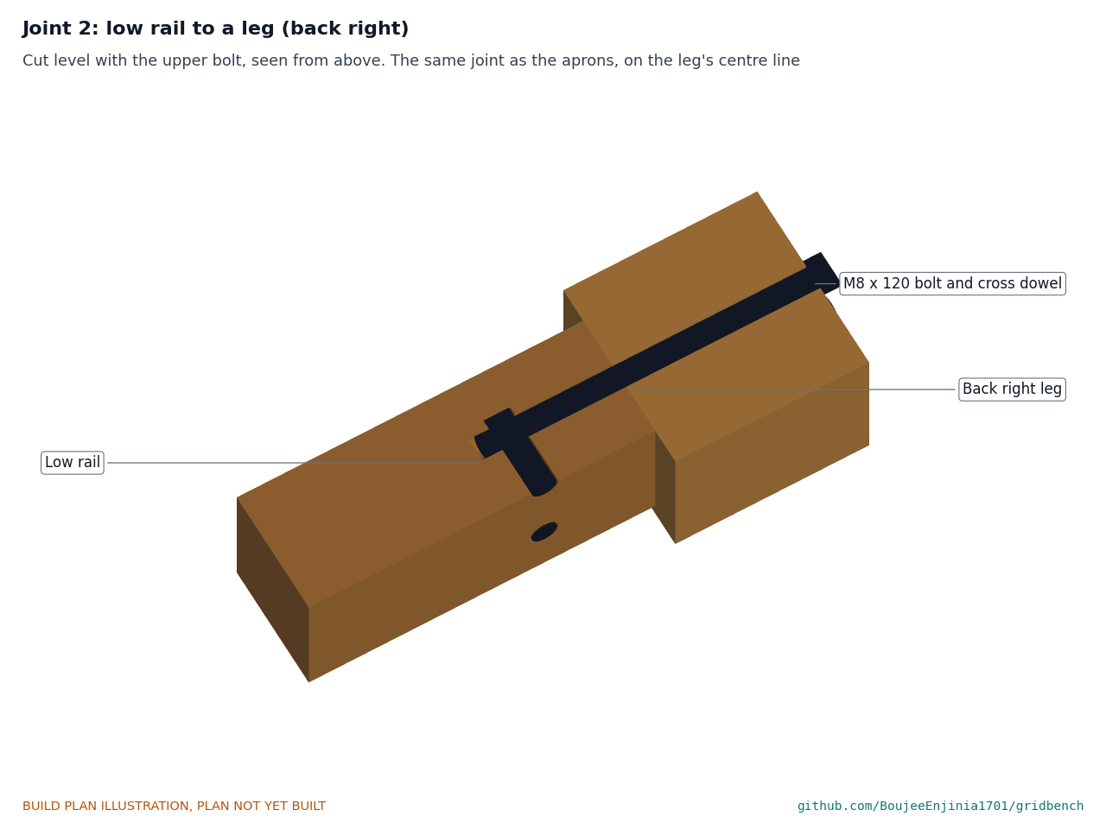
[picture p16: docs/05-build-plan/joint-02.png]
Figure 8. Joint 2: low rail to a leg


*Figure 8. Cut level with the upper bolt: the same bolt and cross dowel joint as the aprons, on the leg's centre line.*

The rail butts between the legs on their centre line, its lower edge 105 above the floor (80 above the foot of the leg). The shelf rests on its top face and is screwed down into it at four points (step 7).

**Check before moving on.** Same length as the long aprons within 0.5.

### 3.5 Cross rails (make 4; one notched)

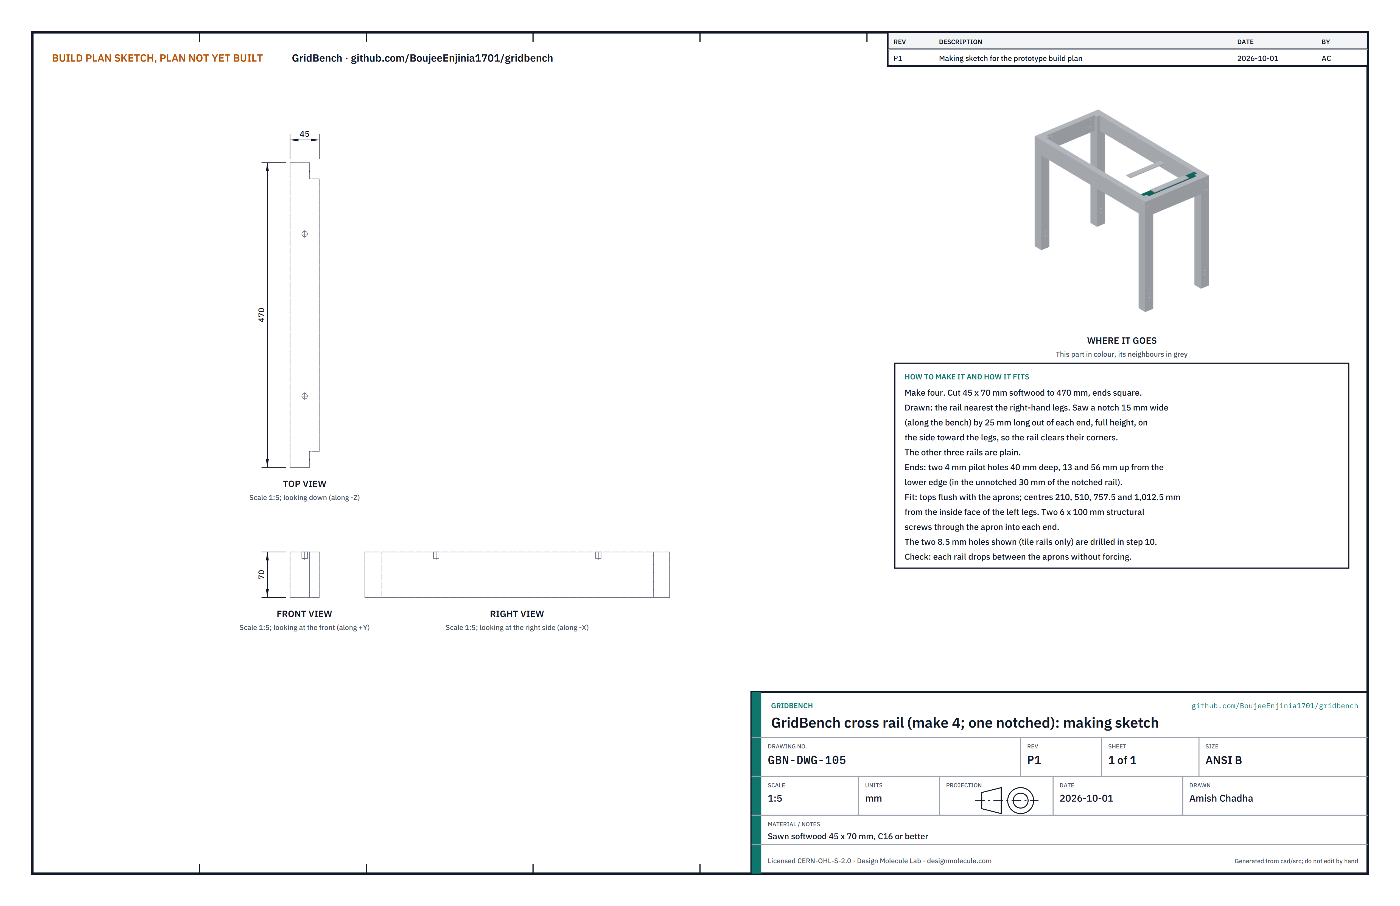
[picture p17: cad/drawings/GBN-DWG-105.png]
Figure 9. Making sketch of the cross rail


*Figure 9. Cross rail making sketch (GBN-DWG-105), drawn for the notched rail.*

**What it is and what it is made from.** Four rails from front to back under the worktop. They split it into bays no wider than 255, and the two on the right carry the precision tile. Sawn softwood 45 x 70 mm, C16 or better.

**How to make it.**

1. Cut four lengths of 470, ends square.
2. Take the rail that will sit nearest the right-hand legs. At each end, on the side toward the legs, saw out a notch 15 wide (along the bench) and 25 long, full height, so the rail clears the leg corners.
3. Ends of all four: two 4 mm pilot holes, 40 deep, 13 and 56 up from the lower edge (in the unnotched 30 mm of the notched rail).

**How it fits the parts next to it.**

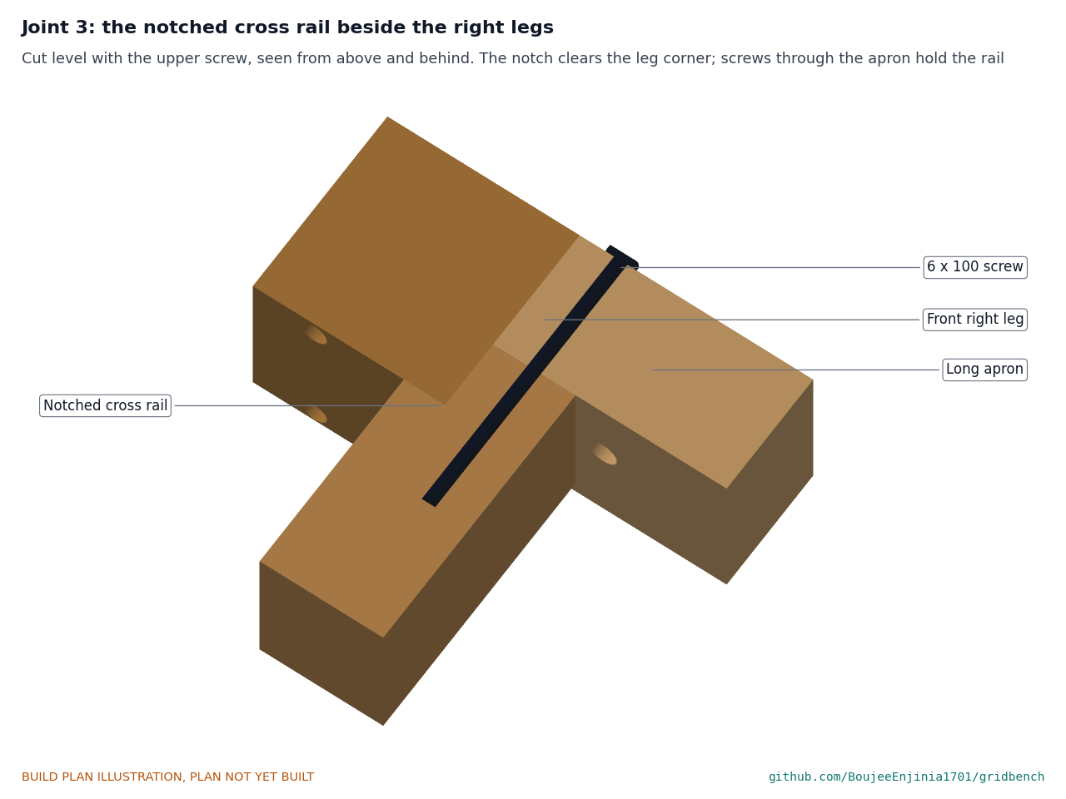
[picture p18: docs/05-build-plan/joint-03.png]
Figure 10. Joint 3: the notched cross rail beside the right legs


*Figure 10. Cut level with the upper screw: the notch clears the leg corner, and screws through the apron hold the rail.*

The rails butt between the long aprons with their tops flush, centred 210, 510, 757.5 and 1,012.5 from the inside face of the left legs. Two 6 x 100 structural screws go through the apron into each rail end. The two right-hand rails are the tile rails; their insert holes are drilled in step 10.

**Check before moving on.** Each rail drops between the aprons without forcing and its top is flush with theirs.

### 3.6 Packers under the tile (make 2)

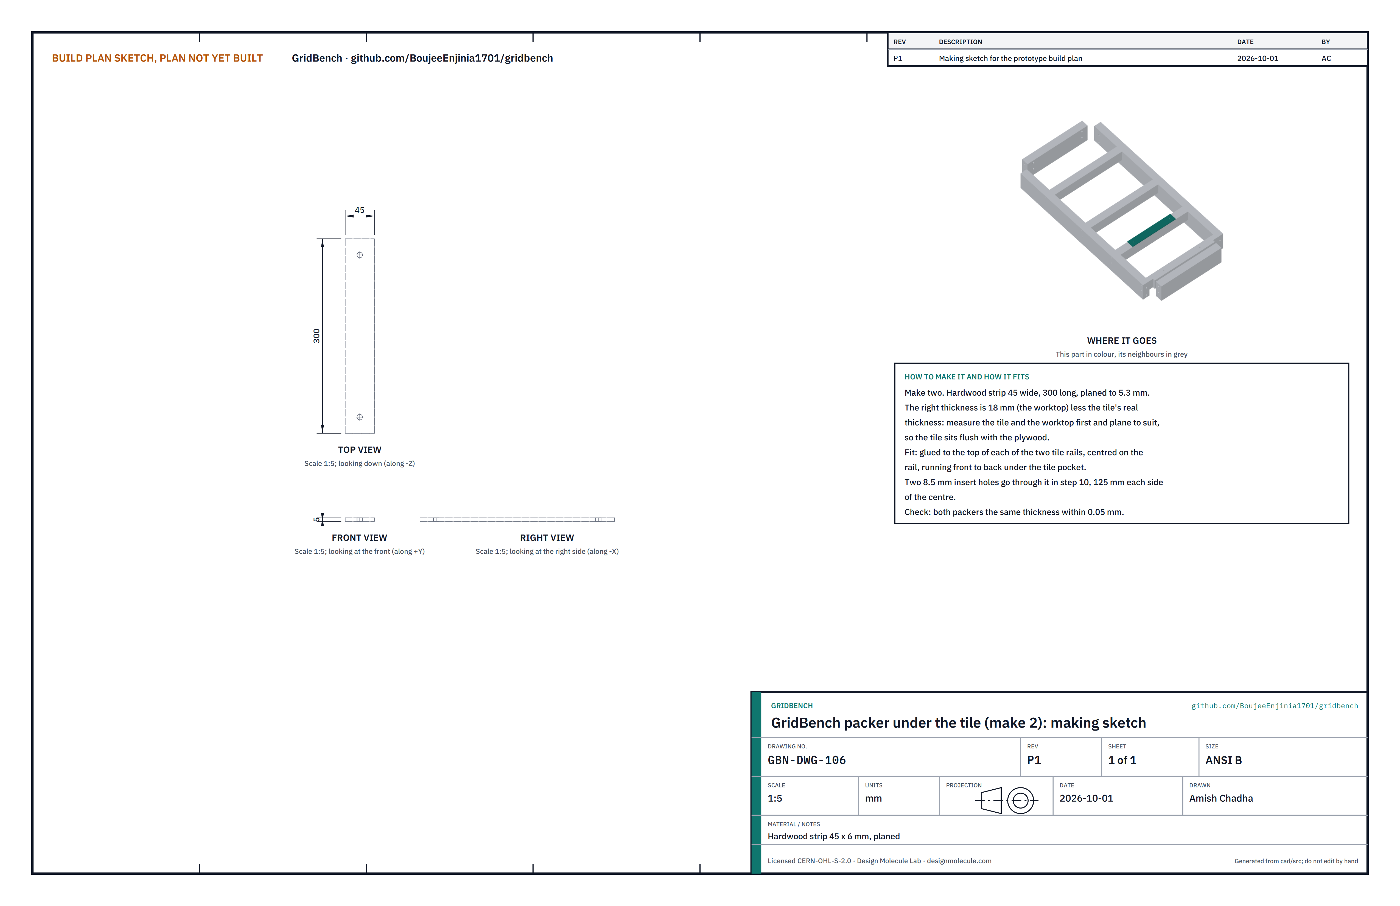
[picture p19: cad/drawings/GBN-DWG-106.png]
Figure 11. Making sketch of the packer


*Figure 11. Packer making sketch (GBN-DWG-106).*

**What it is and what it is made from.** Two thin hardwood strips on the tile rails that bring the tile up flush with the plywood. Hardwood strip 45 wide, about 6 thick, planed.

**How to make it.**

1. Measure the tile's thickness and the worktop's thickness. The packer thickness is the worktop's less the tile's: 5.3 for a 12.7 tile in 18 plywood.
2. Cut two lengths of 300 and plane both to that thickness, within 0.05.

**How it fits the parts next to it.** Each packer is glued centred on the top of a tile rail, running front to back under the tile pocket. The tile rests on both packers (Figure 18).

**Check before moving on.** Both packers the same thickness within 0.05.

### 3.7 Shelf

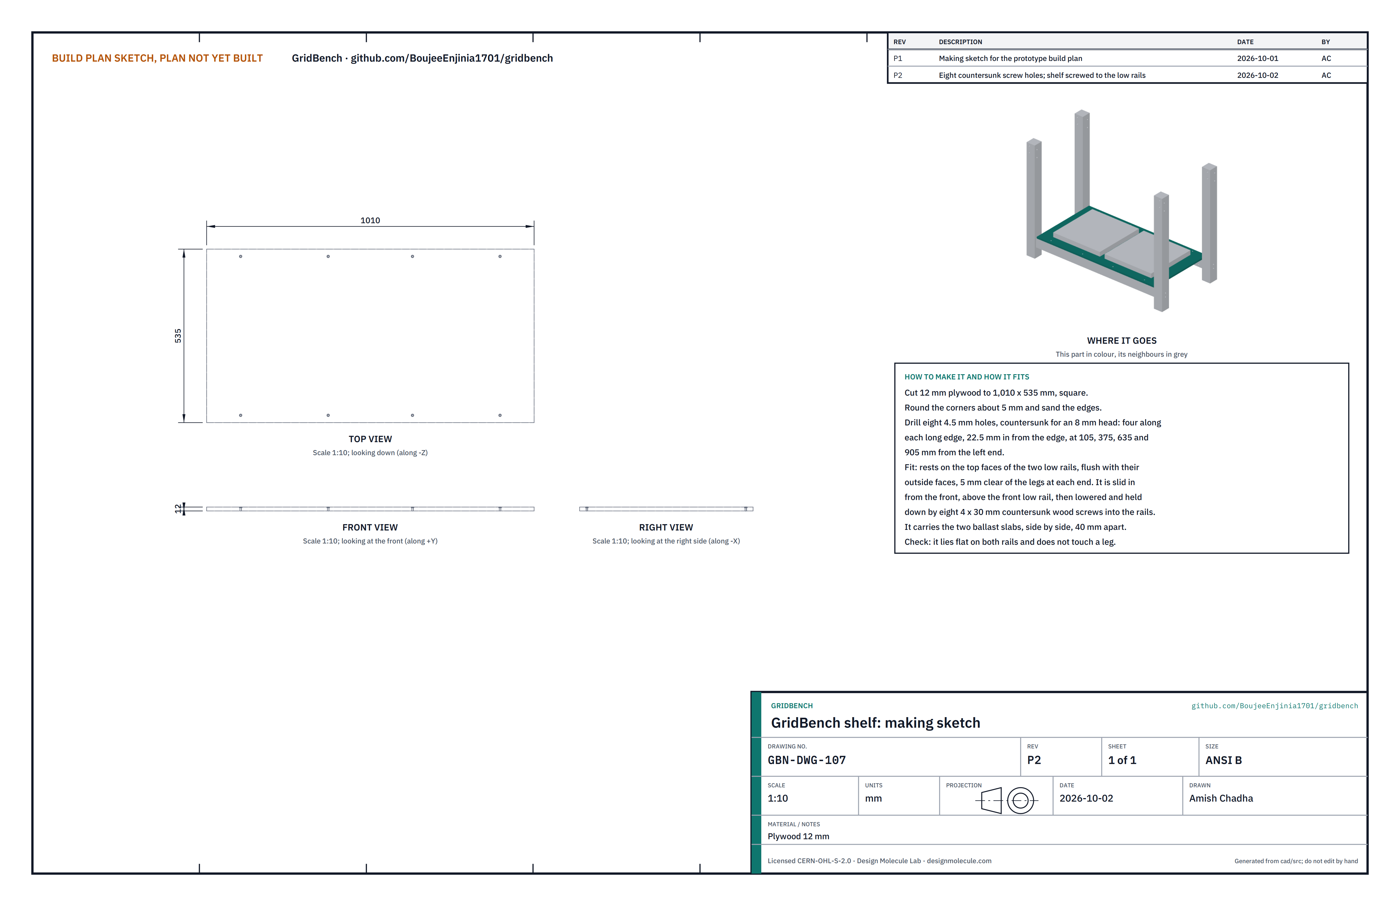
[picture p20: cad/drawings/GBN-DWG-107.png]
Figure 12. Making sketch of the shelf


*Figure 12. Shelf making sketch (GBN-DWG-107).*

**What it is and what it is made from.** The lower shelf that carries the ballast. Plywood 12 mm.

**How to make it.**

1. Cut 1,010 x 535, square; round the corners about 5 and sand the edges.
2. Drill eight 4.5 holes, countersunk for an 8 head: four along each long edge on a line 22.5 in from the edge (over the middle of the low rail), at 105, 375, 635 and 905 from the left end.

**How it fits the parts next to it.** It rests on the top faces of the two low rails, flush with their outside faces, 5 clear of the legs at each end. It goes in from the front, above the front low rail, and is lowered onto both rails (step 7). Eight 4 x 30 countersunk wood screws, four into each rail, hold it down, so that the shelf braces the frame against racking. The screws sit clear of the ballast slabs.

**Check before moving on.** It lies flat on both rails and touches no leg; every hole lands over the middle of a rail.

### 3.8 Worktop

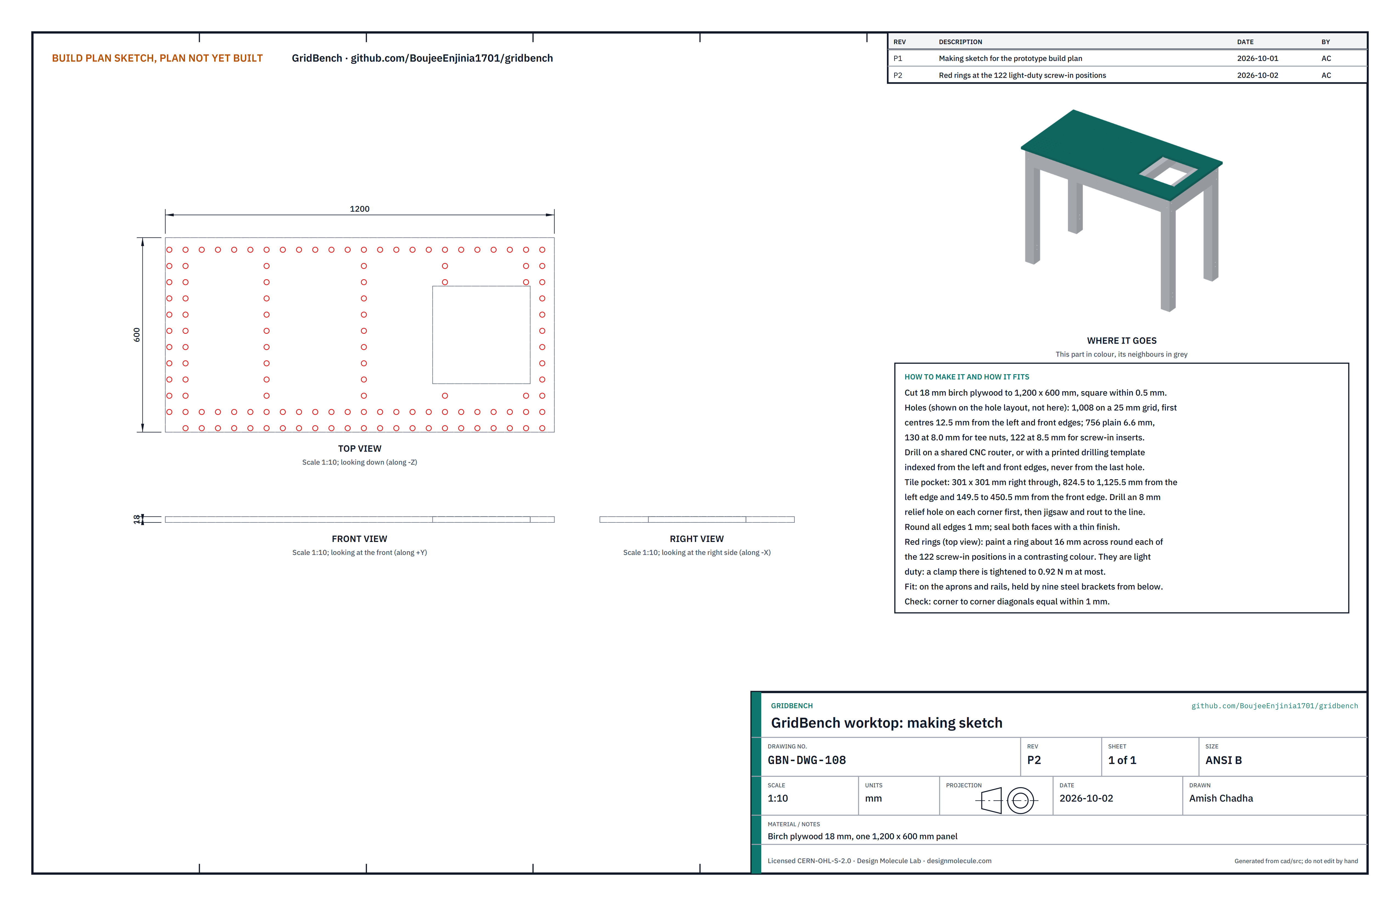
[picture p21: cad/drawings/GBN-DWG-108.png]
Figure 13. Making sketch of the worktop


*Figure 13. Worktop making sketch (GBN-DWG-108); the holes are on the hole layout, Figure 14.*

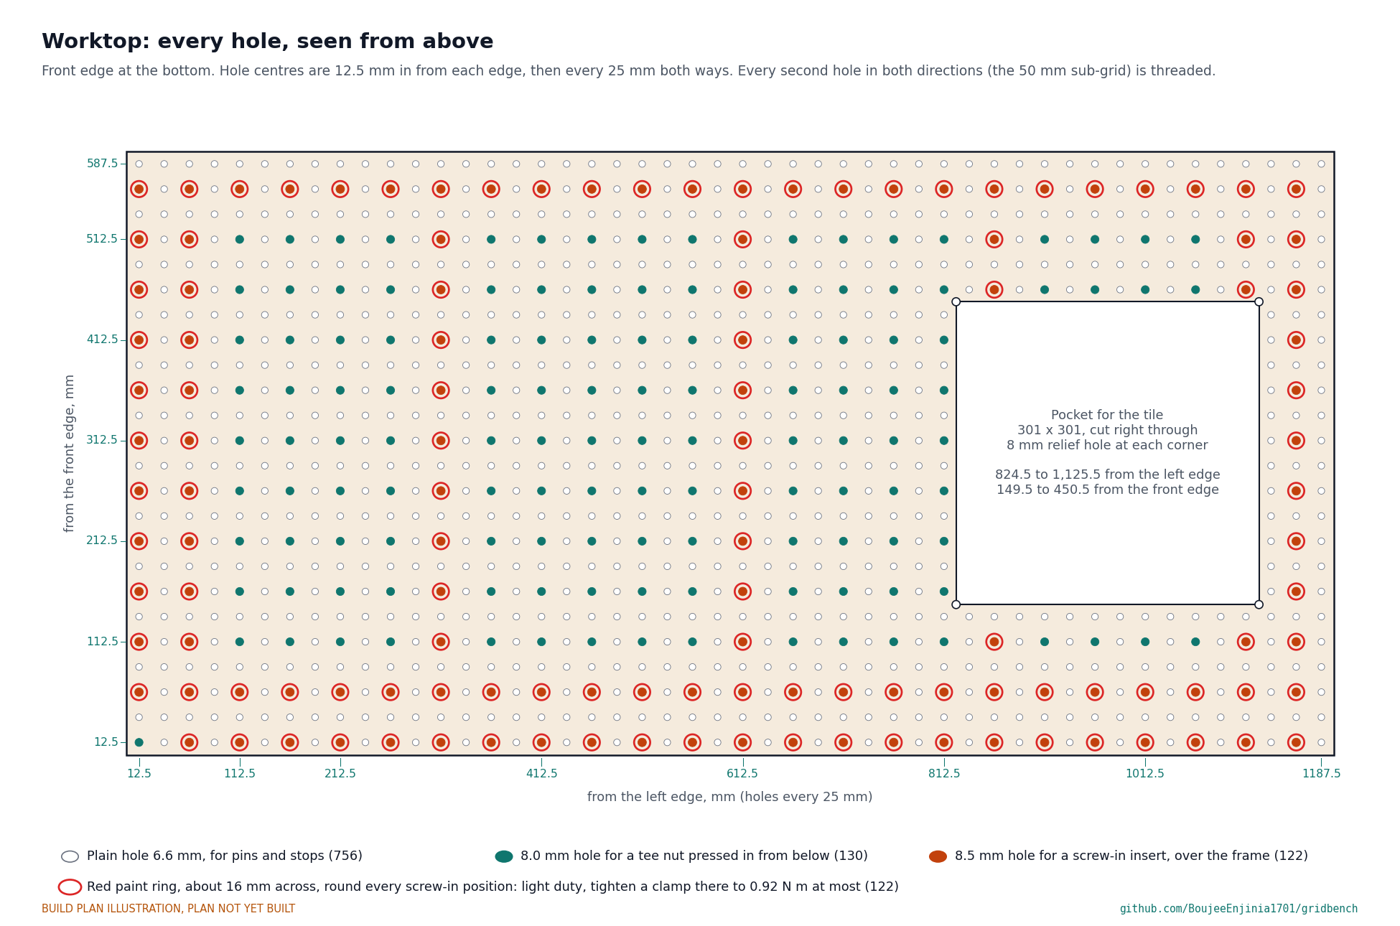
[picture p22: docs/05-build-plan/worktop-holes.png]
Figure 14. Every hole in the worktop


*Figure 14. Every hole, seen from above with the front edge at the bottom: plain holes, tee nut holes and screw-in insert holes, each screw-in position ringed in red paint as light duty.*

**What it is and what it is made from.** The working surface: a plywood panel drilled on the 25 mm grid, with a pocket for the precision tile. Birch plywood 18 mm, one 1,200 x 600 panel.

**How to make it.**

1. Cut the panel to 1,200 x 600, square within 0.5 (measure both diagonals).
2. Mark the front edge and the left edge: every hole is measured from these two.
3. Hole centres are 12.5 from the left and front edges, then every 25 both ways: 48 along and 24 back. Every second hole in both directions (the 50 mm sub-grid) is threaded; the rest are plain.
4. Drill as Figure 14: 756 plain holes of 6.6, 130 holes of 8.0 for tee nuts, and 122 holes of 8.5 for screw-in inserts (the threaded positions that will sit over a frame member). Use a shared CNC router if you can. Otherwise use a printed drilling template indexed from the left and front edges each time, never from the last hole drilled, so errors do not add up.
5. Tile pocket: 301 x 301, right through, from 824.5 to 1,125.5 from the left edge and 149.5 to 450.5 from the front edge. Drill an 8 mm relief hole centred on each corner first, then cut inside the line with a jigsaw and rout to the line against a straightedge.
6. Round every edge 1 mm and seal both faces with a thin finish so the panel takes up moisture evenly.
7. When the finish is dry, ring each of the 122 screw-in insert holes (shown in orange in Figure 14) on the top face with a paint marker in a contrasting colour, a ring about 16 across. These positions are rated light duty: a toe clamp there is tightened to 0.92 N·m at most, which gives 296 to 493 N at the part. Full clamping force is for the tee nut positions and the tile.

**How it fits the parts next to it.**

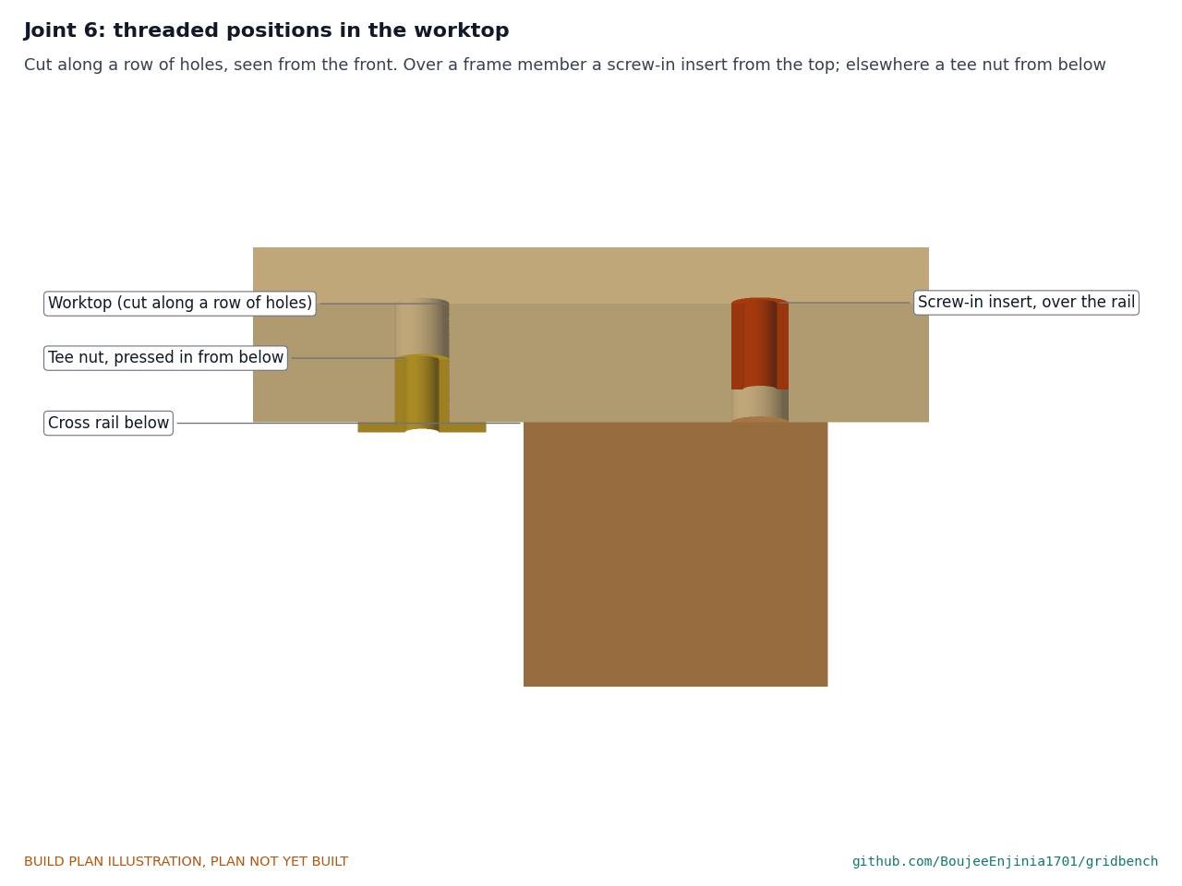
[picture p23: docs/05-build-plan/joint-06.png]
Figure 15. Joint 6: threaded positions in the worktop


*Figure 15. Cut along a row of holes: a tee nut pressed in from below, and a screw-in insert from the top where a cross rail is underneath.*

The tee nuts and inserts go in before the worktop goes on the frame (step 8). The worktop sits on the aprons and rails with 20 overhang all round and is held by nine brackets from below:

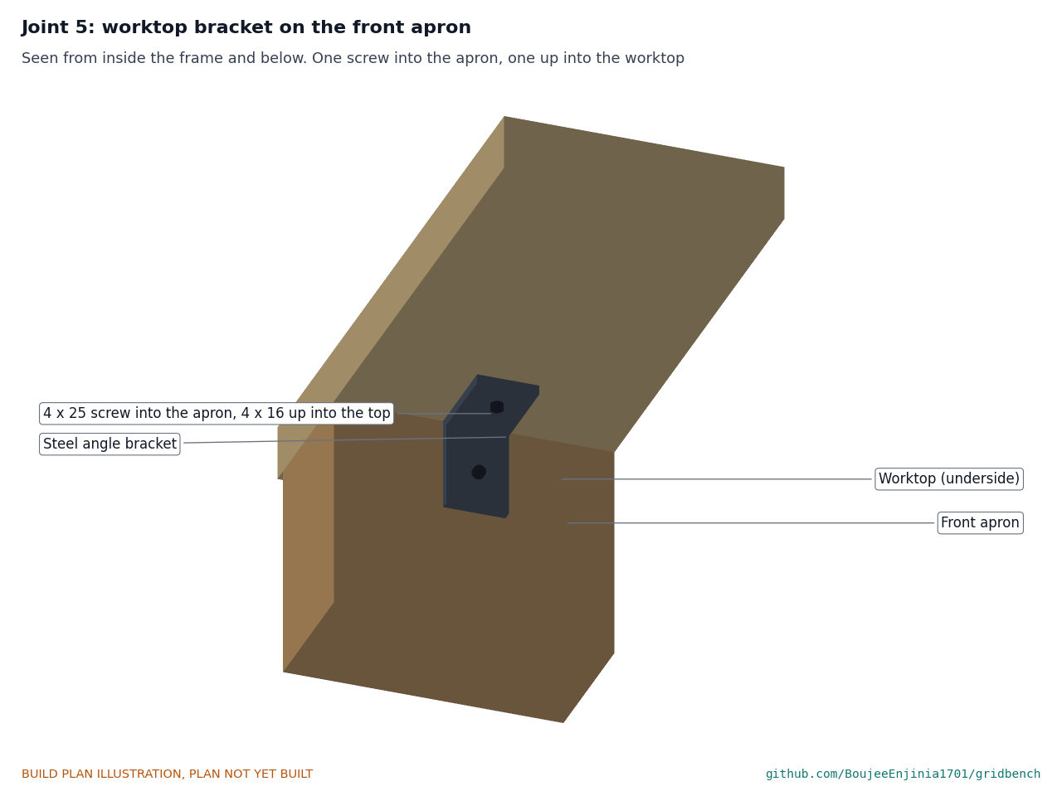
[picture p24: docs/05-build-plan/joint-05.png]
Figure 16. Joint 5: worktop bracket on the front apron


*Figure 16. Each bracket is screwed to the apron's inside face and up into the worktop, midway between two threaded positions.*

**Check before moving on.** Diagonals equal within 1; a 6 mm pin drops into any plain hole; the pocket is 301 within 0.3 both ways; all 122 screw-in positions are ringed and no other hole is.

### 3.9 Precision tile

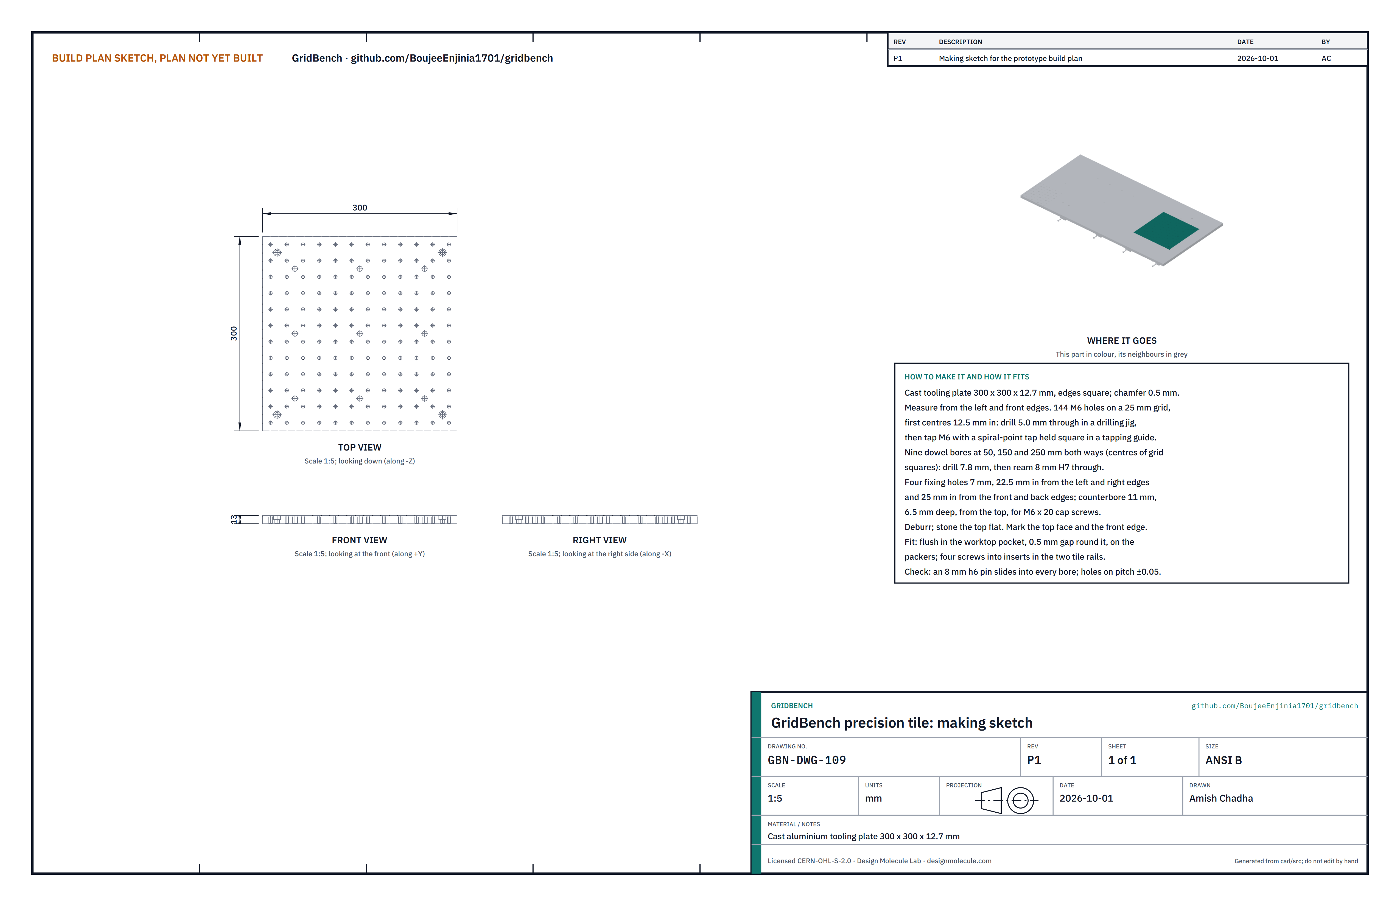
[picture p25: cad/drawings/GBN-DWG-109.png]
Figure 17. Making sketch of the precision tile


*Figure 17. Precision tile making sketch (GBN-DWG-109).*

**What it is and what it is made from.** The flush aluminium plate for work that must repeat to a few hundredths of a millimetre. Cast aluminium tooling plate 300 x 300 x 12.7, bought as an offcut.

**How to make it.**

1. Check the plate is square and flat (a straightedge and 0.05 feeler gauge). Chamfer the top edges 0.5. Mark the top face and the front edge.
2. Measure from the left and front edges. 144 M6 holes on the 25 mm grid, first centres 12.5 in: drill 5.0 right through using a drilling jig on a drill press, then tap M6 with a spiral-point tap held square in a tapping guide, with cutting fluid.
3. Nine dowel bores at 50, 150 and 250 both ways (the centres of grid squares): drill 7.8, then ream 8 mm H7 right through.
4. Four fixing holes of 7.0, 22.5 in from the left and right edges and 25 in from the front and back edges; counterbore each 11 across and 6.5 deep from the top.
5. Deburr every hole and stone the top face flat.

**How it fits the parts next to it.**

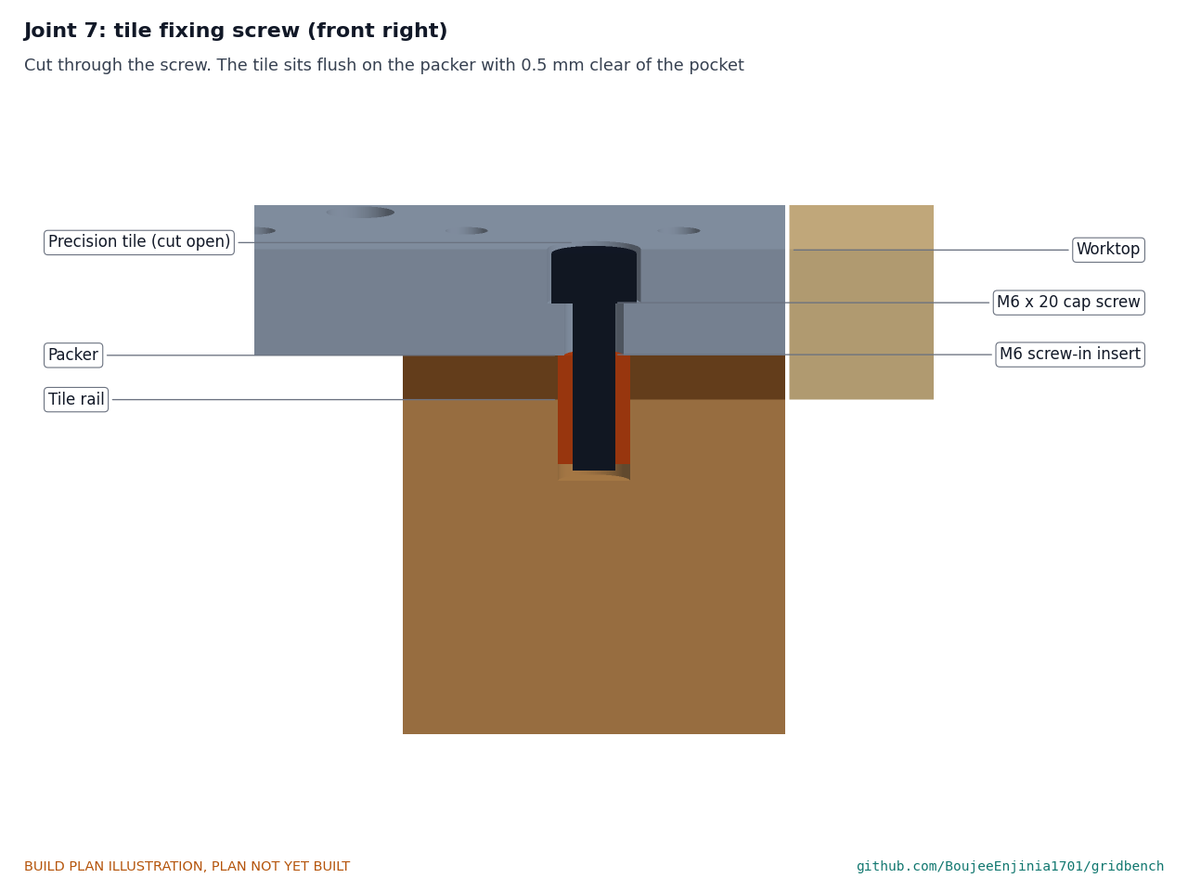
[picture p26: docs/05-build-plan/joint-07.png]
Figure 18. Joint 7: tile fixing screw


*Figure 18. Cut through a fixing screw: the tile sits flush on the packer, 0.5 clear of the pocket, held by a cap screw into an insert in the rail.*

The tile drops into the pocket and rests on the two packers, flush with the plywood. Four M6 x 20 cap screws go through the counterbored holes into screw-in inserts in the tile rails. Its holes continue the plywood grid to within the 0.5 pocket clearance. A screw in the tile must reach no more than 12 below its top face: the holes over the two packers are blind below that.

**Check before moving on.** An 8 mm h6 pin slides into every bore by hand; an M6 screw runs into every tapped hole by hand.

### 3.10 Toe clamps (make 4)

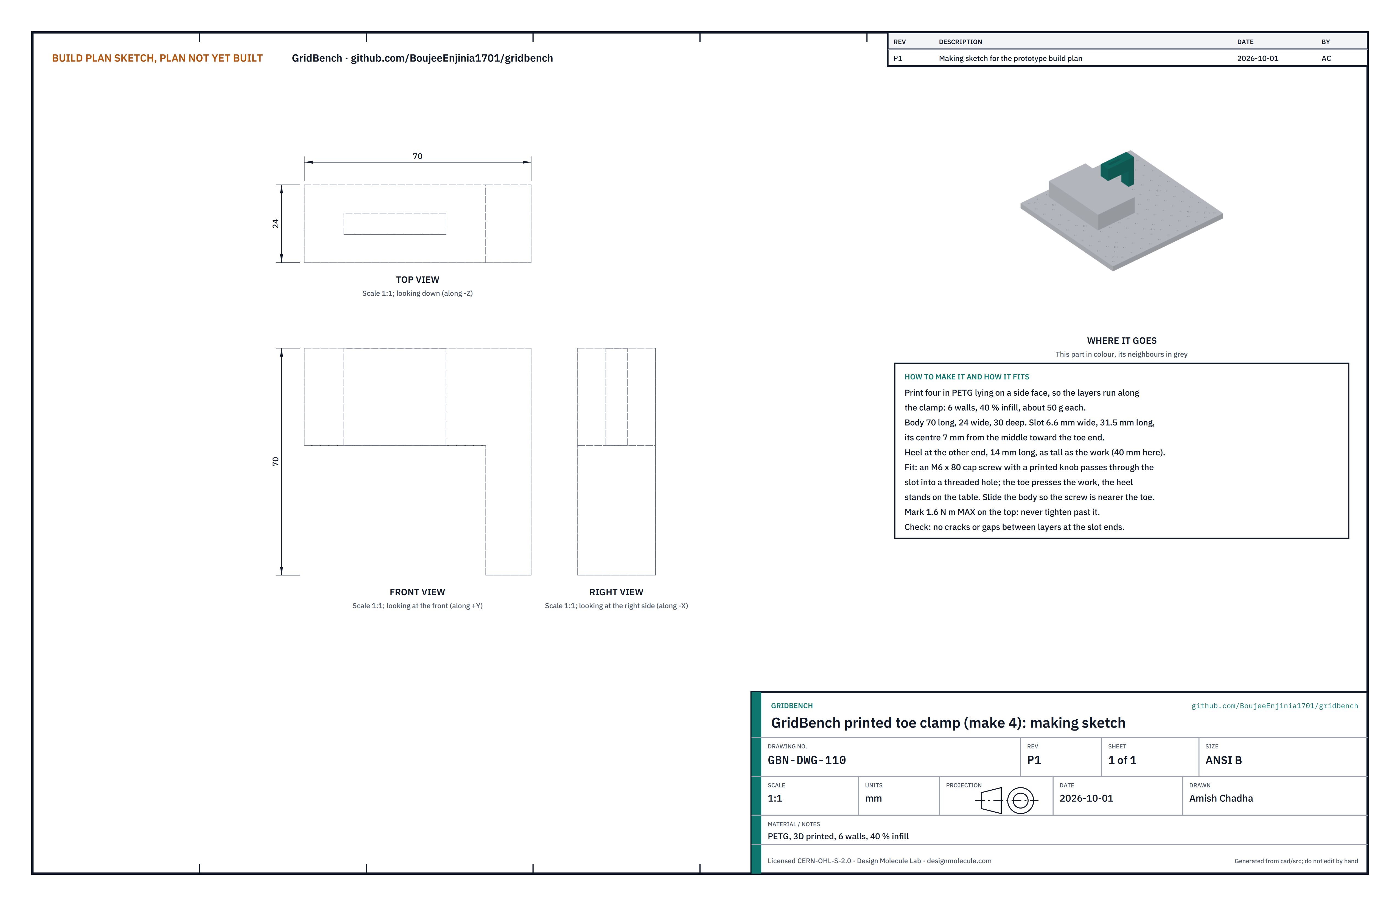
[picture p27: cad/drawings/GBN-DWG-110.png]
Figure 19. Making sketch of the toe clamp


*Figure 19. Toe clamp making sketch (GBN-DWG-110).*

**What it is and what it is made from.** A printed clamp that presses work down onto the tile or the worktop. PETG, printed with 6 walls and 40 % infill.

**How to make it.**

1. Print four lying on a side face, so the layers run along the clamp; about 50 g each.
2. The body is 70 long, 24 wide and 30 deep, with a slot 6.6 wide and 31.5 long whose centre is 7 from the middle toward the toe end. The heel at the other end is 14 long and as tall as the work it is for (40 here; print other heights as needed).
3. Mark "1.6 N·m MAX" on the top.

**How it fits the parts next to it.**

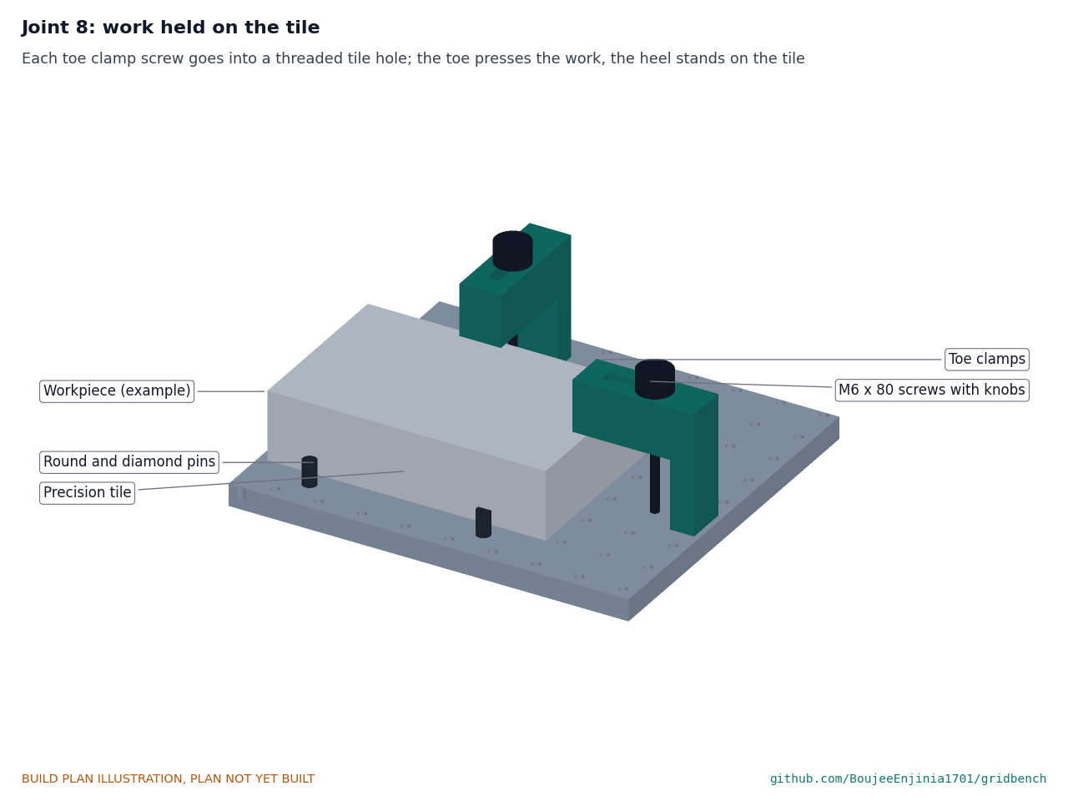
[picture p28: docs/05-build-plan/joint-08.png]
Figure 20. Joint 8: work held on the tile


*Figure 20. Each clamp's screw goes into a threaded tile hole; the toe presses the work and the heel stands on the tile.*

An M6 x 80 cap screw with a printed knob passes through the slot into a threaded hole. Slide the body so the screw is nearer the toe than the heel. Tighten to 1.6 N·m at most.

**Check before moving on.** No cracks or gaps between layers at the slot ends.

### 3.11 Fence segments (make 2)

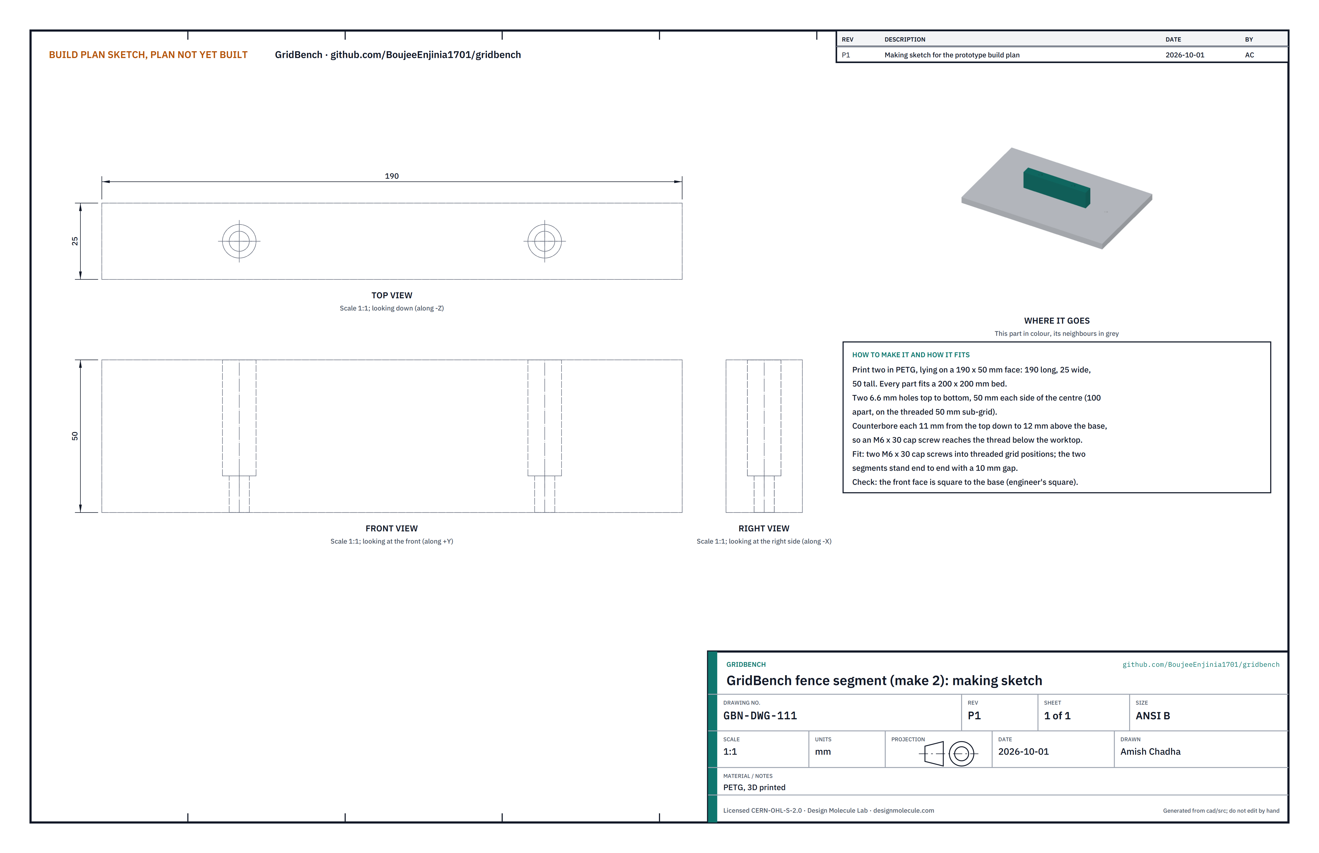
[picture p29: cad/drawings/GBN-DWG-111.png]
Figure 21. Making sketch of the fence segment


*Figure 21. Fence segment making sketch (GBN-DWG-111).*

**What it is and what it is made from.** A straight edge to push work against. PETG, printed.

**How to make it.**

1. Print two lying on a 190 x 50 face: 190 long, 25 wide, 50 tall. They fit a 200 x 200 bed.
2. Two 6.6 holes top to bottom, 50 each side of the centre (100 apart), counterbored 11 from the top down to 12 above the base.

**How it fits the parts next to it.** Each segment stands on two threaded positions, 100 apart, held by two M6 x 30 cap screws. The two stand end to end with a 10 gap. On the plywood, every fixture screw reaches 15 to 18 below the surface, so it engages a tee nut or an insert fully: a 12 floor and an M6 x 30 screw does this.

**Check before moving on.** The front face is square to the base.

### 3.12 V-block

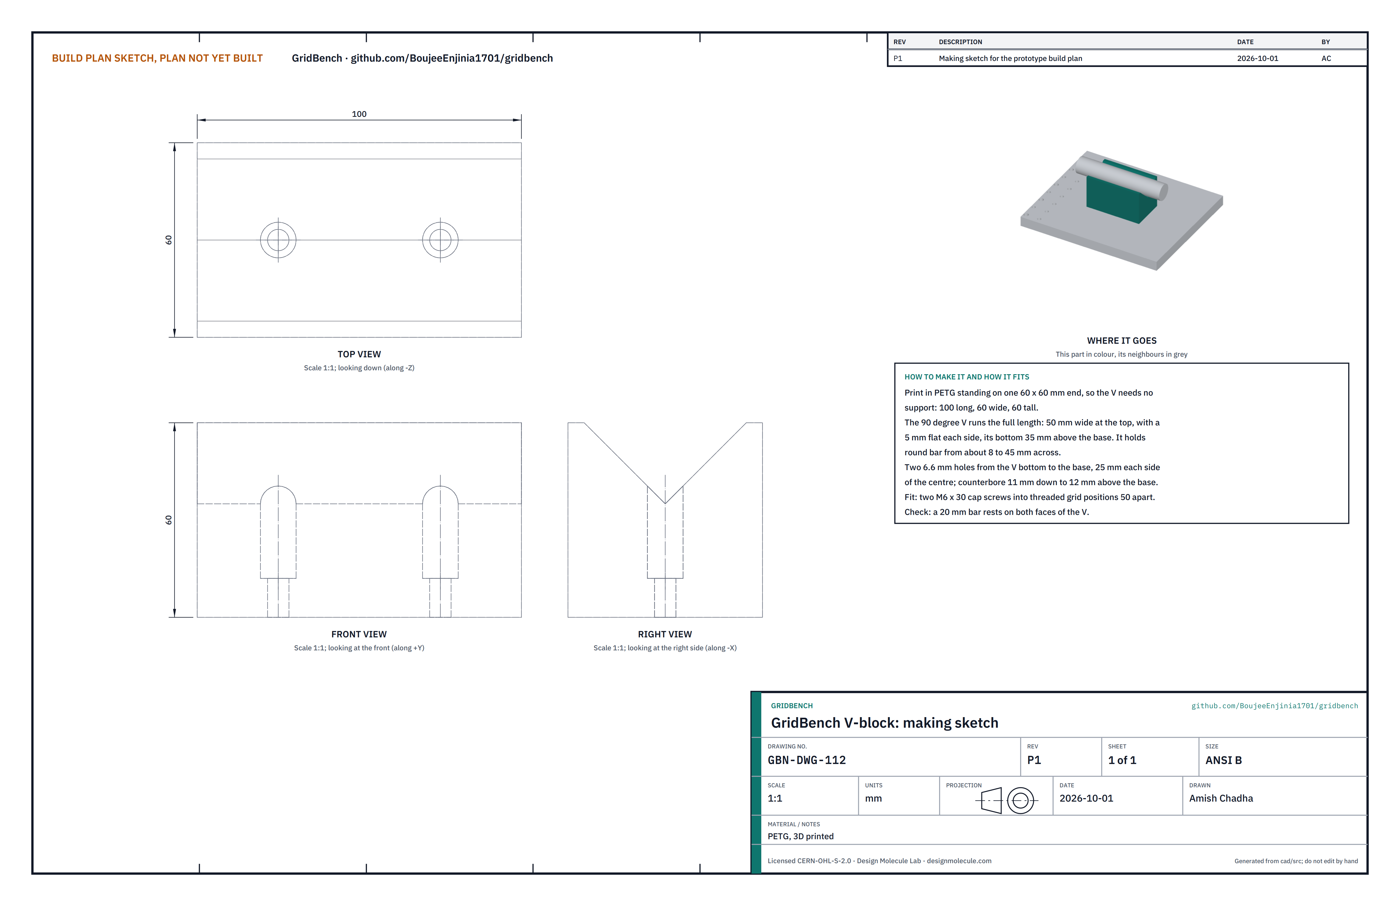
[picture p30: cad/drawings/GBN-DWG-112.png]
Figure 22. Making sketch of the V-block


*Figure 22. V-block making sketch (GBN-DWG-112).*

**What it is and what it is made from.** A block that holds round bar. PETG, printed.

**How to make it.**

1. Print standing on one 60 x 60 end, so the V needs no support: 100 long, 60 wide, 60 tall.
2. The 90° V runs the full length, 50 wide at the top with a 5 flat each side, its bottom 35 above the base. It holds bar from about 8 to 45 across.
3. Two 6.6 holes from the V bottom to the base, 25 each side of the centre, counterbored 11 down to 12 above the base.

**How it fits the parts next to it.** Two M6 x 30 cap screws into threaded positions 50 apart.

**Check before moving on.** A 20 mm bar rests on both faces of the V.

### 3.13 Stop pins (make 6)

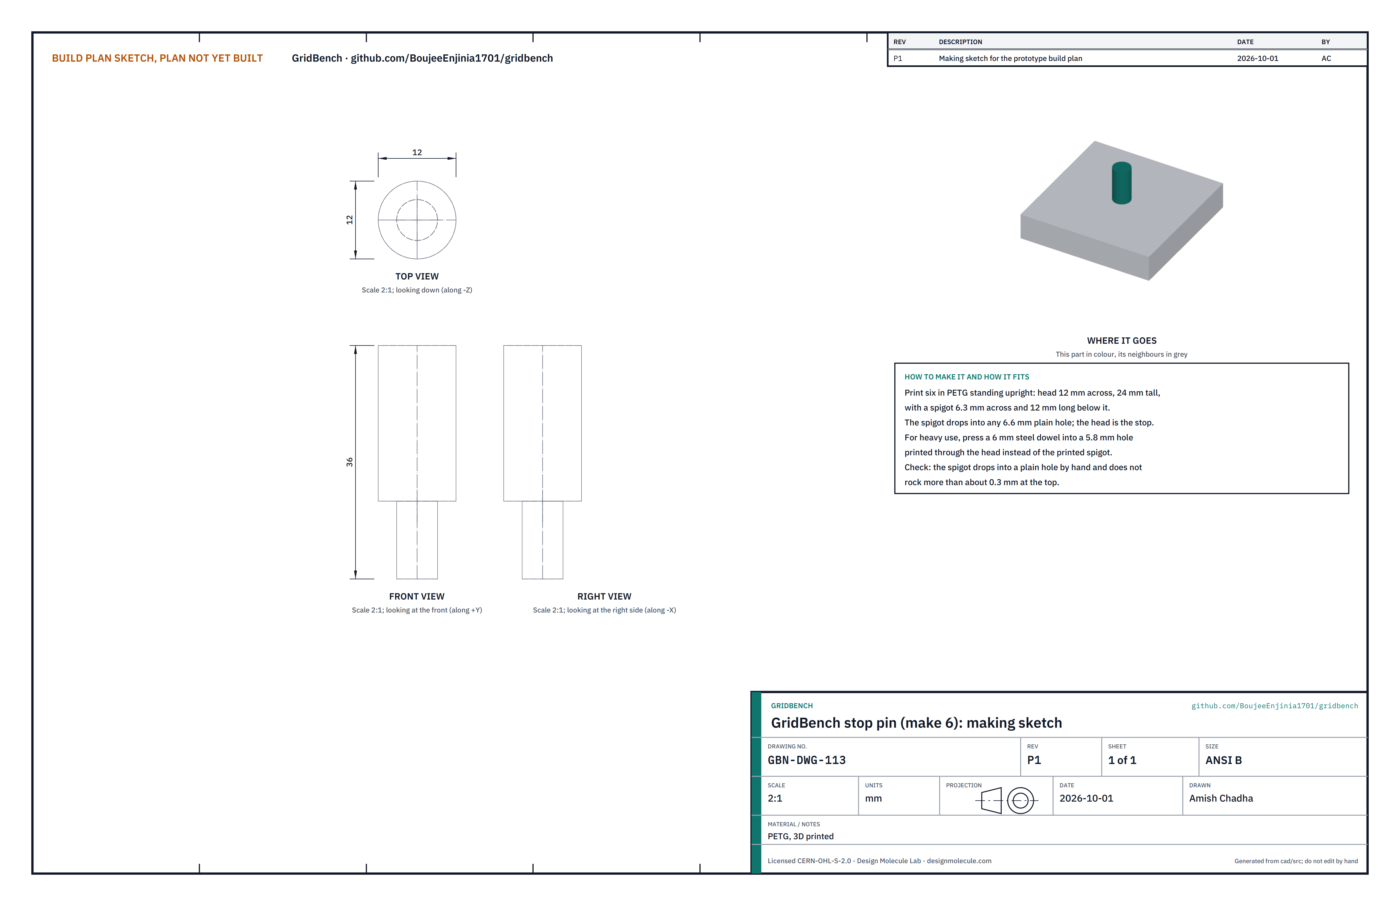
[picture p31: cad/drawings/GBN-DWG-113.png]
Figure 23. Making sketch of the stop pin


*Figure 23. Stop pin making sketch (GBN-DWG-113).*

**What it is and what it is made from.** A peg that drops into any plain hole as a stop. PETG, printed.

**How to make it.** Print six standing upright: a head 12 across and 24 tall, with a spigot 6.3 across and 12 long below it. For heavy use, print a 5.8 hole through the head and press in a 6 mm steel dowel instead of the printed spigot.

**How it fits the parts next to it.** The spigot drops into any 6.6 plain hole; the head is the stop.

**Check before moving on.** The spigot drops in by hand and rocks no more than about 0.3 at the top.

### 3.14 Instrument post foot

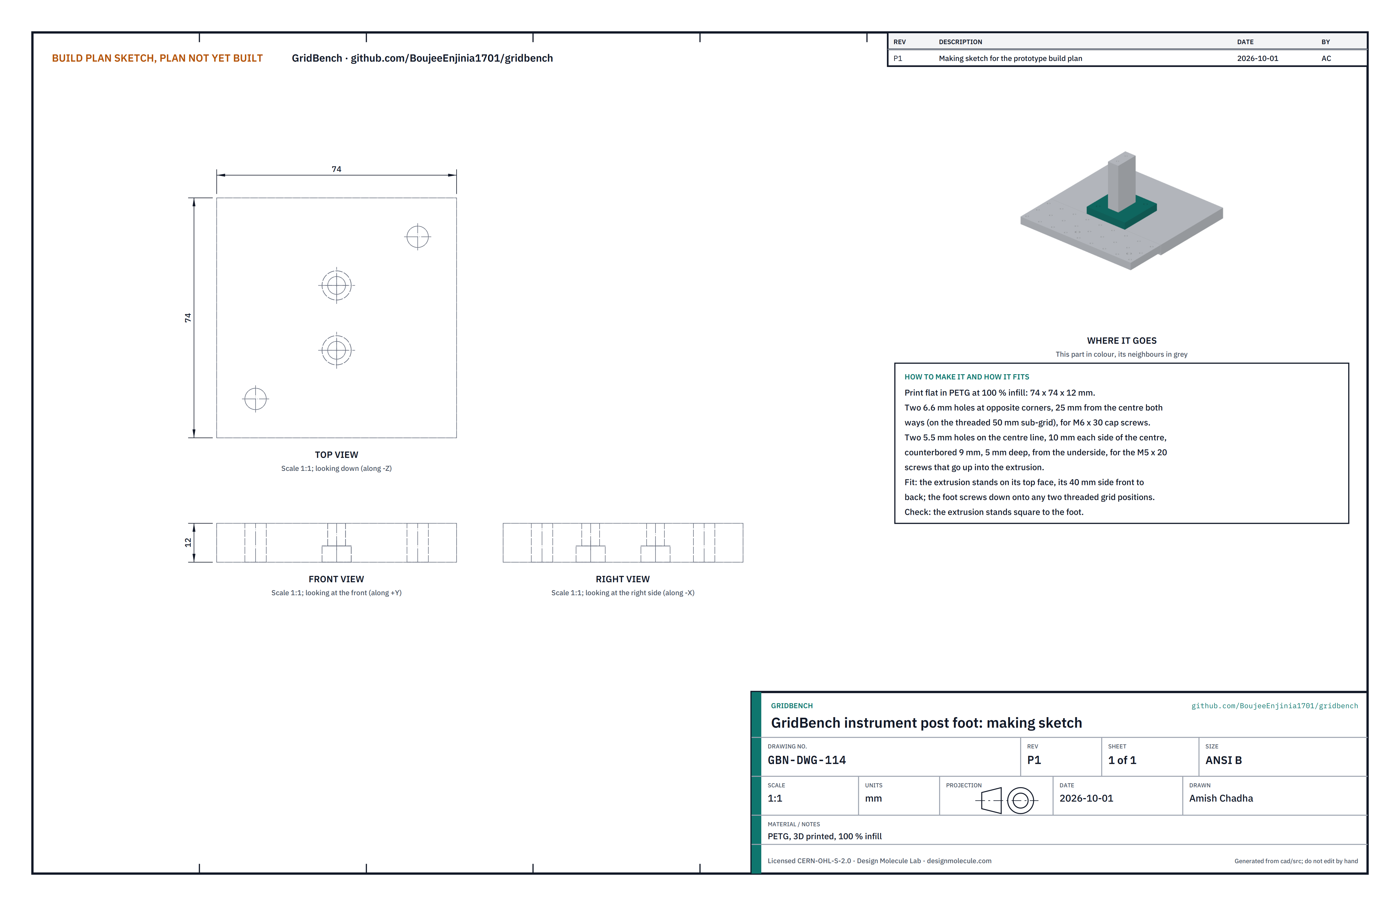
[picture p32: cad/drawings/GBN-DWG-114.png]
Figure 24. Making sketch of the post foot


*Figure 24. Post foot making sketch (GBN-DWG-114).*

**What it is and what it is made from.** The printed base that holds the instrument post upright on the grid. PETG at 100 % infill.

**How to make it.**

1. Print flat: 74 x 74 x 12.
2. Two 6.6 holes at opposite corners, 25 from the centre both ways, for the M6 x 30 screws.
3. Two 5.5 holes on the centre line, 10 each side of the centre, counterbored 9 across and 5 deep from the underside, for the M5 x 20 screws into the extrusion.
4. Cut the 20 x 40 aluminium extrusion to 350 and tap M5 into its two core holes at one end, 12 deep.

**How it fits the parts next to it.**

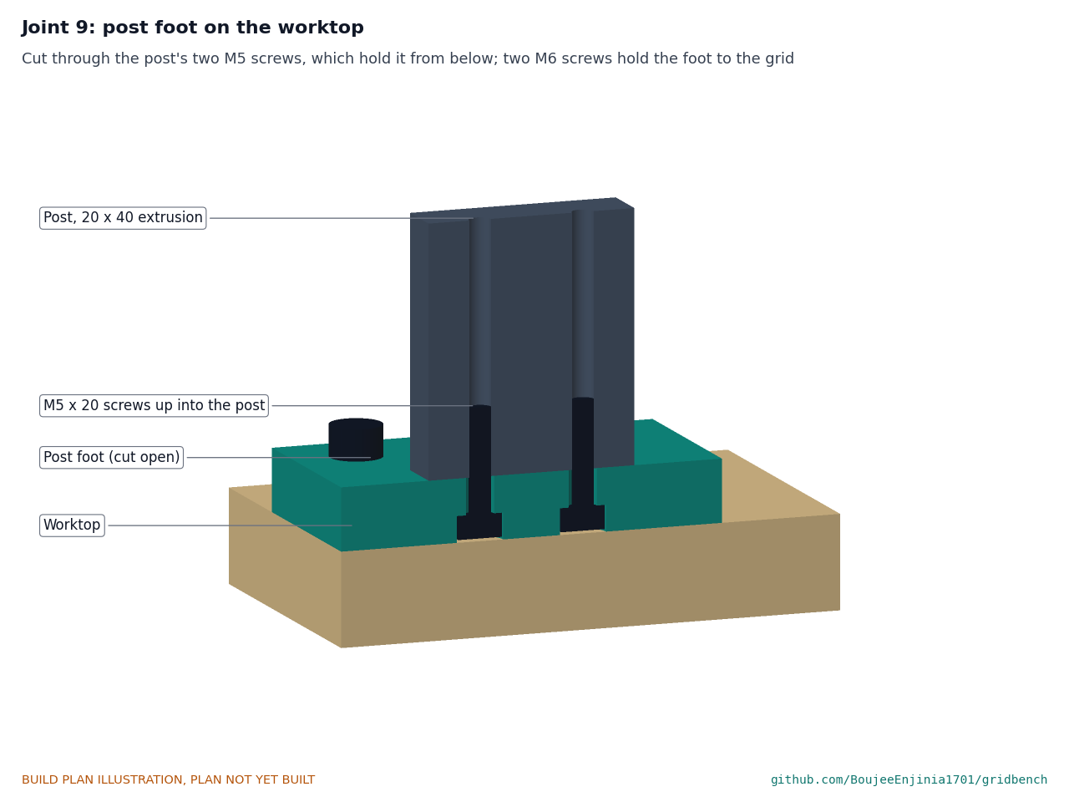
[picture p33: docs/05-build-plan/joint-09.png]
Figure 25. Joint 9: post foot on the worktop


*Figure 25. Cut through the post's two M5 screws, which hold it from below; two M6 screws hold the foot to the grid.*

The extrusion stands on the foot's top face with its 40 side running front to back. The foot screws down onto any two threaded positions diagonally 50 apart; the prototype puts it on the plywood directly behind the tile.

**Check before moving on.** The extrusion stands square to the foot.

### 3.15 Arm clamp and end clamp

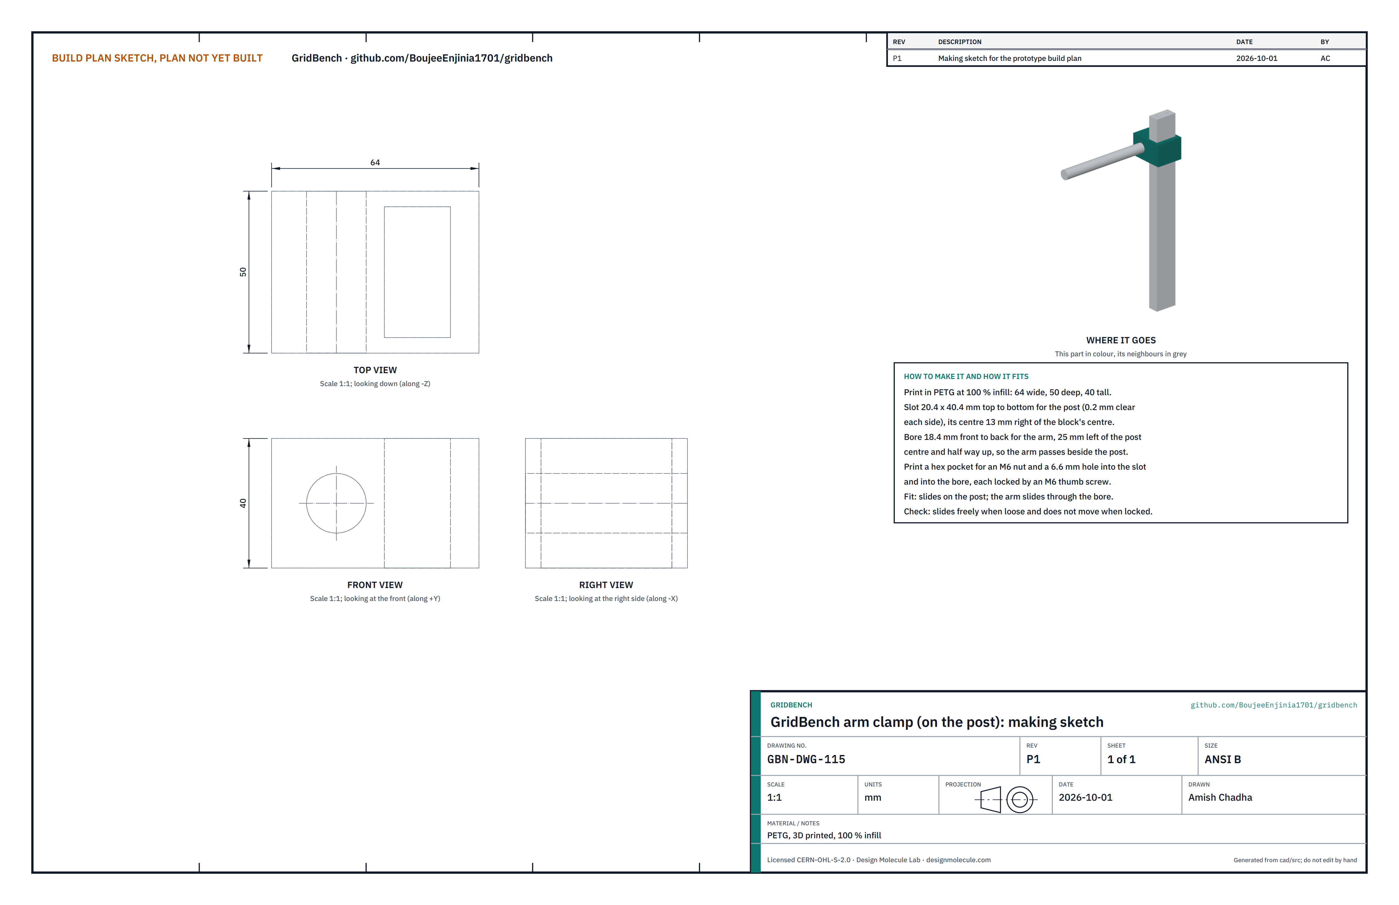
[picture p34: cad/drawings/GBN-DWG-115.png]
Figure 26. Making sketch of the arm clamp


*Figure 26. Arm clamp making sketch (GBN-DWG-115).*

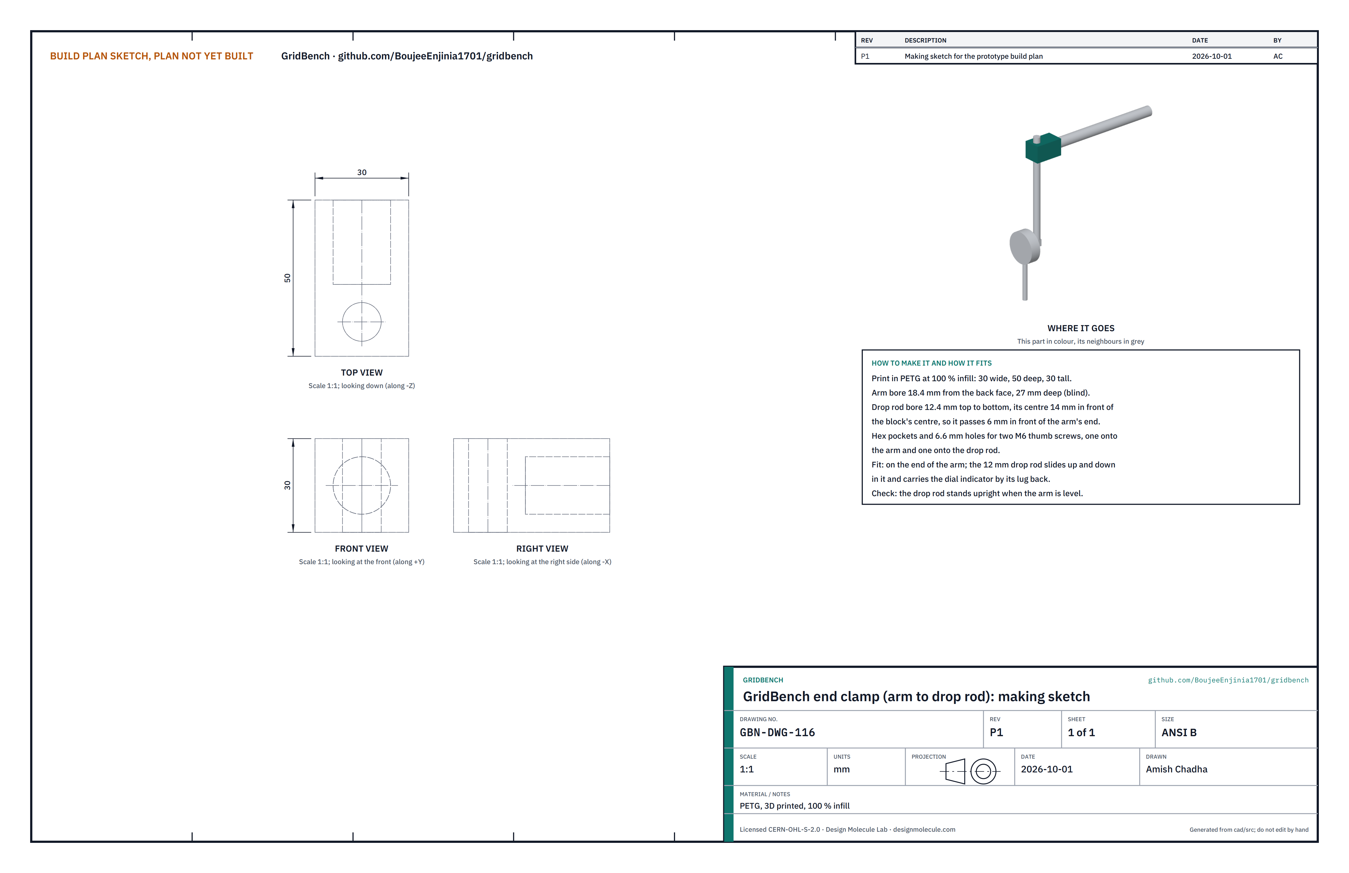
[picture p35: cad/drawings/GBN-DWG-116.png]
Figure 27. Making sketch of the end clamp


*Figure 27. End clamp making sketch (GBN-DWG-116).*

**What they are and what they are made from.** Two printed clamps that hold the arm on the post and the dial indicator's drop rod on the arm. PETG at 100 % infill.

**How to make them.**

1. Arm clamp: 64 wide, 50 deep, 40 tall. A slot 20.4 x 40.4 top to bottom for the post, its centre 13 right of the block's centre. A bore of 18.4 front to back for the arm, 25 left of the post's centre and half way up, so the arm passes beside the post.
2. End clamp: 30 wide, 50 deep, 30 tall. A blind bore of 18.4 from the back face, 27 deep, for the arm's end. A bore of 12.4 top to bottom for the drop rod, its centre 14 in front of the block's centre.
3. In each clamp, print a hex pocket for an M6 nut and a 6.6 hole into each bore or slot, for an M6 thumb screw.
4. Cut the 18 mm steel arm to 225 and the 12 mm steel drop rod to 200; deburr the ends.

**How they fit the parts next to them.**

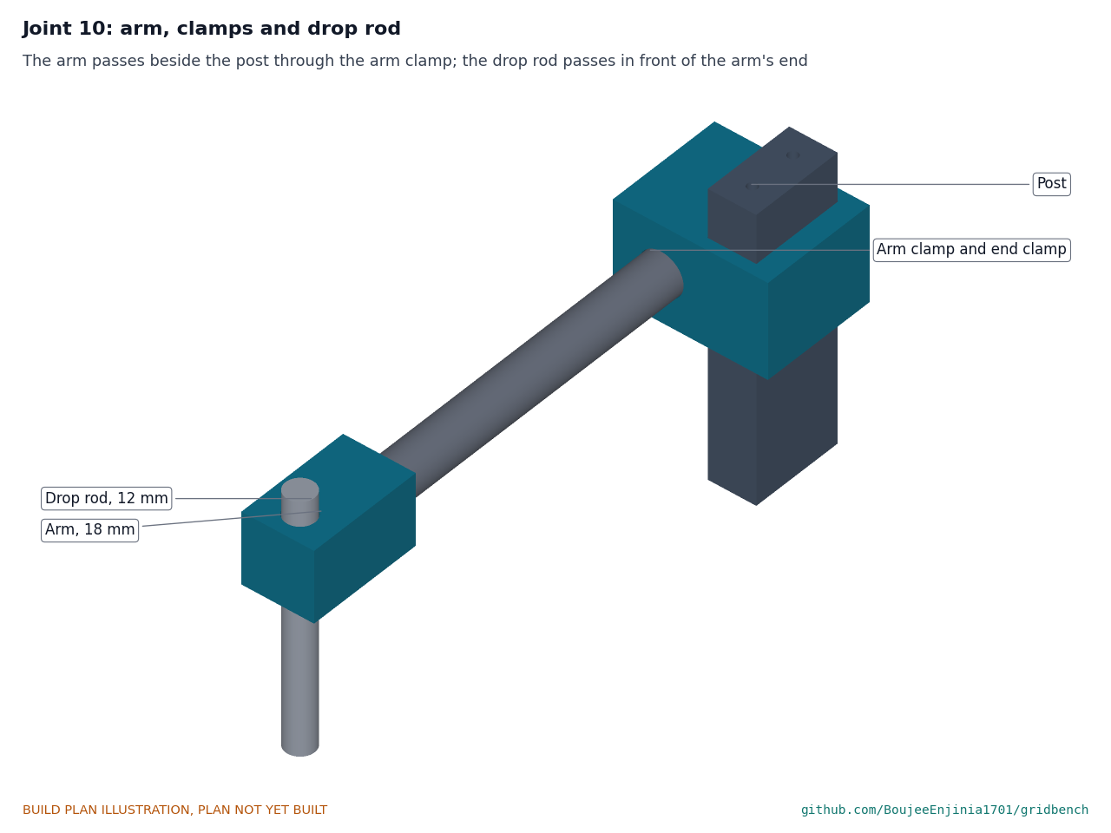
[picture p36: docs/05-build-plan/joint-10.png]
Figure 28. Joint 10: arm, clamps and drop rod


*Figure 28. The arm passes beside the post through the arm clamp; the drop rod passes 6 in front of the arm's end through the end clamp.*

The arm clamp slides on the post and locks at any height; the arm slides through it and locks. The end clamp sits on the arm's end; the drop rod slides up and down in it and carries the dial indicator by its lug back.

**Check before moving on.** Each clamp slides freely when loose and does not move when locked; the drop rod hangs upright when the arm is level.

### 3.16 Bought components

Buy to specification, not brand. Line numbers are those of the bill of materials.

- **Levelling feet (line 2).** Four M10 levelling feet with a 50 steel pad and 3 mm rubber base, and four M10 T-nuts for a 12 mm bore.
- **Frame fixings (line 1).** 24 M8 x 120 hex bolts with washers; 24 M8 cross dowels (barrel nuts) about 10 across and 20 to 30 long; 16 structural wood screws 6 x 100; wood glue for the packers.
- **Tee nuts and inserts (line 5).** 130 flanged M6 tee nuts with a 19 flange and 9.5 barrel for an 8.0 hole; 126 screw-in M6 inserts for wood, 10 outside, 13 long, for an 8.5 hole (122 in the worktop and 4 in the tile rails).
- **Worktop brackets (line 17).** Nine steel angle brackets 30 x 30 x 3, 20 wide, each with a 4 x 25 screw into the apron and a 4 x 16 screw up into the worktop.
- **Pins (lines 7 and 13).** Round 8 mm h6 hardened dowel pins 20 long, and diamond (relieved) 8 mm h6 locating pins 20 long. A precision fixture always uses one of each.
- **Post, arm and rod (line 10).** One 20 x 40 aluminium extrusion 350 long, one 18 mm steel bar 225 long, one 12 mm steel bar 200 long, four M6 thumb screws and nuts.
- **Dial indicator (line 11, user-supplied).** 0.01 resolution, 10 travel, 8 mm stem, lug back.
- **Fastener kit (line 12).** M6 cap screws: 10 x 30 (fixtures on the plywood), 4 x 80 (toe clamps, with printed knobs), 4 x 20 (tile), 10 x 16 (fixtures on the tile); 2 M5 x 20; washers; a 5 mm hex key; eight 4 x 30 countersunk wood screws for the shelf; one paint marker in a colour that stands out on birch plywood (red, for example) for the light-duty rings.
- **Ballast slabs (line 14).** Two concrete paving slabs 400 x 400 x 35, about 13 kg each.
- **Wall anchor angles (line 15, optional).** Two steel angles 50 x 50 x 4, 40 wide, with screws and wall plugs:

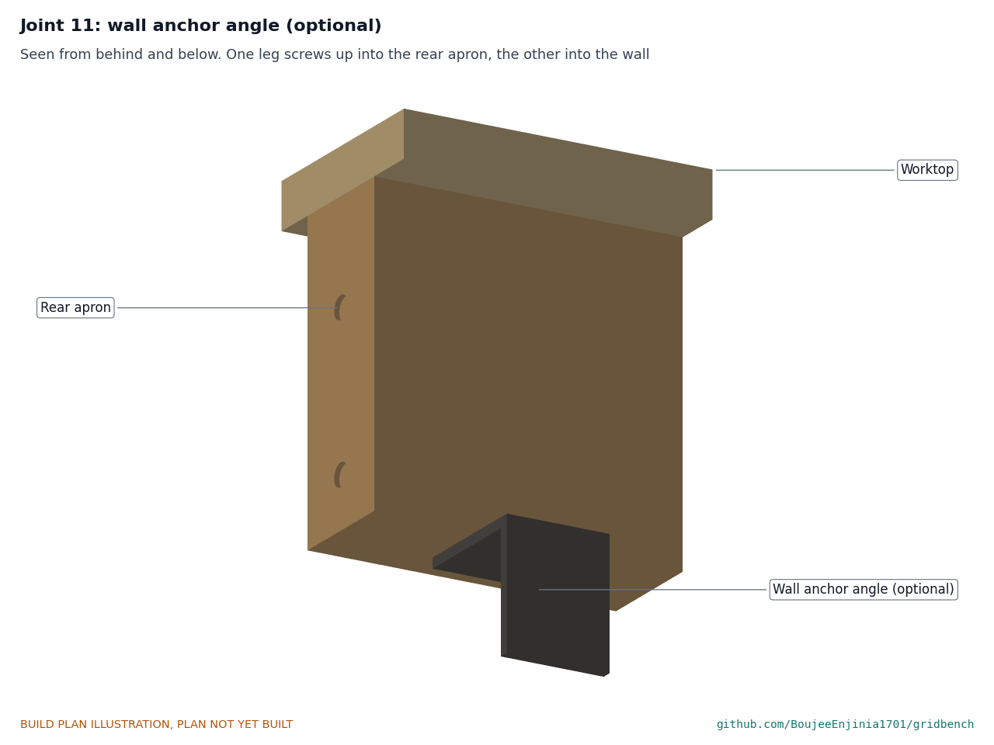
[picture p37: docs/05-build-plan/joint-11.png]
Figure 29. Joint 11: wall anchor angle


*Figure 29. One leg screws up into the rear apron; the other runs down the wall, flush with the worktop's back edge.*

- **Tile tools (line 16).** Two M6 spiral-point taps, 5.0 and 7.8 drills, an 8 mm H7 reamer and a tapping guide.

## 4. Putting it together

In each picture the parts already fitted are grey and the part being fitted is in colour, with an arrow showing the way it goes in.

### Step 1: T-nuts and feet into the legs

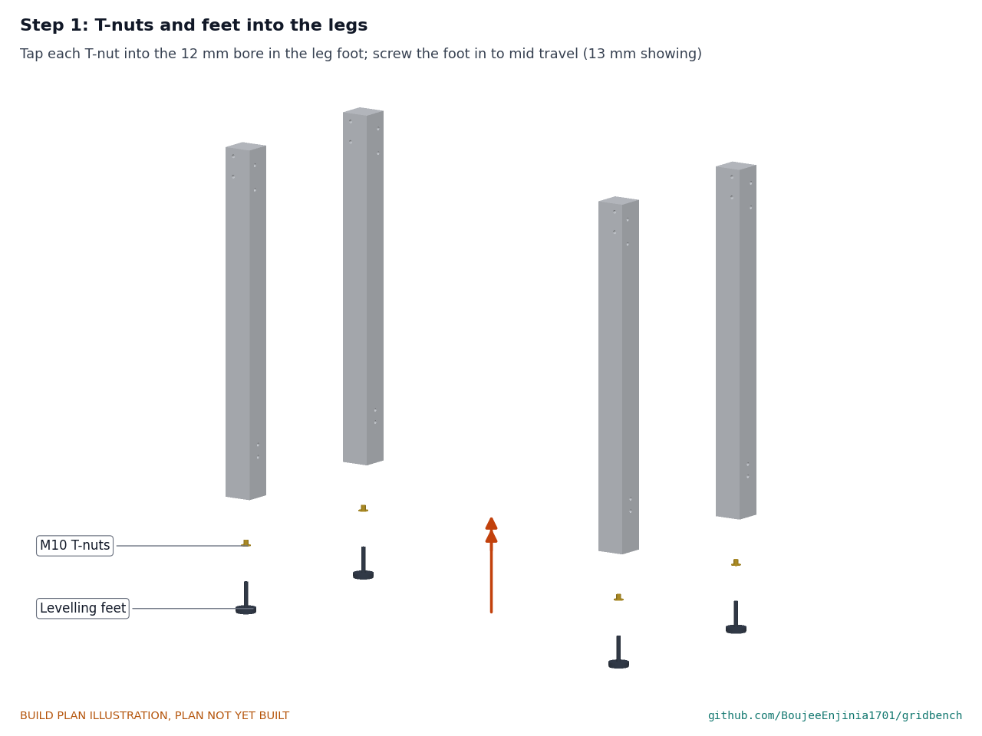
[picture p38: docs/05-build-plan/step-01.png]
Step 1


Tap each T-nut into the 12 mm bore in the foot of a leg until its flange is flat. Screw a levelling foot into each until 13 of thread shows.

### Step 2: end aprons between the legs

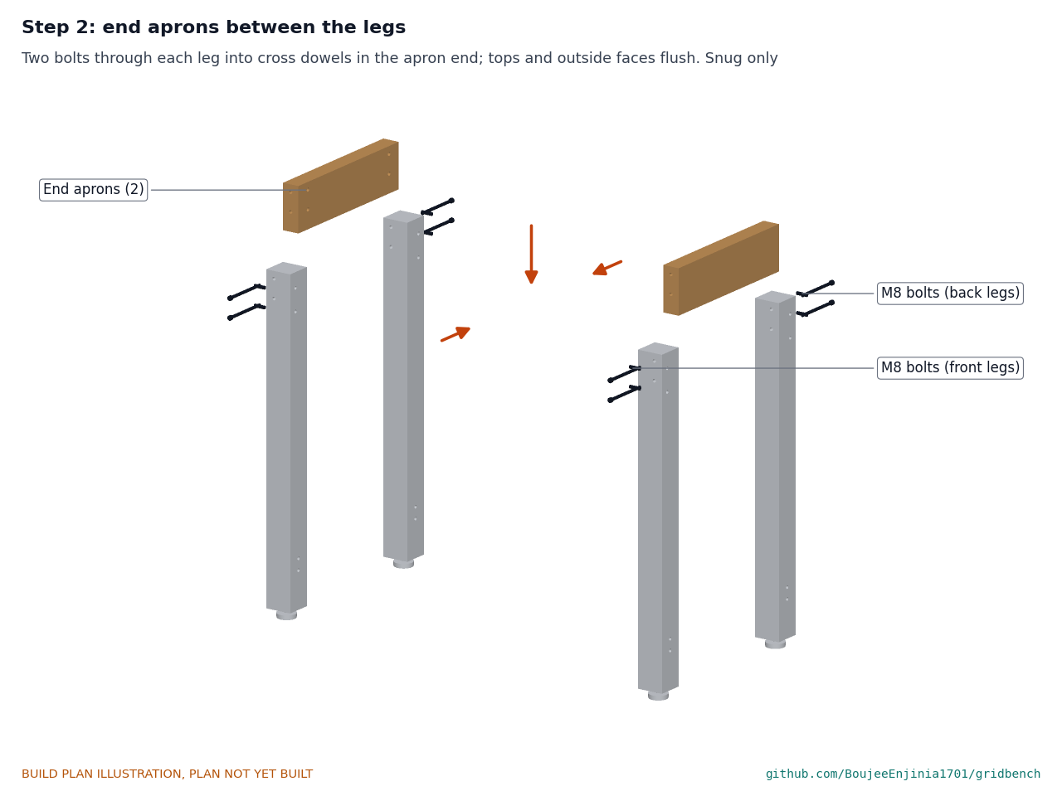
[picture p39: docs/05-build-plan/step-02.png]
Step 2


Lay two legs on the bench with their side faces up and an end apron between them, tops and outside faces flush. Push the cross dowels into the apron, slot toward the bolt, and fit two bolts with washers through each leg. Snug only. Make both end frames.

### Step 3: long aprons join the two end frames

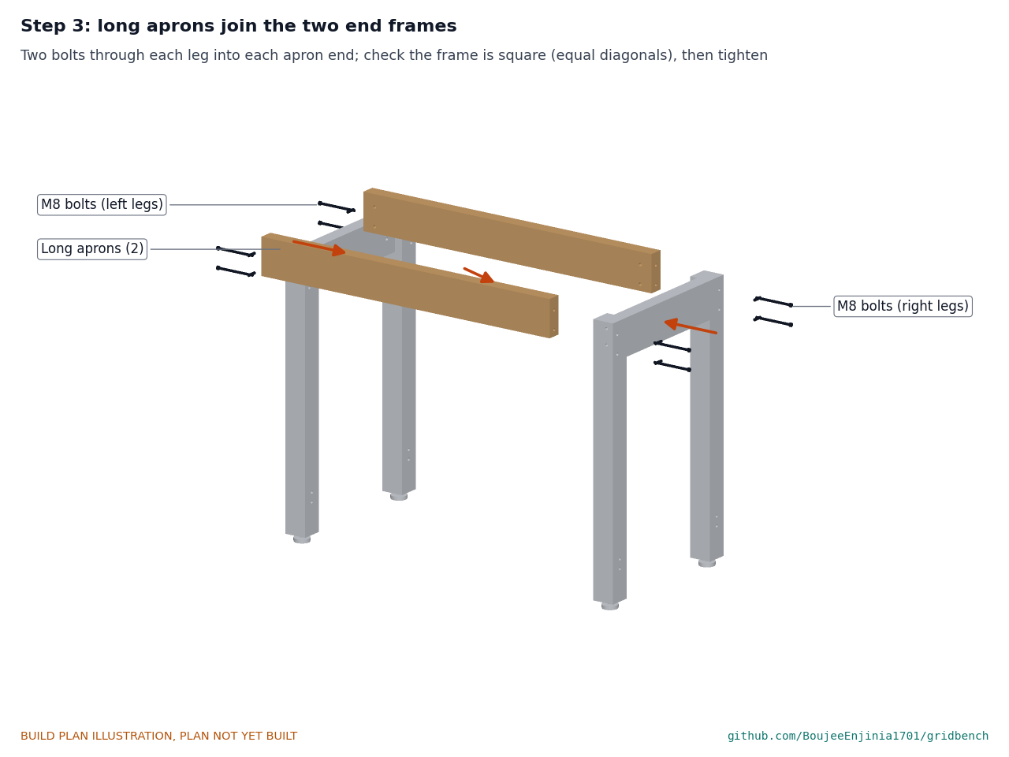
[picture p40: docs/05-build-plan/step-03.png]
Step 3


With a helper holding the end frames upright, bolt the long aprons between them the same way. Measure both diagonals across the top of the frame; when they are equal within 2, tighten every bolt firmly.

### Step 4: low rails between the legs

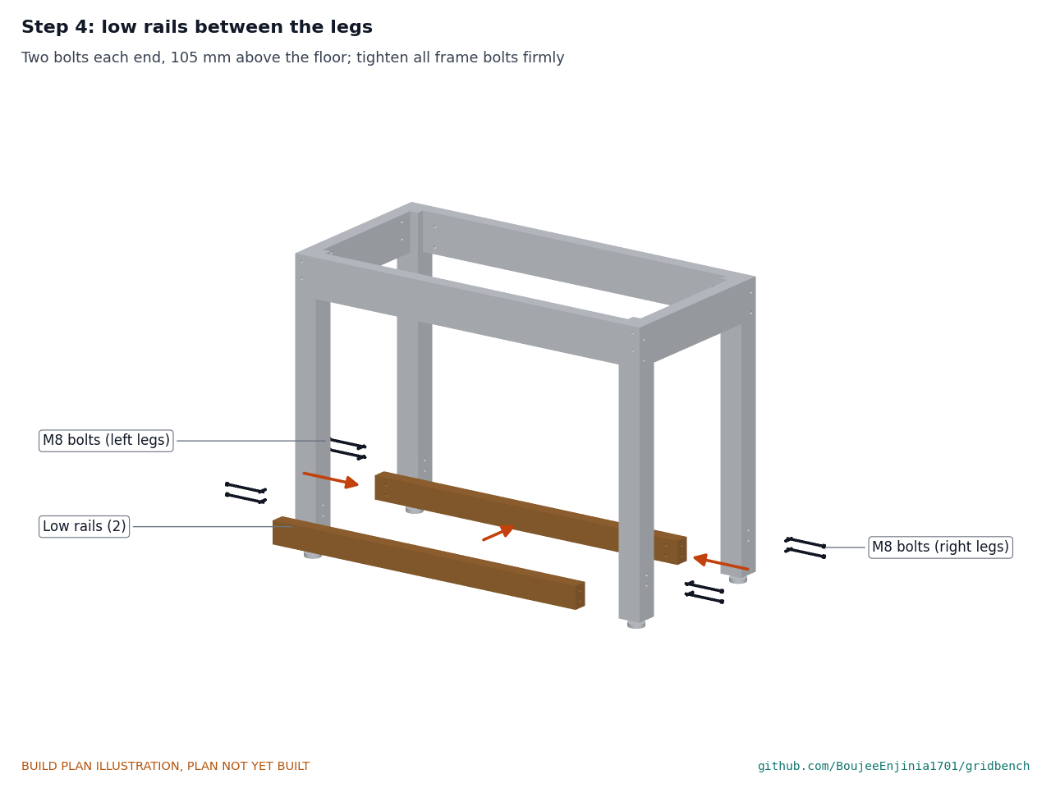
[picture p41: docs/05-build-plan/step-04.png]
Step 4


Bolt the low rails between the legs, their lower edges 105 above the floor. Tighten every frame bolt firmly. Keep the rails' top faces clear: the shelf is screwed down into them in step 7.

### Step 5: cross rails between the long aprons

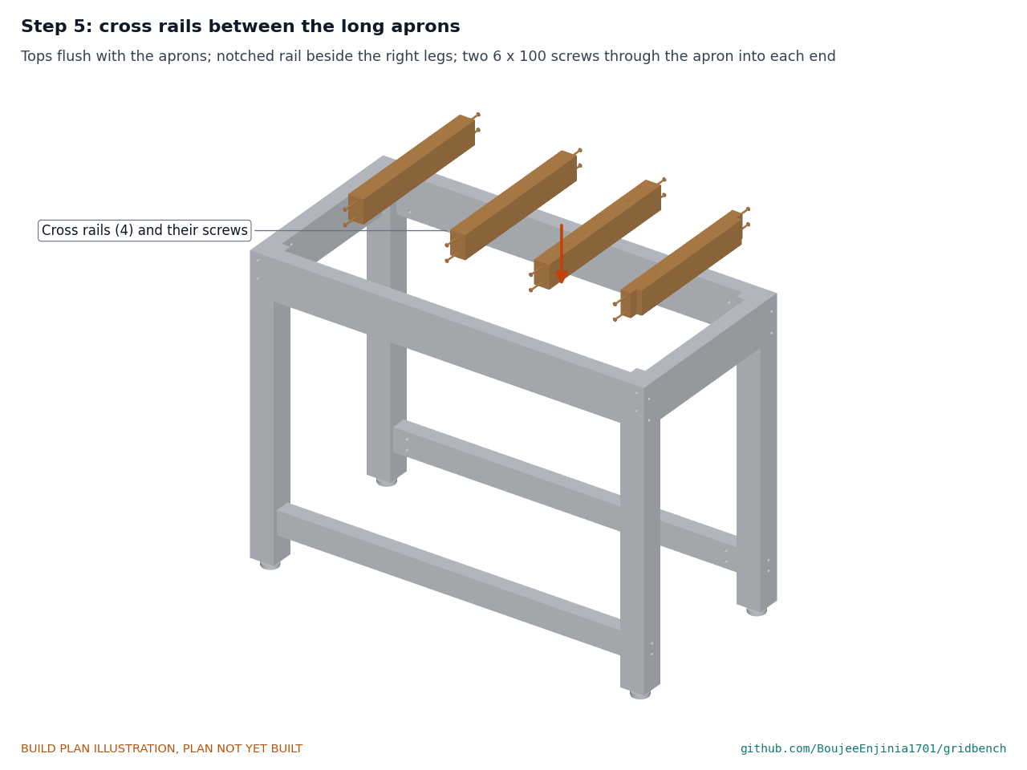
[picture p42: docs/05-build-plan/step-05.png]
Step 5


Fit each rail with its top flush with the aprons, the notched one beside the right-hand legs, and drive two 6 x 100 screws through the apron's pilot holes into each end.

### Step 6: packers onto the two tile rails

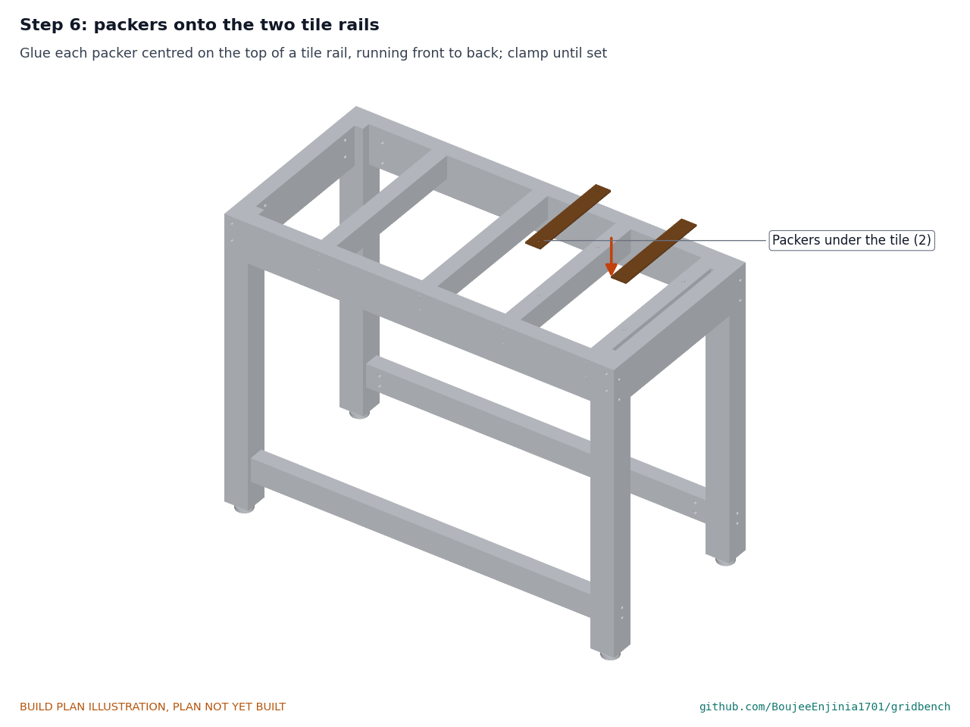
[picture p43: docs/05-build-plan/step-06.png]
Step 6


Glue each packer centred on the top of a tile rail, running front to back, and clamp it until the glue sets. Wipe off any glue that squeezes out.

### Step 7: shelf onto the low rails

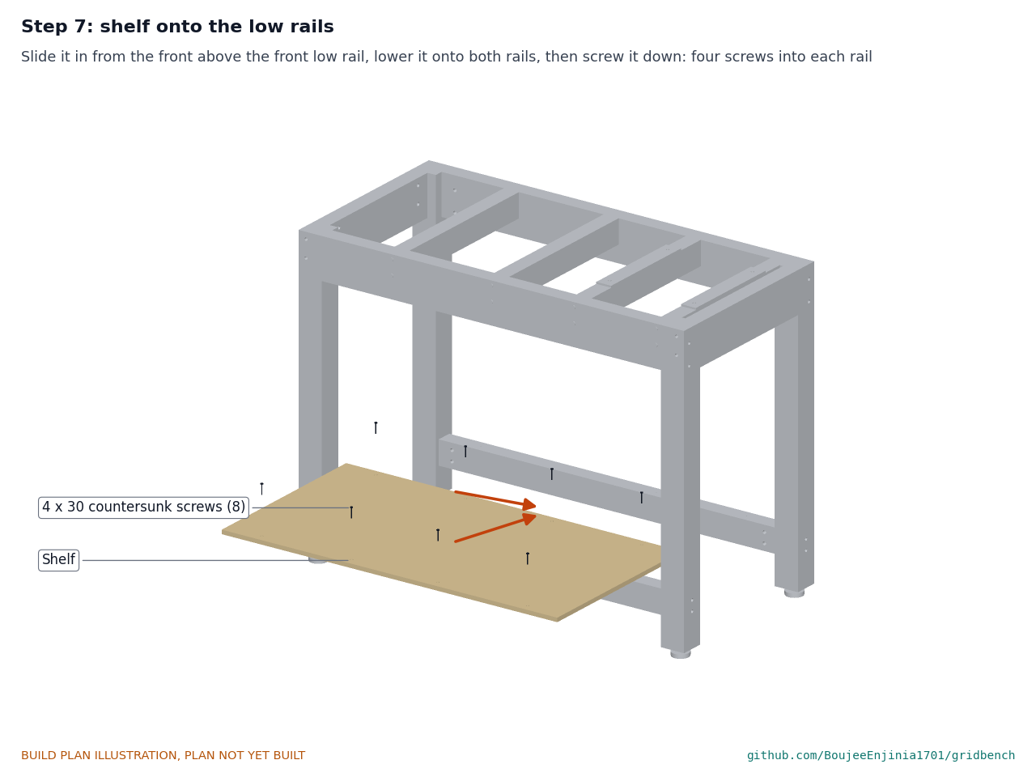
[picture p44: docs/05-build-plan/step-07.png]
Step 7


Slide the shelf in from the front, above the front low rail, and lower it onto both rails. Through each of its eight holes, drill a 3 mm pilot hole 20 deep into the rail, then drive a 4 x 30 countersunk wood screw until its head is flush. **Hold point:** the shelf does not move when pushed along the bench.

### Step 8: threaded inserts into the worktop

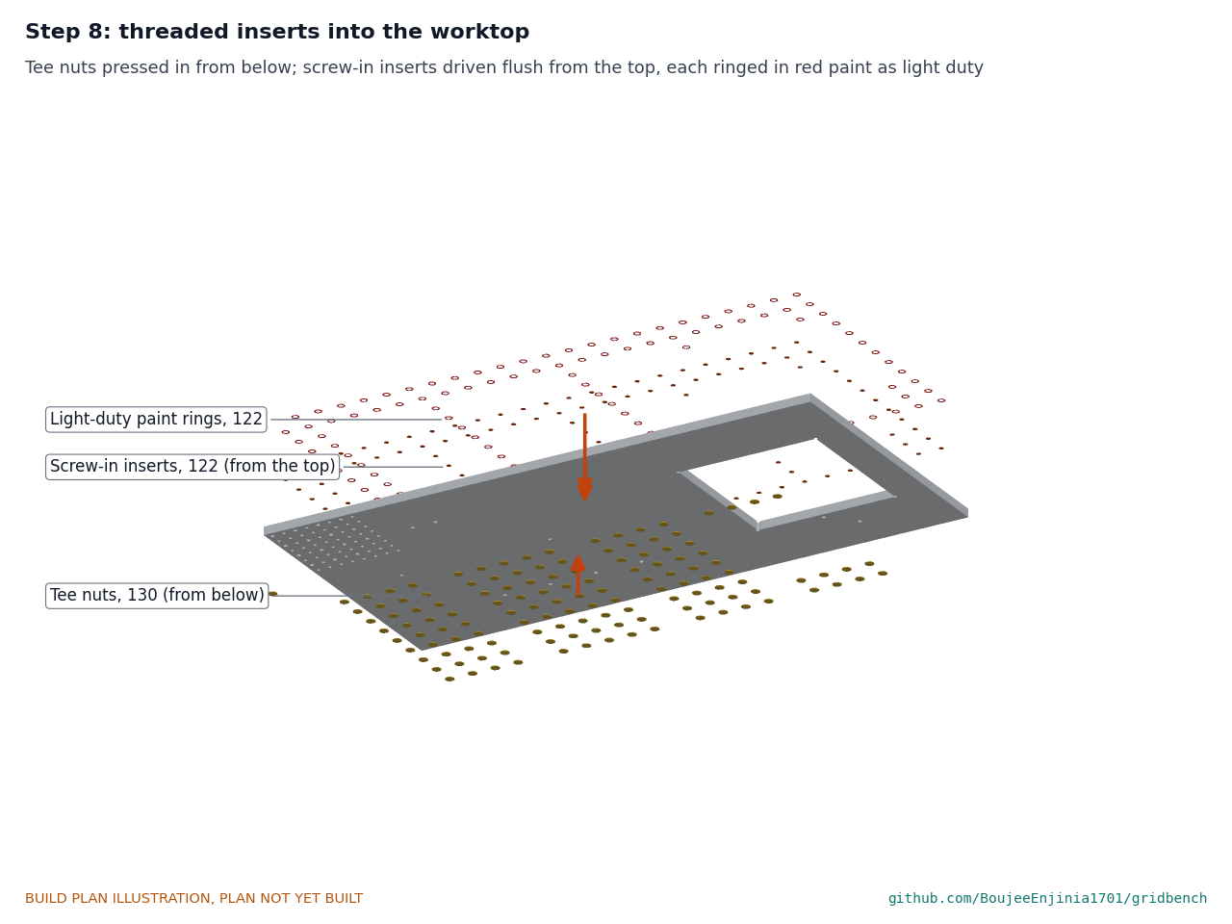
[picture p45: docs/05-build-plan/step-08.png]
Step 8


With the worktop upside down on a clean bench, press each tee nut into its 8.0 hole from the underside with a vice or a bolt and washer, until the flange is flat; do not hammer the prongs into the ply. Turn it over and drive each screw-in insert flush into its 8.5 hole from the top with a hex key, square to the face. **Hold point:** an M6 screw runs into every threaded position by hand.

### Step 9: worktop onto the frame

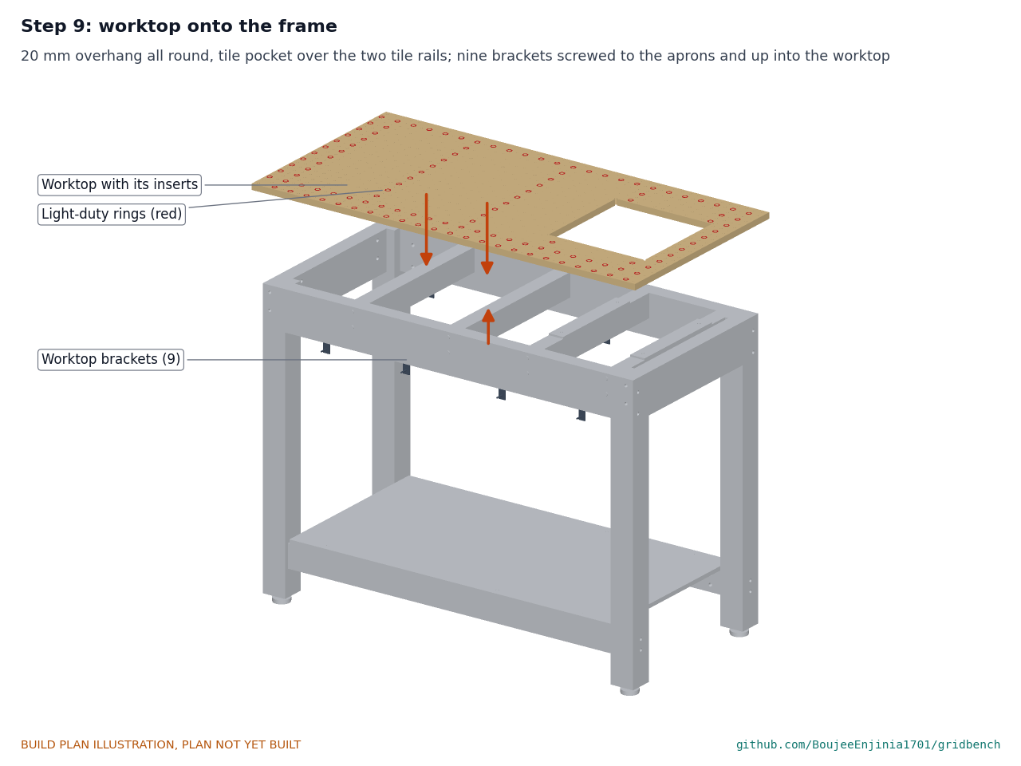
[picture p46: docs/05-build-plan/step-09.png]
Step 9


With a helper, lay the worktop on the frame with 20 overhang all round and its tile pocket over the two tile rails. Screw the nine brackets to the aprons and up into the worktop, each midway between two threaded positions.

### Step 10: precision tile into its pocket

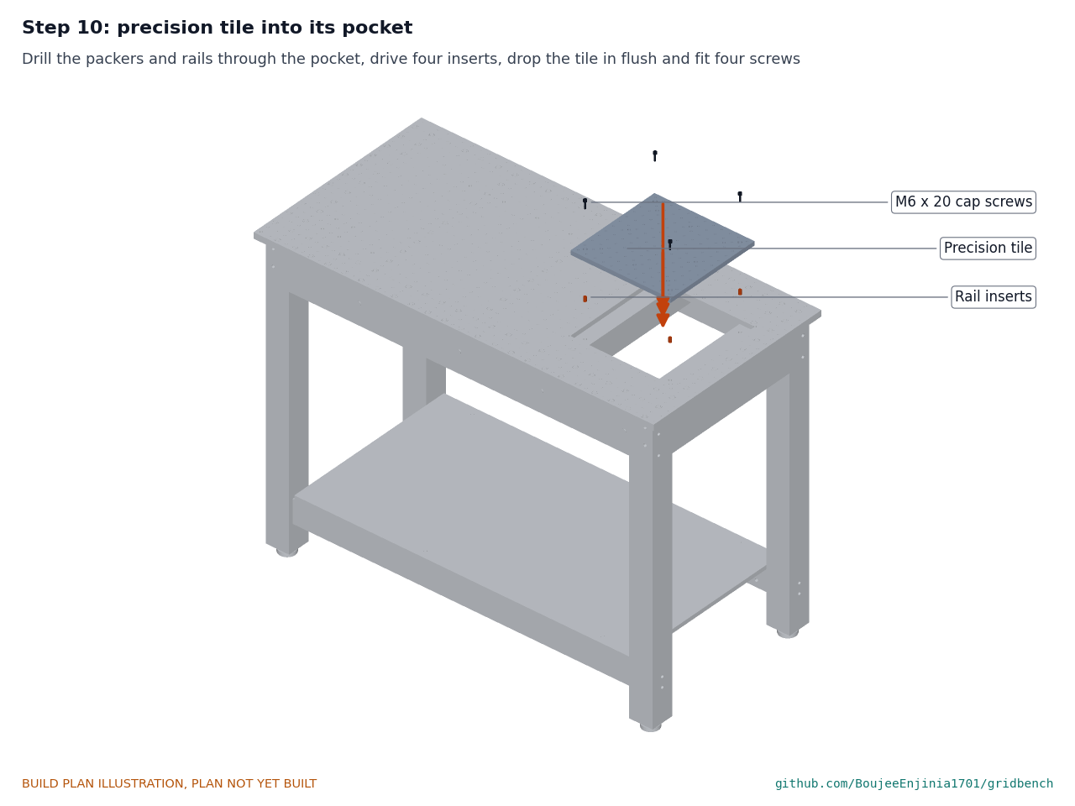
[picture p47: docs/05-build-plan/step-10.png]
Step 10


Through the pocket, mark the four fixing hole centres on the packers, drill 8.5 and 15 deep through each packer into the rail, and drive a screw-in insert flush with the packer's top. Lower the tile in, top face up and marked edge to the front, and fit four M6 x 20 cap screws, tightening them evenly. **Hold point:** a straightedge across the tile and the plywood shows no step over 0.1.

### Step 11: ballast slabs onto the shelf

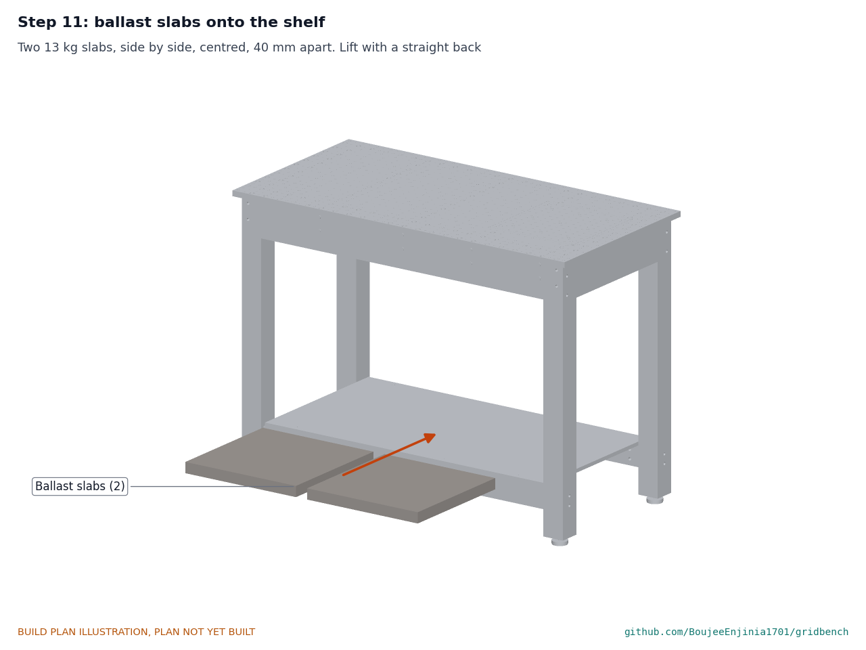
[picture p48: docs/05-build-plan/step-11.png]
Step 11


Lift each slab onto the shelf with a straight back and set them side by side, centred, 40 apart. **Hold point:** safety stop S4.

### Step 12: fence, stop pins and V-block

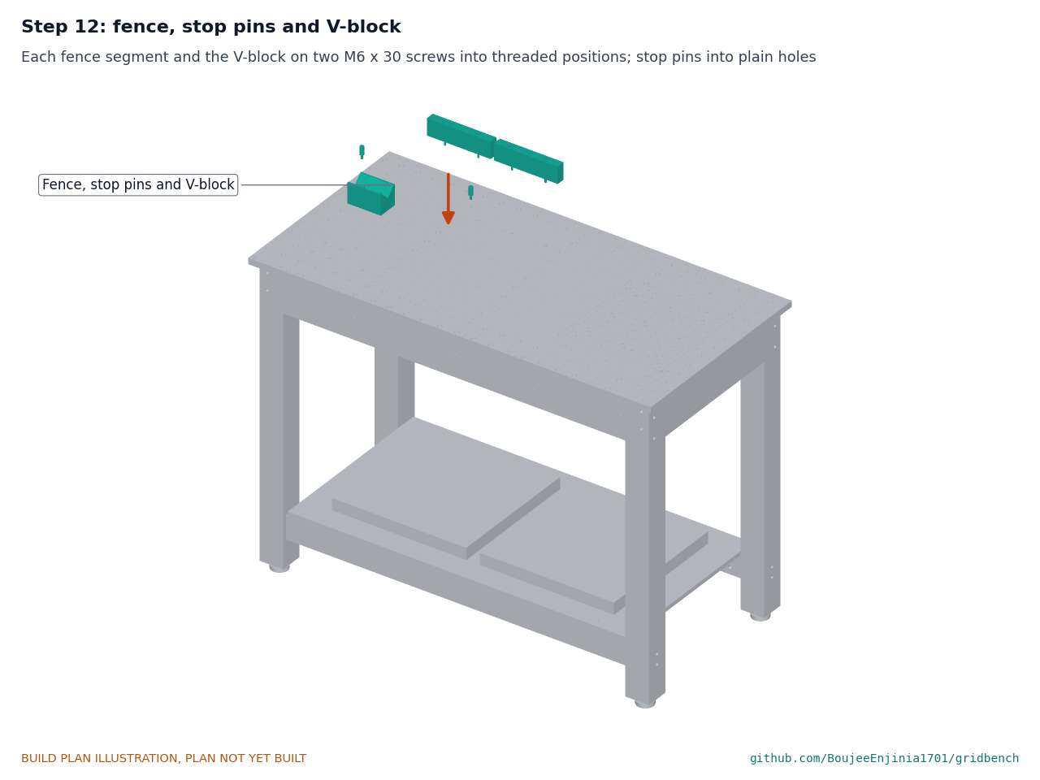
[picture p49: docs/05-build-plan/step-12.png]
Step 12


Screw each fence segment and the V-block down with two M6 x 30 cap screws into threaded positions; drop the stop pins into plain holes where they are needed.

### Step 13: pins, work and toe clamps on the tile

Step 13

Put a round pin in one dowel bore and a diamond pin in another. Set the work against them, then fit each toe clamp on an M6 x 80 screw into a tile hole and tighten to 1.6 N·m at most.

### Step 14: instrument post, arm and dial indicator

Step 14

Screw the post foot down with two M6 x 30 screws. Slide the arm clamp onto the post and the arm through it, fit the end clamp on the arm's end, hang the indicator from the drop rod by its lug back, and lower the drop rod until the indicator's point rests on the work with about 1 of travel used. Lock every thumb screw.

### Step 15: wall anchor angles (optional)

Step 15

Push the bench against the wall. Screw each angle up into the rear apron and, through wall plugs, into the wall.

## 5. First checks

These are the checks a TRL 4 test report would record; this plan only lists them. Requirement numbers are those of GBN-REQ-001.

*Table 2. First checks.*

| Check | Requirement | How | Pass when |
| --- | --- | --- | --- |
| Grid fits a commercial accessory | R1 | Screw a metric optical breadboard post into threaded positions on the plywood and the tile | It seats square in every position tried |
| Height and level | R2 | Tape measure at each corner; spirit level both ways; adjust the feet | Top at 900, give or take 15; level |
| Hole position on the plywood | R3 | Steel rule and pin gauges between holes 1,000 apart, at two humidities | Within 0.3 (CNC-drilled) or 0.5 (template-drilled) |
| Tile hole position and relocation | R4 | Dial indicator on a part located by one round and one diamond pin, relocated 10 times | Returns within 0.03 |
| Flatness | R5 | Straightedge and feeler gauges | Tile within 0.05 over 300; worktop within 0.5 over 1,000 |
| Stiffness | R6 | 500 N (about 51 kg) at the middle of a bay; dial indicator under the worktop | Deflection 0.5 or less |
| Clamp hold-down | R7 | Spring scale pull on a clamped part at 1.6 N·m, at a tee nut position and on the tile; again after 8 h | Holds 500 N with no visible creep |
| Fixture change | R8 | Swap the V-block for a fence segment with one 5 mm hex key, timed | 60 s or less |
| Buildability | R9 | Review of this build | Hand and garage tools and a 200 x 200 printer were enough |
| Stability | R12 | Push gauge at the front top edge, with the ballast in place; feel every edge | No tipping at 150 N; every exposed edge rounded or chamfered 0.5 or more |

## 6. Safety stops

Stop at each point. Carry on only when everything listed is true.

- **S1. Before any cutting or drilling.** Safety glasses on; the work clamped, never hand held; long hair and sleeves tied back; no gloves near a turning drill or router.
- **S2. Before drilling and tapping the tile.** The tile clamped in a drill press vice or to the table; cutting fluid ready; the tap held square in its guide. Clear aluminium chips with a brush, not fingers.
- **S3. Before standing the frame up.** Every frame bolt tight; a helper to steady it. Lift the worktop with two people.
- **S4. Before any use of the bench.** Both ballast slabs on the shelf, or the wall anchor fitted. The bench does not rock on its feet.
- **S5. Before clamping.** Every toe clamp marked 1.6 N·m and a torque screwdriver to hand. Full clamping force only at tee nut positions and on the tile; the screw-in positions over the frame can pull out first, so they are rated light duty at 0.92 N·m and marked on the worktop in a contrasting colour (decided by Amish, 2026-10-02).
- **S6. Always.** No welding, grinding sparks or hot work on the bench.

## 7. Tools, skills and workspace

**Tools.** Mitre or circular saw and a handsaw; jigsaw; router with a straight bit and a straightedge guide; drill press or a drill in a stand; drills 4, 5.0, 5.5, 6.6, 7.0, 7.8, 8.0, 8.5, 9, 10 and 12; 11 mm counterbore; 8 mm H7 reamer; M5 and M6 taps and a tapping guide; hand plane; shared CNC router or a printed drilling template; FDM printer with a bed of at least 200 x 200 that prints PETG; 13 mm spanner and socket; 5 mm hex key; torque screwdriver covering 0.5 to 2 N·m; tape measure, steel rule, engineer's square, straightedge and feeler gauges; spirit level; clamps.

**Skills.** No certified trade is needed. Basic woodwork (measuring, sawing square, drilling straight), routing to a line, drilling and tapping aluminium, and 3D printing. Nothing is powered: the bench has no electrical parts.

**Workspace.** A floor space about 2.5 x 2 m to build the frame; a bench for drilling; a ventilated place for the printer.

**Personal protective equipment.** Safety glasses for every cutting, drilling, routing and tapping step; hearing protection for sawing and routing; a dust mask when routing plywood; safety boots when moving the slabs.

## 8. Where the numbers come from

- Model and constructability checks: `cad/src/model.py` (`python cad/src/model.py --check`); STEP and STL exports in `cad/step/` and `cad/stl/`.
- Pictures: `cad/src/build_plan_media.py`, using `.kit/build_views.py`; written to `docs/05-build-plan/` and `cad/drawings/GBN-DWG-101` to `GBN-DWG-116`.
- General arrangement: `cad/drawings/GBN-DWG-001.pdf`, Rev P5.
- Calculations: `docs/04-calcs/01-sizing.md` (GBN-CAL-001 v0.4) and `docs/04-calcs/sizing.py`; mass [B1], tipping [C2], [C4], stiffness [D5], clamps and inserts [G4], [G5c], fixture change [H1], cost [K3].
- Bill of materials: `bom/bom.csv`.
- Decisions: `docs/decisions/0003-design-for-construction.md` (GBN-DDR-003), with GBN-DDR-001 and GBN-DDR-002; open items in `docs/06-design-decisions.md` (GBN-DEC-001).
- Requirements: `docs/03-requirements.md` (GBN-REQ-001 v0.7).

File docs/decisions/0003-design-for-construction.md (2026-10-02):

---
doc_id: GBN-DDR-003
title: GridBench design for construction
project: GridBench
doc_type: Design decision record
version: "0.2"
status: Draft
date: '2026-10-02'
author: Amish Chadha
license: CERN-OHL-S-2.0
revisions:
- version: "0.1"
  date: '2026-10-01'
  author: Amish Chadha
  change: Changes that make the concept physically buildable, with the reason for each; made under Amish's 2026-09-30 instruction to make the design physically buildable; open for his review
- version: "0.2"
  date: '2026-10-02'
  author: Amish Chadha
  change: 'Accepted by Amish on 2026-10-02 as recorded; record stays Draft'
---

# 0003: Design for construction

- **Date:** 2026-10-01
- **Status:** accepted. Made under Amish's 2026-09-30 instruction to make the design physically buildable. Amish, 2026-10-02: "i approve your recommendations for all 555 open decisions." This covers every change in Tables 1 and 2, accepted as recorded, and is recorded in the design decisions register (GBN-DEC-001). Nothing here changes what the bench does, its pitch or its safety case. The record stays Draft.

## Context

On 2026-09-30 Amish approved the illustrated build plan format and wrote: "If you are realising that the design cannot be built as per concept - fix the design assumptions to match and be physically feasible as you draw the illustrations." The TRL 3 model of GBN-DDR-002 showed what GridBench does and carried the right sizes, but several parts could not be made, fixed or assembled as drawn. Checking the model with build123d (solid intersections, distances and grid positions) found the problems below.

The changes keep what the bench does: the same 1,200 x 600 mm worktop at 900 mm, the same 25 mm grid with 1,152 positions, the same 130 tee nuts and 122 screw-in inserts, the same precision tile, pins, clamps, fence, stops, V-block, instrument post, ballast and feet. Every change is in `cad/src/model.py`, which now also runs 92 constructability checks (`python cad/src/model.py --check`): parts that must touch do touch, and parts that must not touch are apart by at least the stated clearance. All 92 pass.

## Options considered

For each problem the simplest physically sound fix that a garage workshop can make was chosen. Where a fix had a cheaper alternative that would change how the bench is used (for example gluing the frame instead of bolting it), the alternative is noted in the Why column and left for value engineering.

## Decision

*Table 1. Changes made to the model, the BOM and the calculations.*

| # | Problem in the concept | Change made | Why this way |
| --- | --- | --- | --- |
| P1 | The long aprons ran the full 1,160 mm through the legs: 1.5 litres of each apron overlapped the four legs. Nothing joined any frame member to a leg. | Long aprons cut to 1,020 mm and butted between the legs, flush with their tops and outside faces. Every apron and low rail end is held by two M8 x 120 bolts through the leg into M8 cross dowels (barrel nuts) set 40 mm in from the member's end. The end-apron bolts (50 and 100 mm up from the apron's lower edge) are staggered against the long-apron bolts (20 and 80 mm up) so the two pairs miss each other inside the leg. | A bolt and cross dowel joint is the usual knock-down bench joint: square ends, straight holes, no housing to cut, and it can be taken apart to move the bench. It keeps the BOM's bolted timber frame. Gluing instead would be cheaper but permanent. |
| P2 | The cross rail at 502.5 mm (under the tile's right edge) passed 15 mm into the two right-hand legs. | That rail is notched 15 x 25 mm at both ends, full height, on the side toward the legs. | Keeps the rail under the tile's right edge and the four tile fixing screws where they were; one saw cut each end. |
| P3 | The cross rails had no fixing. | Two 6 x 100 mm structural screws through the apron into each rail end. | Simple, strong enough for 250 N per rail [D3], and the screw heads are hidden under the worktop overhang. |
| P4 | The shelf was exactly as long as the gap between the legs (1,020 mm), so it could not be put in. | Shelf 1,010 mm long, 5 mm clear of the legs at each end; it slides in from the front above the front low rail and drops onto both rails. | It now fits and still bears 45 mm on each low rail. |
| P5 | The tile filled its pocket with no clearance and square corners, while a routed pocket has round corners. | Pocket 301 x 301 mm (0.5 mm clear all round) with an 8 mm relief hole on each corner. | The tile drops in by hand and seats on its packers. The tile still sits on the grid to within the 0.5 mm clearance, which is inside R3's field tolerance; the tile's own holes carry the precise work. |
| P6 | The tile's four counterbored fixing holes had nothing to screw into: no thread in the rails or packers. | Four M6 screw-in inserts driven into the two tile rails through the packers, and four M6 x 20 cap screws in the counterbores. | Reuses the insert already in the BOM; a cap screw head (10 mm) sits below the surface in the 11 mm by 6.5 mm counterbore. |
| P7 | Nothing held the worktop to the frame. | Nine steel angle brackets, 30 x 30 x 3 mm and 20 mm wide, on the inside faces of the long aprons (four each) and the left end apron (one), each with one screw into the apron and one up into the worktop. Each sits midway between two threaded positions, 5.5 mm clear of the nearest tee nut flange. | Screws through the top would block grid holes. The brackets miss every tee nut and cross rail (checked). The right end has no bracket because the cross rail beside it leaves no room; the end apron and legs still carry it. |
| P8 | The levelling feet's stems floated 1 mm into the solid leg. | Each leg end bored 12 mm, 60 mm deep, with an M10 T-nut tapped in; the foot screws through it. | This is how the BOM's "M10 T-nut in the leg" works; the T-nut flange bears on the leg end. |
| P9 | The fence segments, V-block, instrument post foot and one toe clamp sat on unthreaded holes or between holes, so they could not be screwed down; the toe clamp screws missed the tile holes. | Every fixture moved to threaded positions: fence segments centred 287.5 and 87.5 mm left of centre on the 50 mm sub-grid, 10 mm apart, each with two counterbored M6 x 30 screws; V-block on two M6 x 30 screws; post foot (now 74 x 74 mm) on two M6 x 30 screws; toe clamp screws on tile holes (as the appearance model already had them). Stop pins got a 6.3 mm spigot into a plain hole. A screw-length rule follows: on the plywood a screw reaches 15 to 18 mm below the surface (it then engages a tee nut or a screw-in insert fully); on the tile, no more than 12 mm. | These are example placements of the fixture set; each fixture still does what it did. The counterbores leave a 12 mm floor so one screw length (M6 x 30) serves all plywood fixtures. |
| P10 | The instrument arm ran from the centre of the post, through the post, and the drop rod met the arm end with no clamp. | A printed arm clamp (64 x 50 x 40 mm) slides on the post with the 18 mm arm passing 25 mm beside it; a printed end clamp on the arm's end holds the 12 mm drop rod 6 mm in front of the arm's end. Two M5 x 20 screws hold the post to its foot from below. The post moves to the plywood directly behind the tile, and the arm reaches straight forward over the work. | Each part now passes beside the next instead of through it; the clamps lock with M6 thumb screws, as the BOM's "printed clamps" intended. |
| P11 | The V-block's V was wider than the block, so its top edges vanished and it stood 55 mm tall, not 60 mm. | V 50 mm wide at the top with a 5 mm flat each side, its bottom 35 mm above the base. | Keeps the stated 100 x 60 x 60 mm block and gives printable flats. |
| P12 | The optional wall anchor angles had one leg flat under the worktop overhang, pointing back, where it could not reach a wall. | Each angle's flat leg screws up under the rear apron and its other leg runs down the wall, flush with the worktop's back edge. | A bench pushed against a wall can then be fixed to it; the tie force is still only 35 N [C6]. |

*Table 2. Knock-on changes.*

| Item | Change | Reason |
| --- | --- | --- |
| Mass | Bench 43.8 kg empty (was 41.9 kg), 69.5 kg with the ballast [B1], [B2]. The frame timber is lighter (the overlapping apron length is gone) and 2.6 kg of bolts, cross dowels, screws and brackets is added. | Parts added for construction. |
| Stability | Tipping force 117 N empty (was 112 N) and 186 N with the ballast (was 181 N) [C2], [C4]; sliding 215 N and 341 N on rubber pads [C5]. | Follows the mass. R12 is still met only with the ballast. |
| Stiffness | Unchanged: 0.37 mm under 500 N [D5]. The bays, aprons and rails are the same size and in the same places. | |
| Cost | BOM line 1 (frame) $43.50 to $57.00 [K2]; line 5 $27.80 to $28.20; line 10 $12.00 to $15.00; line 12 $12.00 to $14.00; new line 17, nine worktop brackets, $3.60. Core parts $268.40 [K3]. Value-engineering target: USD 250. Estimated cost of the constructable design: USD 268.40 (USD 18.40 over the target) [K4]. `budget_usd` is unchanged. | Parts added for construction; the budget is a value-engineering target (Amish, 2026-10-01). |
| Drawing | GBN-DWG-001 Rev P4; making sketches GBN-DWG-101 to 116 added. | Follows the model. |
| Documents | GBN-CAL-001 v0.3, GBN-PRC-001 v0.5, GBN-REQ-001 v0.5: mass, stability and cost updated; R10 is now reported against the value-engineering target. No other requirement changed status. | Follows the model. |

*Table 3. Items held back for Amish's decision.*

None of the changes alters what the bench does, its pitch or its safety case, so none is held back. Amish's review of the whole record was the open item; he accepted it as recorded on 2026-10-02.

## Consequences

- `design_state: constructable` in `project.yaml`. The build plan GBN-BLD-001 shows every component and step in pictures generated from the model (`cad/src/build_plan_media.py`).
- Requirement status: R10 is now reported as USD 18.40 over the value-engineering target rather than met; otherwise unchanged (R7 not met at the 122 screw-in positions, R3 and R4 at risk, R5 not verifiable at TRL 3, R1, R2 and R11 met by design, R6, R8, R9 and R12 met on paper).
- The appearance model `cad/src/product_model.py` and the photoreal renders (`media/render-*.png`, made on Amish's Mac) still show the concept fixture positions, post and arm, and have no brackets, bolts or T-nuts. They need updating on the Mac; they are not regenerated here.
- The open decisions of GBN-DDR-001 and GBN-DDR-002 (O1, O3, O4) were decided by Amish on 2026-10-02 and are listed in the register.

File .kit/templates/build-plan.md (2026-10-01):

---
doc_id: PRJ-BLD-001
title: Project prototype build plan
project: Project name
doc_type: Build plan
version: "0.1"
status: Draft
date: YYYY-MM-DD
author: Amish Chadha
license: CERN-OHL-S-2.0
revisions:
  - version: "0.1"
    date: YYYY-MM-DD
    author: Amish Chadha
    change: First build plan; design made constructable
---

# Project prototype build plan

**Plan, not yet built.** How to build the first proof-of-concept prototype, component by component. Building and testing to it is TRL 4 work. Decisions still to be made are kept in the design decisions register (`docs/06-design-decisions.md`), not here.

## 1. What you are building

Every component, pulled apart and numbered in build order

One short paragraph: what the prototype is, how many components, which are made and which are bought, and the main ways they are made.

## 2. What changed to make it buildable

| Component | The concept had | The buildable design has | Why |
| --- | --- | --- | --- |

## 3. Making the components

### 3.1 Component name

Making sketch

**What it is and what it is made from.**

**How to make it.**

1. Mark out ...
2. Cut ...

**How it fits the parts next to it.**

Close-up of the joint

**Check before moving on.**

## 4. Putting it together

### Step 1: ...

Step 1

## 5. First checks

| Check | Requirement | How | Pass when |
| --- | --- | --- | --- |

## 6. Safety stops

## 7. Tools, skills and workspace

## 8. Where the numbers come from

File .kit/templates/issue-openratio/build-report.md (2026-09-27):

---
name: Build report
about: Tell us what happened when you built, printed or tested part of this design
title: "Build report: "
labels: build-report
---

This is a research and educational prototype, not a medical device. It is a TRL 3 concept and is not released for fabrication. If you build any part of it, you do so at your own risk. Reports help everyone.

**What you built** (part, sub-assembly or test)

**Materials, tools and settings**

**What worked**

**What did not work, with photos or measurements if you have them**

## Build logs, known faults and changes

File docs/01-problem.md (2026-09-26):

---
doc_id: GBN-PRB-001
title: GridBench problem statement
project: GridBench
doc_type: Problem statement
version: "0.4"
status: Draft
date: '2026-09-25'
author: Amish Chadha
license: CERN-OHL-S-2.0
revisions:
- version: "0.1"
  date: '2026-09-25'
  author: Amish Chadha
  change: Initial scaffold
- version: "0.2"
  date: '2026-09-25'
  author: Amish Chadha
  change: Populate to TRL 2 (users, context, constraints, prior work, open questions)
- version: "0.3"
  date: '2026-09-25'
  author: Amish Chadha
  change: TRL 3 update; grid choice and budget scope adopted as recommended (GBN-DDR-001), humidity figures sourced
- version: "0.4"
  date: '2026-09-25'
  author: Amish Chadha
  change: Recommendations accepted by Amish (DDR-002)
---

# GridBench problem statement

Small workshops cannot make the same part twice to the same standard without a way to put the part in the same place every time, and the tools that do this well are priced for industry while home-made jigs cannot be shared.

## The problem

Repeatable making depends on fixturing: a datum surface, locating features and clamps that hold each part in a known position while it is drilled, glued, assembled or measured. Industry solves this with modular fixture systems built on a hole grid. A 1,200 x 800 mm welding table from one well-known system, with 16 mm bores on a 50 mm grid, starts at about $2,561 before any clamps or stops ([Siegmund System 16, US distributor listing](https://weldingtablesandfixtures.com/products/4-161025-p-siegmund-1200x800mm-basic-system-16-welding-table)). That is more than ten times the whole prototype budget of this project.

Community workshops, makerspaces and informal engineering clusters instead build one-off jigs from scrap. These work, but each is tied to one bench and one person, is rarely documented, and cannot be sent to another workshop as a file. When a design from the lab's portfolio is built in two places, the two builds differ because the holding and checking steps differ.

The missing piece is an open, cheap, documented grid standard: a bench surface with a fixed hole pattern, a library of printable and machinable fixtures that fit it, and a way to publish a jig as a file that works on any bench built to the same pattern.

## Users and context

| User | Need | Context |
| --- | --- | --- |
| Makerspace or fab lab technician | A shared bench where members can set up a known jig in minutes and check parts | Mixed-skill users, shared tools, 3D printers and often a CNC router |
| Small manufacturer or repair shop | Batch assembly and inspection of 10 to 500 parts without buying an industrial fixture table | Workshop of 1 to 20 people, limited capital |
| Informal-sector artisan cluster | Consistent parts for customers and buyers, with tools made locally | Hand tools, drill press, access to a lathe or shared machine shop |
| Teacher or technical college | A teaching bench that shows datums, location and clamping | Classroom, safety supervision, repeated use by many students |
| Open hardware designer | A way to ship a build jig with a design, as a file | Designs published in repos like this one |

## Operating environment

- Indoor workshop, 10 to 35 °C, 20 to 80 % relative humidity, not air-conditioned in many target regions. Over that humidity range wood settles at about 4.5 to 16 % moisture content ([USDA Forest Products Laboratory, *Wood Handbook*, FPL-GTR-190, Table 4-2](https://www.fpl.fs.usda.gov/documnts/fplgtr/fplgtr190/chapter_04.pdf)), so a plywood top moves with the seasons (GBN-CAL-001, section E).
- Loads from hand assembly, drilling with a hand drill or drill press, light filing and gluing. Not for welding heat or heavy machining forces.
- Users range from trained machinists to first-time makers.

## Constraints

- Garage-buildable prototype, about $250 USD in parts (raised from $220 by Amish on 2026-09-25, GBN-DDR-002) for the bench, grid, tile and fixture set (the dial indicator is user-supplied, GBN-DDR-001 A1), using timber or steel sections, plywood, one aluminum plate and 3D-printed parts.
- Build with common workshop tools: a drill press or hand router with a template, taps and a reamer. A shared CNC router speeds up the worktop but must not be required.
- The grid must be compatible with something already made in volume, so that commercial accessories fit.
- All files open: CAD in build123d source, hardware under CERN-OHL-S-2.0.

## Prior work

- **Metric optical breadboards** use M6 tapped holes on a 25 mm grid; imperial boards use 1/4-20 on 1 in ([RP Photonics Encyclopedia, "Optical breadboards"](https://www.rp-photonics.com/optical_breadboards.html)). This is a mature, precise grid with a large accessory market, but aluminum or steel breadboards of bench size are costly and too fine for rough work.
- **Modular welding and fixture tables** (for example Siegmund System 16, above) use large bores on a 50 mm grid with hardened surfaces. They are precise and robust, but priced for industry.
- **Machinist fixture plates** combine tapped holes with separate reamed dowel positions so that parts locate on pins and clamp on threads; Saunders Machine Works, for example, specifies dowel pin and bore tolerances in the ten-thousandths of an inch ([SMW fixture plate FAQ](https://saundersmachineworks.com/pages/fixture-plate-faq)). GridBench borrows this split of "locate on dowels, clamp on threads".
- **Multifunction woodworking tables** use 20 mm dog holes on a 96 mm pitch ([In The Woodshop, building an MFT](https://www.inthewoodshop.com/Powered%20Tools%20and%20Machinery/BuildingMFT1.html)). Widely copied and cheap, but coarse and not meant for small parts or measurement.
- **Open grid storage systems** show how fast a shared grid spreads when files are free: Gridfinity, designed by Zack Freedman in 2022 on a 42 mm grid ([Wikipedia, "Gridfinity"](https://en.wikipedia.org/wiki/Gridfinity)), and Multiboard on a 25 mm grid for walls ([GridPilot comparison](https://gridpilot.us/blog/gridfinity-vs-multiboard-vs-minutegrid)). Gridfinity's license is non-commercial, which limits use by small businesses. Neither is a fixture or workholding standard.

No open standard found combines a cheap worktop, a precision zone and a fixture library on one grid.

## Out of scope

- Welding tables (heat, spatter and weld current need steel tops).
- Heavy machining (milling forces need a machine table, not a bench).
- Powered or automated fixtures.

## Co-design and validation checklist

- [ ] Identify two or three first user workshops (for example a fab lab, a small repair business, a technical college) and a local partner. Proposed, awaiting Amish.
- [ ] Observe how those workshops hold and check parts today, and list the five most common jigs.
- [ ] Confirm which tools each workshop has (CNC router, drill press, lathe, 3D printer).
- [ ] Agree what "repeatable" means for their parts (target tolerance) before fixing R3 and R4.

## Open questions

- Grid: 25 mm with M6 only at first, with a coarser 50 mm variant for heavy work considered later. Decided by Amish, 2026-09-25: go with recommendation (GBN-DDR-001 A2).
- Which workshops test the first benches, and in which countries? No recommendation made. Proposed, awaiting Amish (GBN-DDR-001 O1).

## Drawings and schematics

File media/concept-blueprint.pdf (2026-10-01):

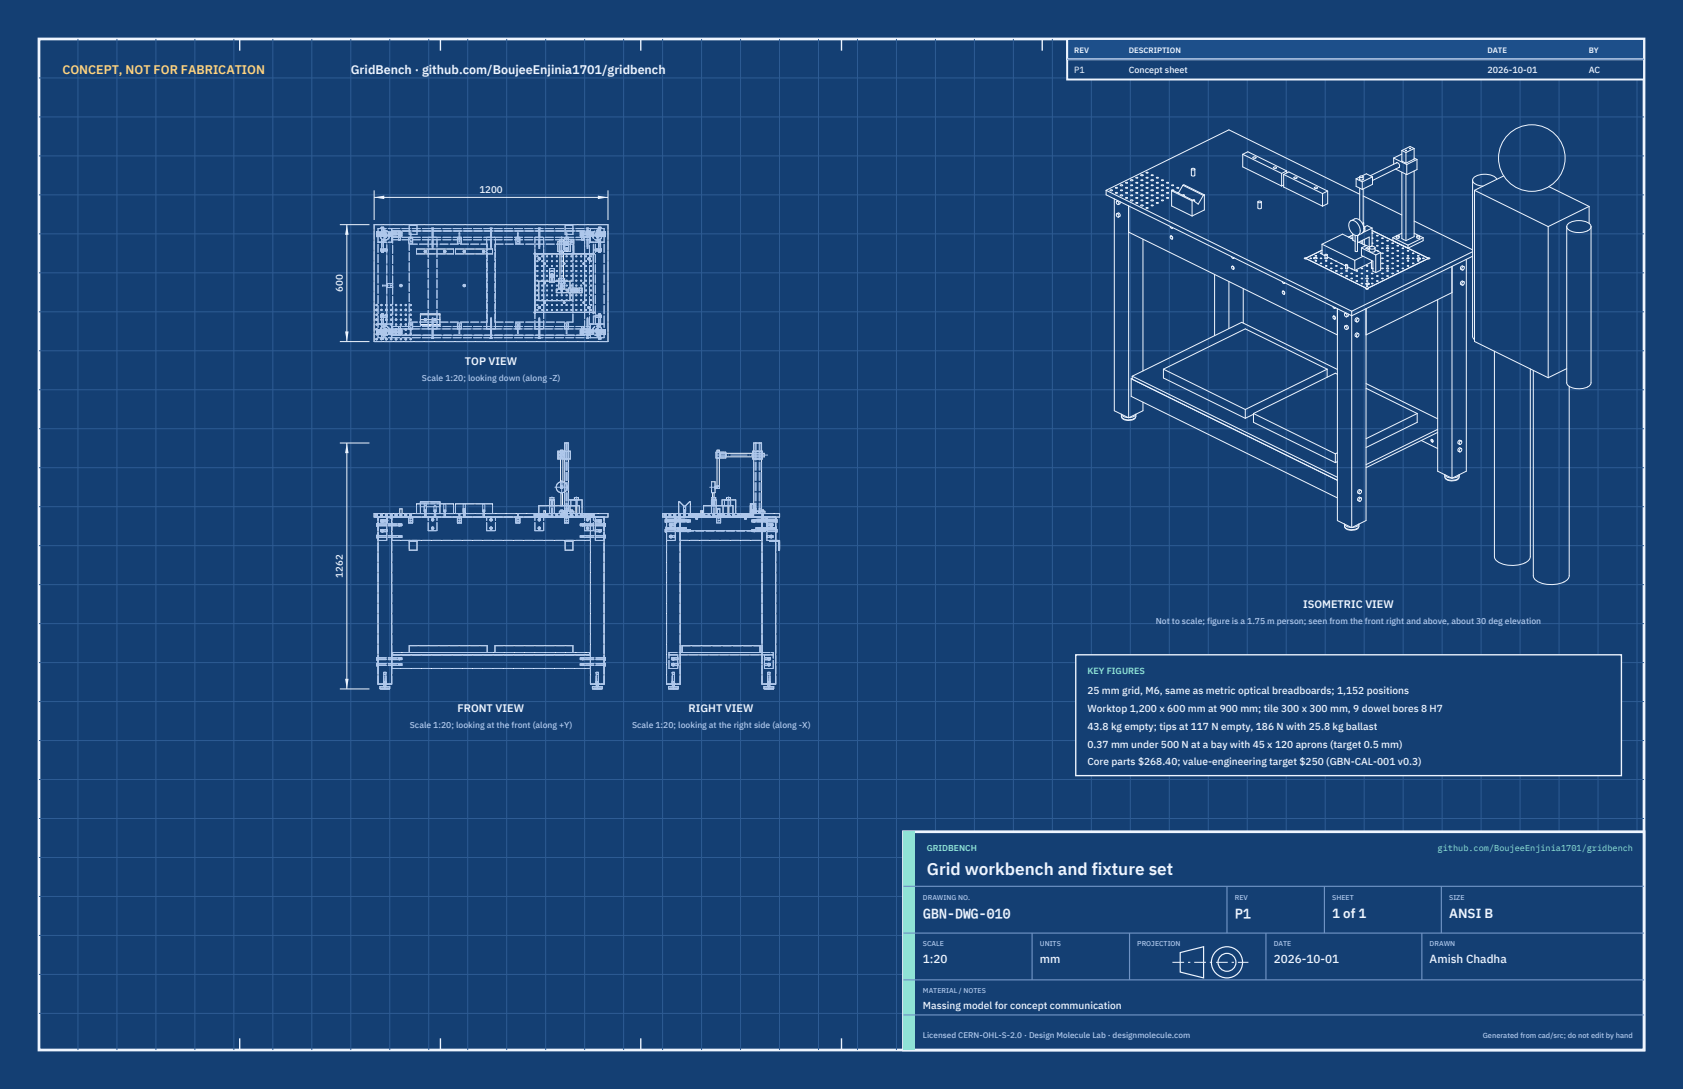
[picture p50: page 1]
CONCEPT, NOT FOR FABRICATION; GridBench · github.com/BoujeeEnjinia1701/gridbench; FRONT VIEW; TOP VIEW; RIGHT VIEW; ISOMETRIC VIEW; REV; DESCRIPTION; DATE; Concept sheet; GRIDBENCH; github.com/BoujeeEnjinia1701/gridbench; DRAWING NO. GBN-DWG-010; REV P1; SHEET 1 of 1; SIZE ANSI B; SCALE 1:20; UNITS mm; PROJECTION; DRAWN Amish Chadha; Licensed CERN-OHL-S-2.0 · Design Molecule Lab · designmolecule.com; Generated from cad/src; do not edit by hand

Scale 1:20; looking down (along -Z)

Not to scale; figure is a 1.75 m person; seen from the front right and above, about 30 deg elevation

KEY FIGURES
25 mm grid, M6, same as metric optical breadboards; 1,152 positions
Worktop 1,200 x 600 mm at 900 mm; tile 300 x 300 mm, 9 dowel bores 8 H7
43.8 kg empty; tips at 117 N empty, 186 N with 25.8 kg ballast
0.37 mm under 500 N at a bay with 45 x 120 aprons (target 0.5 mm)
Core parts $268.40; value-engineering target $250 (GBN-CAL-001 v0.3)

Scale 1:20; looking at the front (along +Y)

Scale 1:20; looking at the right side (along -X)

Grid workbench and fixture set

MATERIAL / NOTES
Massing model for concept communication

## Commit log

2026-09-25 Initial scaffold: standard open hardware layout, CERN-OHL-S v2 + MIT licenses
    Claude-Session: https://claude.ai/code/session_01XuhhSU4W6fYhgCfURbrkut
    [bom.csv]
2026-09-25 Populate to TRL 2: problem, requirements, precis, concept media, BOM and README use cases
    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
    [bom.csv]
2026-09-26 Advance to TRL 3: DDR-001, CAL-001 sizing, parametric model with STEP/STL, GA drawing, priced BOM; TRL 4 on hold
    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
    [bom.csv, gridbench-assembly.step, gridbench-assembly.stl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]
2026-09-26 Accept all recommendations (DDR-002), switch footer to designmolecule.com, add README write-up with new inspiration point
    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
    [bom.csv, gridbench-assembly.step, gridbench-assembly.stl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]
2026-09-27 Product appearance model and photoreal renders
    Adds cad/src/product_model.py (appearance model for renders only, all main
    dimensions from model.py) and Blender renders in media/render-*.png,
    captioned with the project, repository and viewing direction. README leads
    with the product render; trl stays 3.
    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
2026-10-01 Image quality pass: legible exploded views, flow diagrams and drawing sheets
    Kit 1.6.1 image layout: the parts list sits in its own column, number bubbles sit on visible parts and never overlap, small parts get a leader, pictures are cropped to the subject, flow labels keep numbers with their units, and sheet captions and the revision table no longer overprint. Concept images, blueprint and general arrangement sheet regenerated; repo-specific labels moved clear of other text and lines.
2026-10-01 Kit 1.7.0: constructable design, illustrated build plan and design decisions register
    The design is now constructable: every part can be made and fits its neighbours, with each change recorded in a Design for construction decision record (made under Amish's 2026-09-30 instruction; ope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
    FlexHand also credits Dr. Geeti Chadha as a contribut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
    [bom.csv, gridbench-assembly.step, gridbench-assembly.stl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]
2026-10-02 Record Amish's approval of the open-decision recommendations
    Amish approved the recommendation on every open decision in the design decisions register ("i approve your recommendations for all 555 open decisions.", 2026-10-02). Each decision is moved to Decisio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
2026-10-03 Carry approved follow-ups into the design and redo photoreal renders
    Amish approved the follow-up actions from the open-decision sign-off ("APPROVED CHANGES, COMPLETE THESE", 2026-10-02), the design-for-construction change tables in ten repos, the last wave's open dec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
    [bom.csv, gridbench-assembly.step, gridbench-assembly.stl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]

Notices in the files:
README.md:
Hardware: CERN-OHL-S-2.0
